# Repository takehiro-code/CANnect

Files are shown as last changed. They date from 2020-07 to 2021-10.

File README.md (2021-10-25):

# CANnect

Automotive diagnostic application developed as a part of engineering science 2020 capstone group croject. We built the application that diagnoses vehicle performance from On-board diagnostics-II (OBDII) port, and the mobile application displays the performance data with the Bluetooth connection from the hardware module. The dashboard on the mobile app processes the performance data and visualizes it in table, line chart, meter visualization, etc. in real-time. The performance data, which is OBDII parameter IDs (PIDs), includes engine coolant temperature, fuel pressure, engine RPM, vehicle speed, etc.

## System Overview
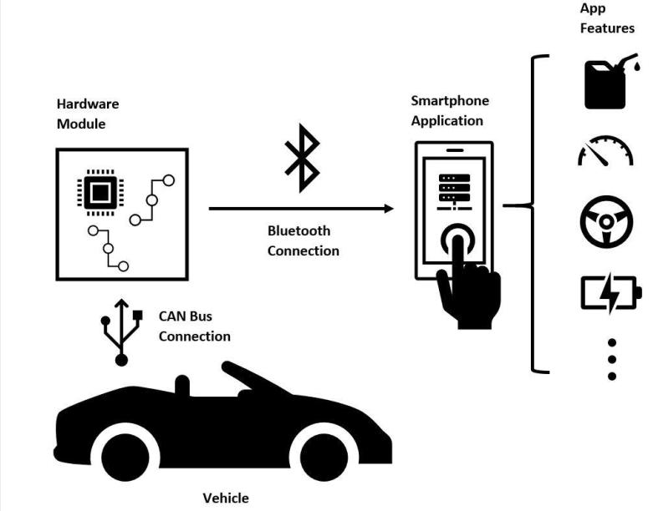
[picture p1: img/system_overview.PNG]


## Mobile App

We developed the mobile application with Android Studio, using Java and XML.

<div class="row">
  <div class="column">
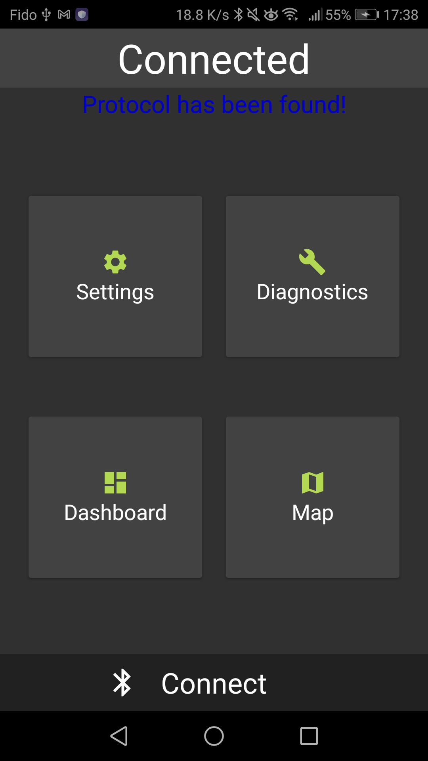
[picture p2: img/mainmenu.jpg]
    
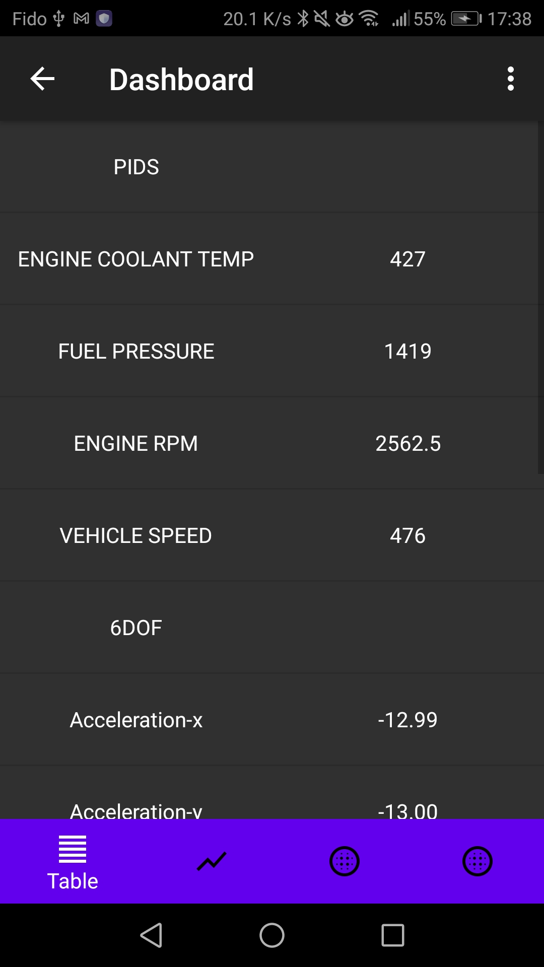
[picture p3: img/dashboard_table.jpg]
    
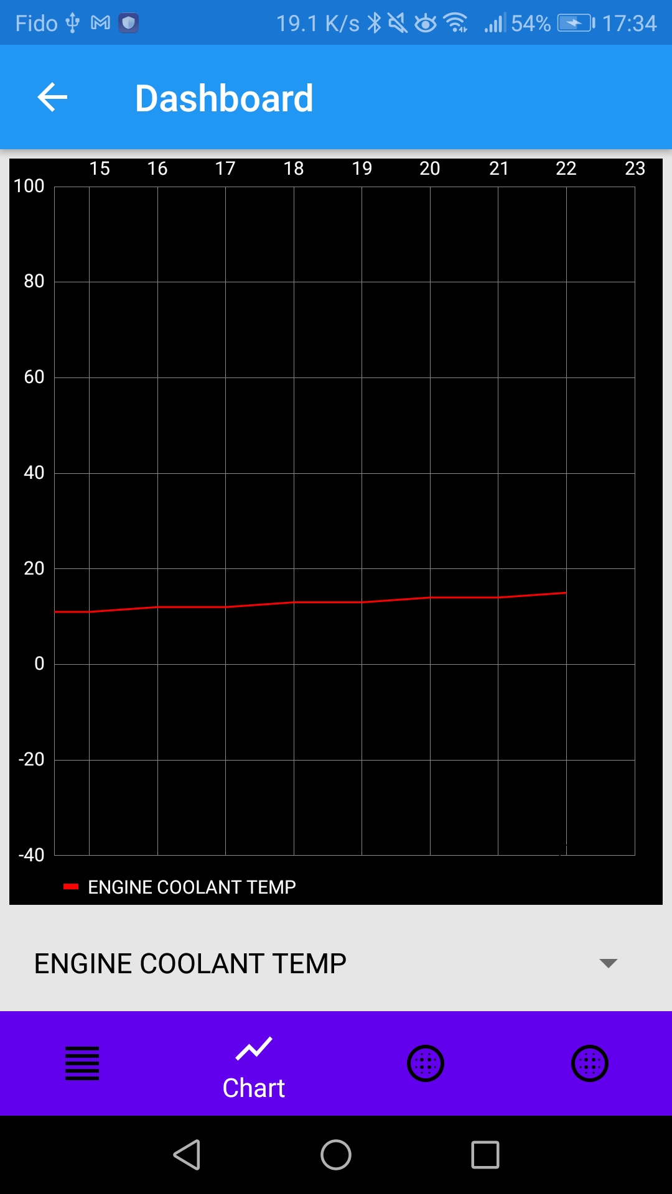
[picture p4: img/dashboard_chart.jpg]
    
  </div>
  <div class="column">
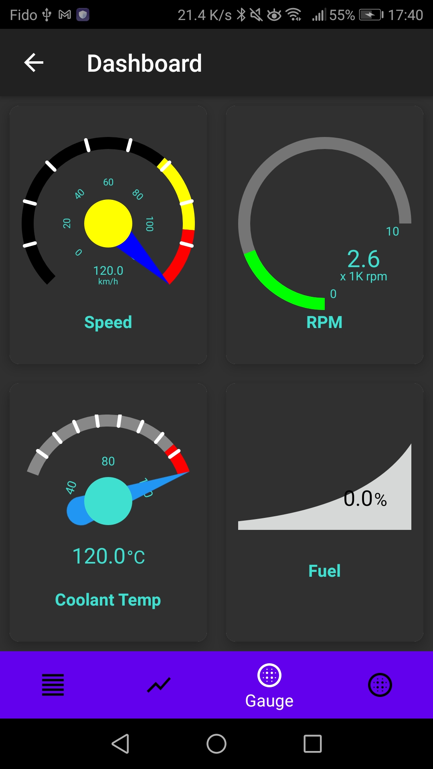
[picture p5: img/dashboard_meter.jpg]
    
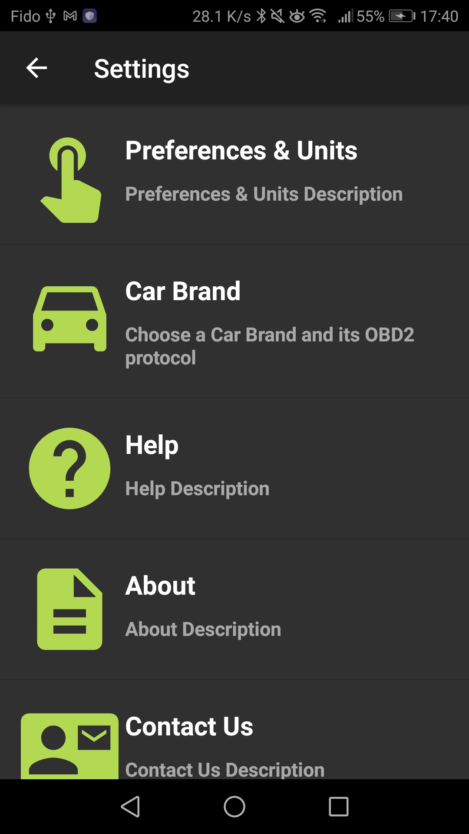
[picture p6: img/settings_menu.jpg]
    
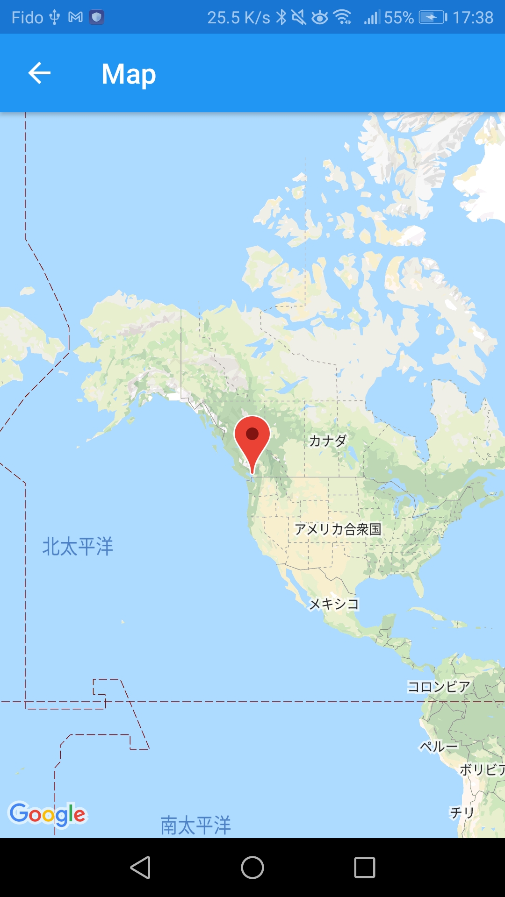
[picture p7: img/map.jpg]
    
  </div>
</div>

## Contributors

- Choong Jin Ng
- Enes Yazici
- Ranjoat Chana
- Win Aung
- Nicholas Lau
- Takehiro Tanaka

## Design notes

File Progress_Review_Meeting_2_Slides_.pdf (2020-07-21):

# Progress Review II

### Group 8:

### Choong Jin Ng Takehiro Tanaka Enes Yazici Win Aung Nicholas Lau

### Ranjoat Chana

### Project Lead App Design Engineer App Design Engineer Hardware Engineer Software Engineer

Systems Engineer,

### Communication Officer

# Agenda

Items for Discussion:
- Approval of the agenda and minutes of first progress review meeting held on June 10th, 2020 (1 min)
- Business arising from the minutes of the previous meeting (1 min)
- Clarification on OBD-II History (1 min)
- Introduction outlining basic review and any changes in scope (1 min)
- Progress, outlining completed research and planning (4 mins)
- Risk and remediations (1.5 mins)
- Summary of current state of project (0.5 min)
- Question period and follow-up discussion (10 mins)

# Approval of Minutes Progress Review Meeting I (June 10th, 2020)

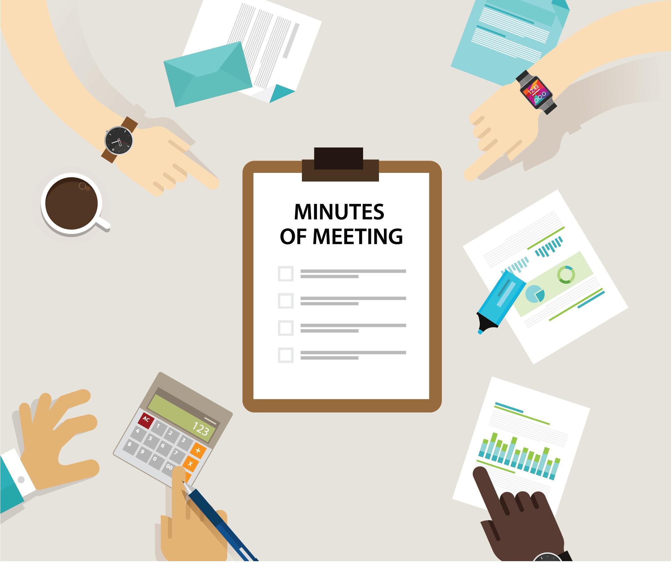
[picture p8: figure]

Revisions as per instructor feedback.

Access:

https://docs.google.com/document/d/11FIjHZPkfOvQZikw2MDsO0bJIYVXZhjqDZQs1nxVHB0/edit# (https://docs.google.com/document/d/11FIjHZPkfOvQZikw2MDsO0bJIYVXZhjqDZQs1nxVHB0/edit#)

# Changes to Previous Meeting Minutes

- Action items are highlighted
- New summary of action items
- Assigned action items to individuals to be held responsible
- The following comments made by participants corrected
- Creative commons licensing
- “Some internal companies”
- “Odometer” feature

# Business Arising

Action: Ranjoat will share a powerpoint with the team to collectively add slides for the next progress review meeting by July 6th (complete)

Action: Jin will verify that Evo car sharing does not block access to OBD-II port for purposes of testing by week of July 6th (complete)

*Action: Jin will research the licensing options for hardware and software by June 14th for requirements document

*Action: Nicholas will research and investigate options for protocols and supported extensions by week of July 6th for design document preparation

*Action: Ranjoat will research adding maintenance features and service updates based on odometer readings in software application by week of July 6th for design document preparation

*research based actions will be further discussed in Progress & Research section

# Clarification on OBD-II Maintenance

- OBD-II does not access actual vehicle’s odometer reading
- Privacy concerns
- Liability issues with mishandling
- Inaccurate
- Most cars that prompt their users to service their cars are not common
- Target audience usually ignores OEM’s scheduled maintenance
■ Too conservative or too generous
- We will not develop a feature that suggests a maintenance to the user

Reference: https://smartcar.com/blog/obd-mileage-verification/

# Clarification on OBD-II History

"CAN bus [...] was officially released in 1986 at the Society of Automotive Engineers (SAE) conference in Detroit, Michigan. [...] CAN bus is one of five protocols used in the on-board diagnostics (OBD)-II vehicle diagnostics standard. The OBD-II standard has been mandatory for all cars and light trucks sold in the United States since 1996. " - Wikipedia

This paragraph is misleading. Wikipedia’s ‘On-board diagnostics’ History implies a different history:

- 1996: The OBD-II specification is made mandatory for all cars sold in the United States.
- | 2008: All cars sold in the United States are required to use the | ISO 15765-4 (https://en.wikipedia.org/w/index.php?title=ISO_15765-4&action=edit&redlink=1)[5] (https://en.wikipedia.org/wiki/On-board_diagnostics#cite_note-5) | signaling standard (a variant of the
Controller Area Network (https://en.wikipedia.org/wiki/Controller_Area_Network) | (CAN) bus). (https://en.wikipedia.org/wiki/Bus_(computing))

Reference: https://en.wikipedia.org/wiki/On-board_diagnostics#History

# Clarification on OBD-II History

- Although CAN was originally developed for passengers cars, CAN was first applied to other systems first (elevators, textile machines, X-ray machine, etc.)
- Most first applications, including cars, were done in Europe
- Although CAN was introduced by Bosch in Feb 1996, there were many problems (errors, incompleteness, political disputes, etc)
- ISO 15765-4 (i.e CAN BUS) was formally specified in 2005.
- All cars manufactured after 2008 in North America should only use CAN (ISO 15765-4)
- When we refer to ‘CAN BUS Reader’, we are talking about an OBD-II reader that works on cars after 2008

Reference:

https://www.can-cia.org/can-knowledge/can/can-history/

https://www.iso.org/standard/33619.html

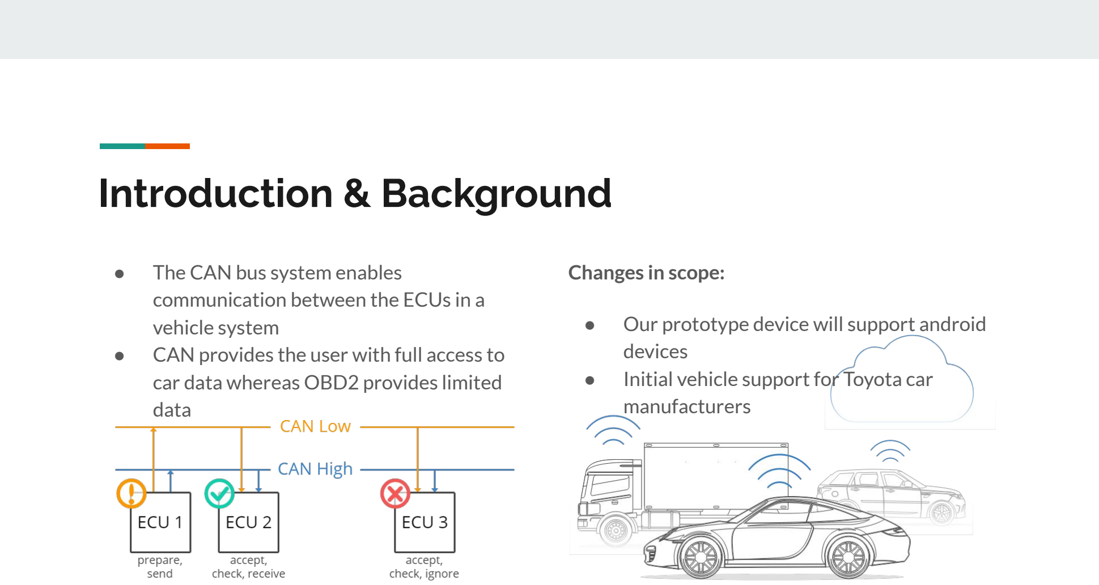
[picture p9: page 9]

# Introduction & Background

- The CAN bus system enables
communication between the ECUs in a vehicle system
- CAN provides the user with full access to car data whereas OBD2 provides limited data

Changes in scope:

- Our prototype device will support android devices
- Initial vehicle support for Toyota car manufacturers

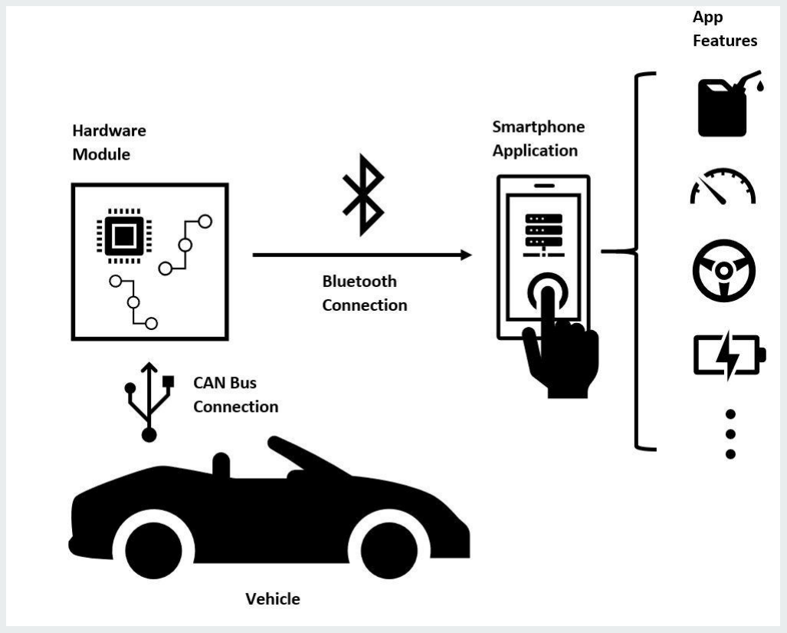
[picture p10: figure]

-Our CANBus reader is designed to connect to the OBD-II port in a vehicle

-The hardware module is comprised of a microcontroller and Bluetooth adapter to process and transmit data from the vehicle CAN bus system (CAN low, CAN high ) to the user’s android device

-The smart phone app will allow the user to read DTCs and live sensor data such as oil temperature, engine speed, GPS, fuel rate and speed, etc.

# System Overview

# Progress & Research - Hardware

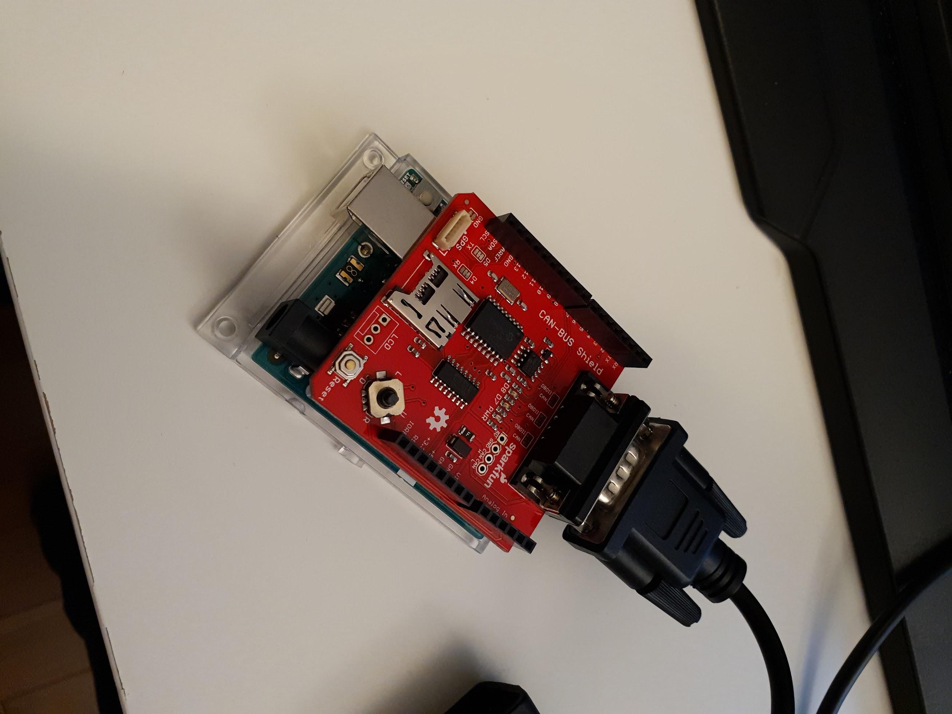
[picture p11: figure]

- Arduino Uno with SparkFun CAN BUS Shield
- Using SparkFun’s internal libraries
- Example code is a useful jumping ground for a Proof-of-Concept
- Connect the CAN BUS Shield to a OBD-II port using a DB9 to OBD-II connector

# Progress & Research - Data Sample

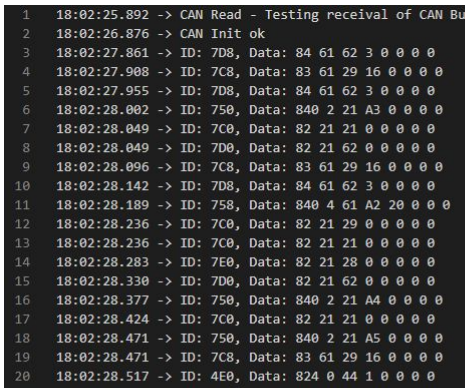
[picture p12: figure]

- Data sample from Toyota Prius (Evo car sharing) using demo code
- Able to read data frames that are sent to the Arduino
- Suspect that not all possible messages are not being read because example code does not request for them

# Progress & Research - Data Sample

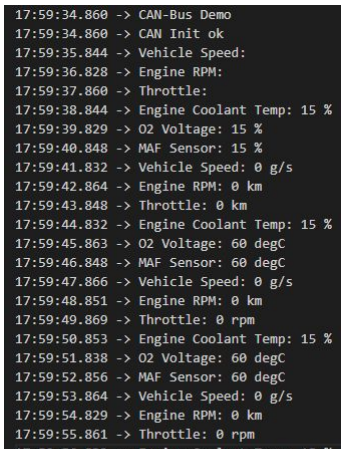
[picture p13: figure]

- Another data sample from Toyota Prius (Evo car sharing) using demo code
- Code requests for
- Vehicle Speed
- Engine RPM
- Throttle
- Engine Coolant Temp
- O2 Voltage
- MAF Sensor
- Promising though highlights the needs to check the data’s validity before displaying

# Progress & Research - Evo Car Sharing

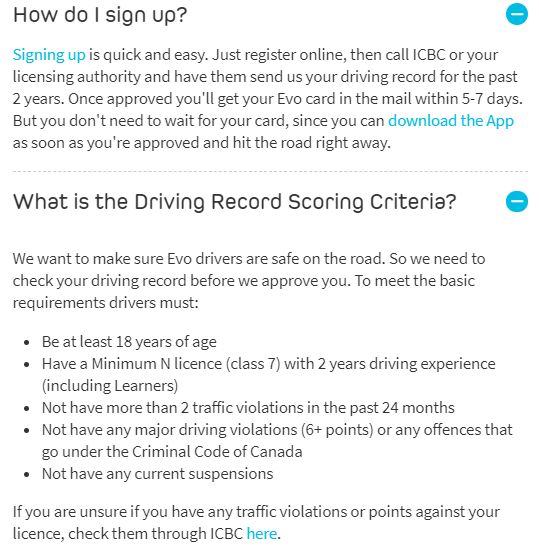
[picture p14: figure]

- Advantages
- Able to test on a standardised car
■ Toyota Prius
- Available through the Lower Mainland
- Low operating rates
- Disadvantages
- Need a valid driving license (Class 7 or N at minimum)
- Need to have 2 years of driving experience
- Not convenient for bursts of development and testing
- Alternative solution (CAN BUS Simulator) is more convenient

# Progress & Research - Protocols

Research - Protocols (CANBUS)

The listed ISO standard is the intended focus protocol for CANBUS

- ISO 15765-4 - Emissions and external data access (Diagnostic Communication over CAN)
- ISO 11898 series- Physical and Data Link Layers (frame format)
■ | Part 1 - Physical and Data Link Layer
■ | Part 2 - High Speed Transmission
- ISO 15765-2 - Network and Transport Layer
- Also implemented in ISO 27145-4 for WWH-OBD

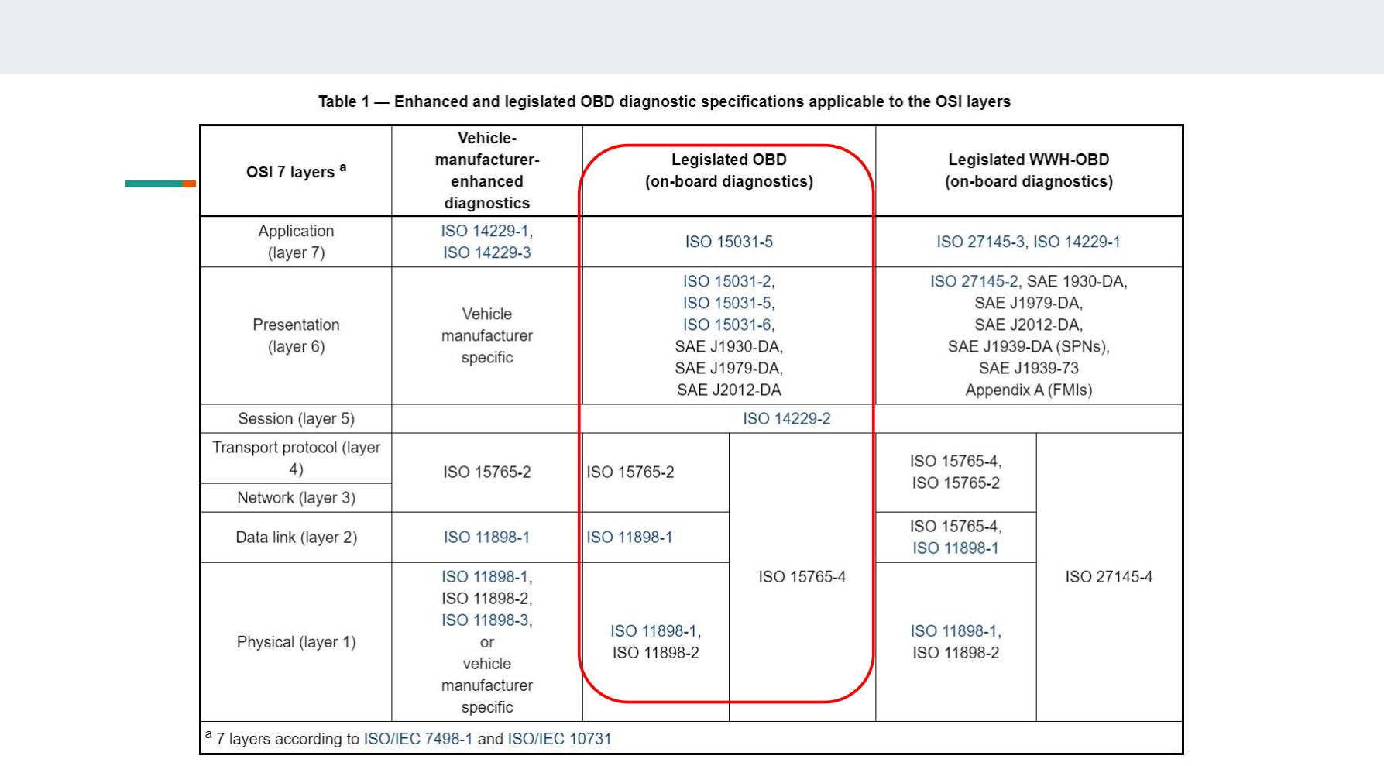
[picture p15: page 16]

# Progress & Research - CAN Data

Research - CAN IDs and Messages

Depending on car, messages are either read automatically in intervals or must be requested manually

Identified different ways to decode CAN message format since it proprietary to Original Equipment manufacturer (OEM):

- Reverse Engineer
- Perform different actions on car to see which IDs correlate to a specific function
- Tedious and time consuming
- Look-up CAN IDs
- Identified a subset of IDs for Toyota cars (eg. vehicle speed, RPM)
- Fast and convenient

# Progress & Research - Data

CAN - Raw Data Sample and Translation

ID: 610, Data: 820 0 0 64 C2 0 0 0

HEX 610 - Vehicle Speed

HEX 0 (Byte 3) - 0 km/h

ID: 63B, Data: 816 0 43 4E 0 0 2 7F

Unknown, Need further research or reverse engineering

# Progress & Research - Bluetooth

### Bluetooth Modules

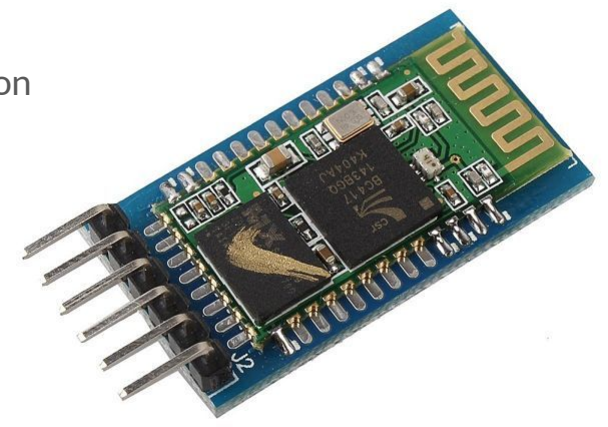
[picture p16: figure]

- HC-05 -based on Bluetooth 2.0 and offers master/slave configuration
- HC-06 -based on Bluetooth 2.0 and offers only slave configuration
- Both HC-05 and HC-06 are compatible with android devices only
- HM-10/HM-11 -based on Bluetooth 4.0 BLE
- compatible with iphone and android 4.3+
- intended for low power consumption applications

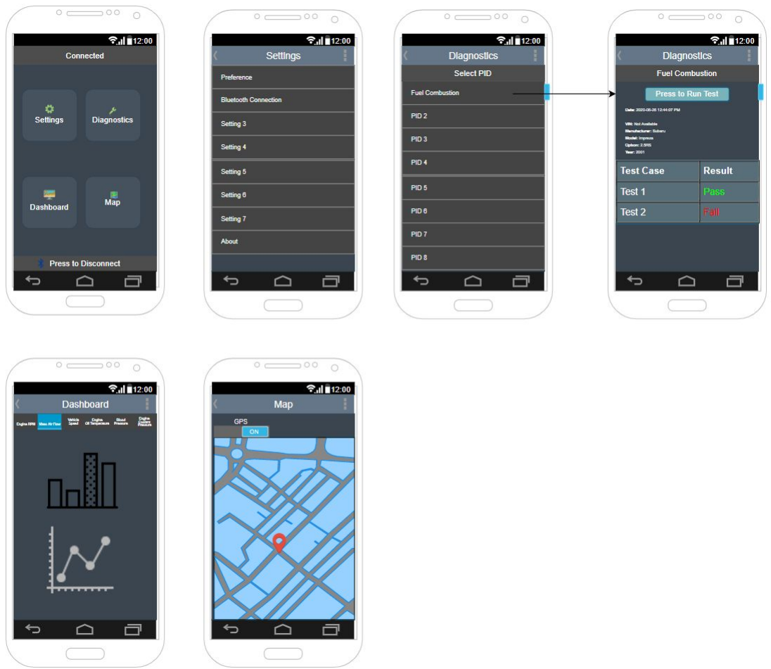
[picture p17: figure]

# Progress & Research - App

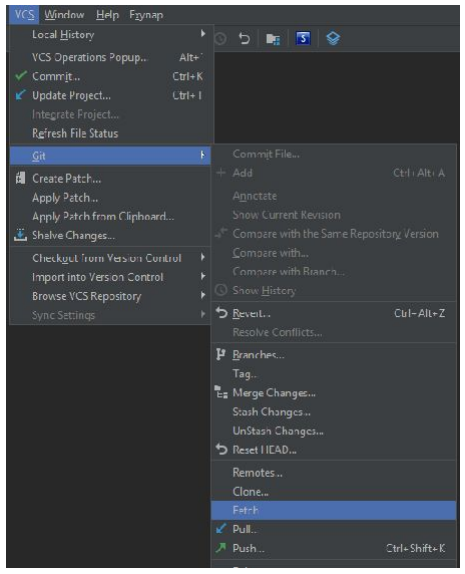
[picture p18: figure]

# Progress & Research - App

### App Planning

- Android Studio
- XML, Java, Git
- Test on different devices (e.g. Screen)
- Physical device
- Virtual device (Emulator)

# Progress & Research - App

### Design Choices

- Easy to use (no difficult learning curve for users)
- Seperate tabs makes development easier
- Separate XML activities and Java classes(no dependency between different functionalities)
- More organized

### Colour & Image Choices

- Do not use a colour that is too bright
- May hurt eyes & Annoying
- Use common color and icon associations (green for connect, red for disconnect etc.)

# Progress & Research - App

### Software App Progress

- Currently
- Converting sketches to app ui
- Built the app basic display (main screen only)
- Working on the logical components
- Enabling bluetooth, searching devices, pairing devices etc.
- Next steps
- Attach to arduino to receive data
- Parse the data
- Implement Individual UI components ( dashboard, chart, map etc)

# Risk and Remediation - Scheduling

- To aid scheduling
- Planning to meet up in person for hardware setup of prototype design
- Regular meetings and discussion over online
- Reallocate resources as required for hardware and software component

# Risk and Remediation - CAN BUS Simulator

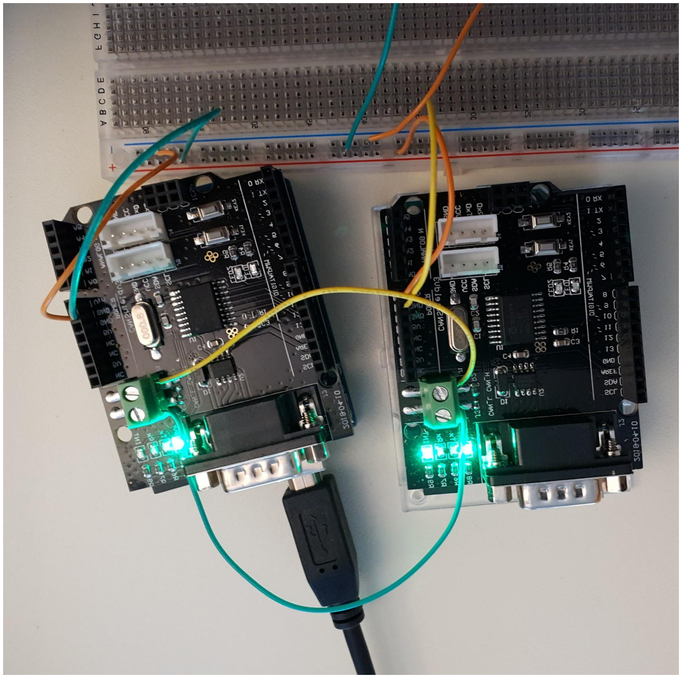
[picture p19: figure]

- Use another Arduino and CAN BUS Shield to act as a “car simulator”
- CAN-High connects to CAN-High, and CAN-Low connects to CAN-low
- Run a pre-defined script that simulates how the car’s internal CAN BUS system works
- Sends the appropriate messages to the reader when requested

# Risk and Remediation - CAN BUS Simulator

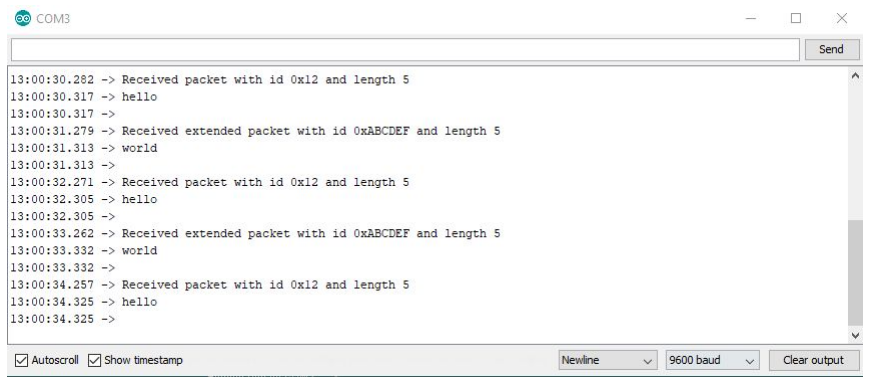
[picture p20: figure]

- Sender sends the string ‘hello’ and ‘world’ to the reader
- Reader simply prints the packet’s contents to serial
- Future work will enable those who do not have cars to work at home
- Also able to have repeatable verification tests

# Risk and Remediation - Licensing

- Hardware and related documents falls under CERN Open Hardware License Version 2 -Permissive
- Referred to as CERN-OHL-P
- Only applies to hardware and its associated documentation
- Software and related documents falls under MIT License
- Goal of this product is to make working on your car easier, not necessarily to turn a profit
- Customers prefer to stick with official vendors and active customer support

# Summary

Current State:

- Arduino CAN bus shield and demo code has allowed for successful connection to test vehicles to extract data frame samples
- Basic app components and main screen options determined
- Familiarized with the protocols and standards (incl. licensing) for our prototype design
- Determined best practice to verify our product using a simulator
- Evo car sharing is an option

# Summary

Next Steps:

- Working towards finalizing the UI design and functionality
- Establish a connection with the android phone via selected bluetooth module
- Ensure app is correctly mapping data samples to selected features for prototype design stage

# Questions?

# Thank You

# Appendix: Clarification on OBD-II History

- A (modern) OBD-II vehicle uses the five communication protocols:
- SAE J1850 PWM
- SAE J1850 VPW
- ISO 9141-2
- ISO 14230-4
- ISO 15765-4/SAE J2480 (since 2003) - i.e CAN

Reference: http://www.obdtester.com/obd2_protocols

# Appendix: Clarification on OBD-II History

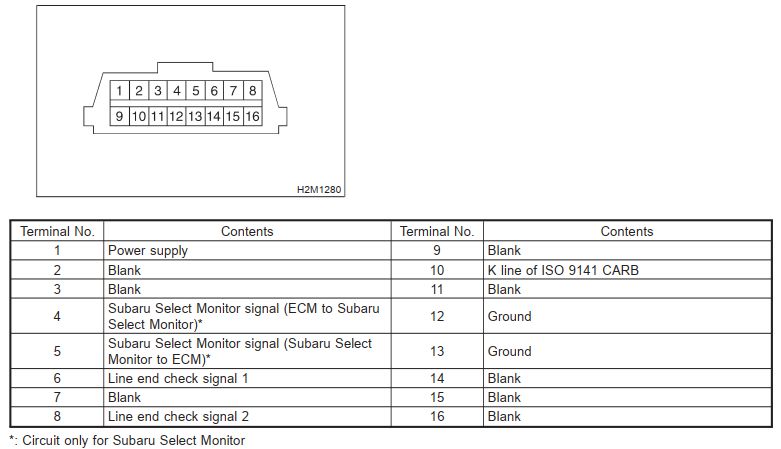
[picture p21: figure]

- Even then, not every car uses all five communication
protocols
- This OBD-II diagram is taken from a service manual for a Subaru Impreza 1996-2001
sold in North America
- Note that only ODB- II’s ISO 9141 is used
- Data collected by an OBD-II reader is slower than CAN
BUS

# Appendix: Progress & Research - Protocols

Research - Protocols (CANBUS)

Additional listed ISO standards are of focus for OBD2 PID-related data

- ISO 14229-2 - Session Layer (Unified Diagnostic Services)
- ISO 15031-2, -5, -6 - Application and Presentation Layer
- Part 2 - Definitions and Terms
- Part 5 - Emissions Diagnostic Services (OBD2 PIDs)
- Part 6 - Diagnostic Trouble Codes
- Based on SAE J1930-DA, J1979-DA and J2012-DA OBD

# Appendix: Progress & Research - Protocols

The International Organization for Standardization, "ISO 15765-4:2016(en), Road vehicles — Diagnostic communication over Controller Area Network (DoCAN) — Part 4: Requirements for emissions-related systems," 2016. [Online]. Available: https://www.iso.org/obp/ui/#iso:std:iso:15765:-4:ed-3:v1:en. [Accessed 2 July 2020].

- Intended network stack is the legislated OBD
- Additional manufacturer specific codes will need to be identified

# Appendix: Progress & Research - OBD-II

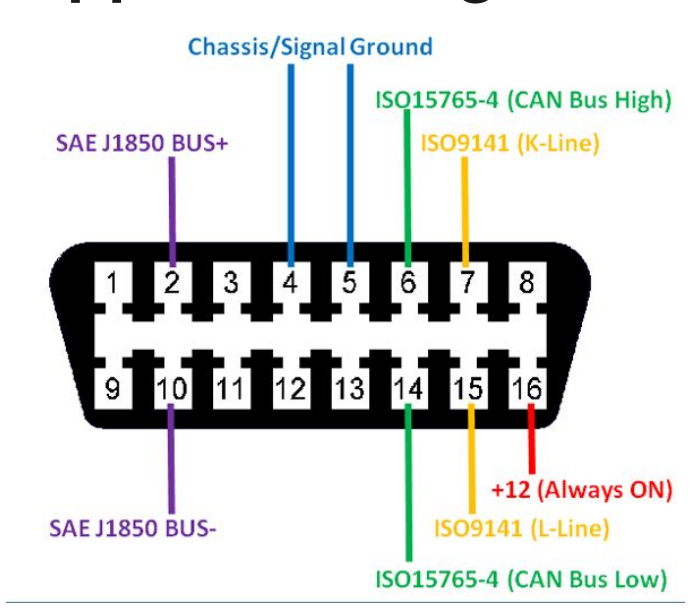
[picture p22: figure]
Connector

- The important data lines we will use are pins 6 and 14 (CAN High and CAN Low respectively)
- We will also use Pins 12 and 4 to power the reader
- Pin 4 and 5 is Chassis and Signal Ground respectively

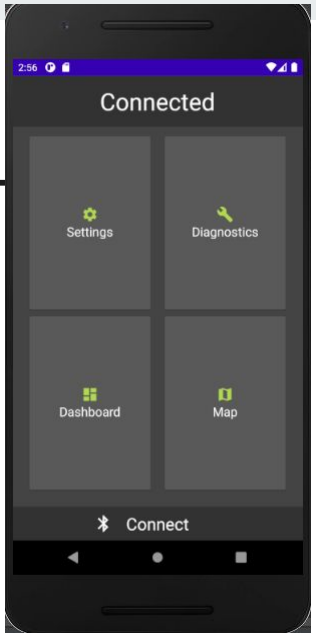
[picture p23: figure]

# Appendix: Progress & Research - App

### Current version of the app

- Status bar on the top
- Logic needs to be added
- Connection bar on the bottom
- Logic needs to be added
- Card view layout implemented
- Needs to be adjusted (padding etc.)
- Logic needs to be added

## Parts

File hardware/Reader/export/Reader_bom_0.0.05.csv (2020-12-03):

Component | Description | Part | References | Value | Footprint | Quantity Per PCB | Datasheet | Vendor | Part Name | digikeypn | Manufacturer | Comments | Field4 | Field6 | Field5
1 | Unpolarized capacitor | C | C_STN_2 C_STN_3 | 30pF | CAPC1608X90N | 2 | https://content.kemet.com/datasheets/KEM_C1007_X8R_ULTRA_150C_SMD.pdf | DigiKey Canada | C0603C300J5GACTU | 399-9057-1-ND | Kermet
2 | Unpolarized capacitor | C | C_HSCAN_1 C_HSCAN_2 | 560pF | CAPC1608X90 | 2 | https://www.yageo.com/upload/media/product/productsearch/datasheet/mlcc/UPY-GPHC_X7R_6.3V-to-50V_18.pdf | DigiKey Canada | CC0603JRX7R9BB561 | 311-4020-1-ND‎ | Yageo
3 | Unpolarized capacitor | C | C_ESP_1 C_ESP_2 C_J1850_1 C_VR1_2 C_VR2_2 C_VS_1 | 0.1uF | CAPC1608X90 | 6 | https://www.yageo.com/upload/media/product/productsearch/datasheet/mlcc/UPY-GPHC_X7R_6.3V-to-50V_18.pdf | DigiKey Canada | CC0603JRX7R8BB104 | 311-1777-1-ND | Yageo
4 | Unpolarized capacitor | C | C_IMU_1 C_IMU_2 | 100nF | CAPC1608X90N | 2 | https://product.tdk.com/info/en/catalog/datasheets/mlcc_commercial_midvoltage_en.pdf | DigiKey Canada | C1608X7R2A103K080AA | 445-1304-1-ND | TDK Corporation
5 | Unpolarized capacitor | C | C_HSCAN_3 C_STN_1 C_STN_4 C_STN_5 C_STN_6 C_VR1_3 C_VR2_3 | 1uF | 0603 | 7 | https://content.kemet.com/datasheets/KEM_C1002_X7R_SMD.pdf | DigiKey Canada | C0603C105K4RACTU | 399-7847-1-ND | Kermet
6 | Unpolarized capacitor | C | C_PS_1 C_PS_2 C_PS_3 C_VR1_1 C_VR2_1 | 4.7uF | C1206C475K3RACAUTO | 5 | https://api.kemet.com/component-edge/download/specsheet/C1206C475K3RACAUTO.pdf | DigiKey Canada | C1206C475K3RACAUTO | 399-7029-1-ND | Kermet
7 | Polarized capacitor | CP | CP_ESP_1 | 100uF | UCB0J101MCL1GS | 1 | https://www.nichicon.co.jp/english/products/pdfs/e-ucb.pdf | DigiKey Canada | UCB0J101MCL1GS | 493-9357-1-ND | Nichicon
8 | Polarized capacitor | CP | CP_STN_1 | 10uF | CP_Elec_4x5.8 | 1 | https://industrial.panasonic.com/ww/products/capacitors/aluminum-capacitors/aluminum-cap-smd/models/EEEFP1E100AR | DigiKey Canada | EEEFP1E100AR | PCE4539CT-ND | Panasonic Electronic Components | ESR<1
9 | 100V 0.15A Small Signal Schottky Diode, DO-35 | BAT46 | D_J1850_1 D_J1850_2 D_J1850_3 D_VS_1 D_VS_2 | BAT46JFILM | BAT46JFILM | 5 | https://www.st.com/content/ccc/resource/technical/document/datasheet/c6/32/d4/4a/28/d3/4b/11/CD00004930.pdf/files/CD00004930.pdf/jcr:content/translations/en.C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 | DigiKey Canada | BAT46JFILM | 497-6653-1-ND | STMicroelectronics
10 |  | MMBZ27VALT3G | D_ESD_4 D_ESD_5 | MMBZ27VALT3G | SOT95P237X111-3N | 2 | https://www.onsemi.com/pub/Collateral/MMBZ5V6ALT1-D.PDF | DigiKey Canada | MMBZ27VALT3G | MMBZ27VALT3GOSCT-ND | ON Semiconductor |  | 20 | ON Semiconductor | IPC-7351B
11 |  | MMBZ27VCLFHT116 | D_ESD_3 | MMBZ27VCLFHT116 | MMBZ27VCLFHT116 | 1 | http://rohmfs.rohm.com/en/products/databook/datasheet/discrete/diode/zener/mmbz27vclfht116-e.pdf | DigiKey Canada | MMBZ27VCLFHT116 | MMBZ27VCLFHT116CT-ND | Rohm Semiconductor
12 |  | PESD2CAN,215 | D_ESD_1 D_ESD_2 | PESD2CAN,215 | SOT95P230X110-3N | 2 | https://assets.nexperia.com/documents/data-sheet/PESD2CAN.pdf | DigiKey Canada | PESD2CAN,215 | 1727-3891-1-ND | Nexperia USA Inc.
13 |  | 4157 | J_CN_1 J_ESP_1 J_ESP_2 | 4157 | PinSocket_1x20_P2.54mm_Vertical | 3 | https://media.digikey.com/pdf/Data%20Sheets/Adafruit%20PDFs/4157_Web.pdf | DigiKey Canada | 4157 | 1528-2929-ND | Adafruit Industries LLC
14 |  | Header_Pin_2 | J_STN_1 J_STN_2 J_STN_4 J_STN_5 J_STN_6 | Header_Pin_2 | PinHeader_1x02_P2.54mm_Vertical | 5
15 |  | Header_Pin_8 | J_ESP_3 J_PS_1 | Header_Pin_8 | PinHeader_1x08_P2.54mm_Vertical | 2
16 | Inductor | L | L_VR1 L_VR2 | 4.7uH | CV201210-4R7K | 2 | https://www.bourns.com/docs/Product-Datasheets/CV201210.pdf | DigiKey Canada | CV201210-4R7K | CV201210-4R7KCT-ND | Bourns Inc.
17 | Light emitting diode | LED | LED_ESP_1 | Bluetooth Status | LED_0603_1608Metric | 1 | https://www.we-online.de/katalog/datasheet/150060VS75000.pdf | DigiKey Canada | 150060VS75000 | 732-4980-1-ND | Würth Elektronik
18 | Light emitting diode | LED | LED_STN_3 | Host Activity | LED_0603_1608Metric | 1 | https://www.we-online.de/katalog/datasheet/150060VS75000.pdf | DigiKey Canada | 150060VS75000 | 732-4980-1-ND | Würth Elektronik
19 | Light emitting diode | LED | LED_STN_2 | OBD Activity | LED_0603_1608Metric | 1 | https://katalog.we-online.de/led/datasheet/150060YS75000.pdf | DigiKey Canada | 150060YS75000 | 732-4981-1-ND | Würth Elektronik
20 | Light emitting diode | LED | LED_STN_1 | Status | LED_0603_1608Metric | 1 | https://katalog.we-online.de/led/datasheet/150060RS75000.pdf | DigiKey Canada | 150060RS75000 | 732-4978-1-ND | Würth Elektronik
21 |  | IRLML5103TRPBF | Q_ISO_1 Q_ISO_2 | IRLML5103TRPBF | IRLML5103TRPBF | 2 | https://www.infineon.com/dgdl/irlml5103pbf.pdf?fileId=5546d462533600a401535668505d2617 | DigiKey Canada | IRLML5103TRPBF | IRLML5103PBFCT-ND | Infineon Technologies
22 | 0.2A Ic, 40V Vce, Small Signal NPN Transistor, SOT-23 | MMBT3904 | Q_ISO_3 Q_ISO_4 | MMBT3904WT1G | SOT-23 | 2 | https://www.onsemi.com/pub/Collateral/MMBT3904WT1-D.PDF | DigiKey Canada | MMBT3904WT1G | MMBT3904WT1GOSCT-ND | ON Semiconductor
23 |  | NX7002AK,215 | Q_HSCAN_1 Q_J1850_1 Q_J1850_2 Q_J1850_4 Q_PS_1 | NX7002AK,215 | SOT95P230X110-3N | 5 | https://assets.nexperia.com/documents/data-sheet/NX7002AK.pdf | DigiKey Canada | NX7002AK,215 | 1727-1289-1-ND | Nexperia USA Inc. |  | Nexperia | IPC-7351B | 7
24 |  | IRLML5103TRPBF | Q_PS_2 Q_PS_3 Q_PS_4 | NX7002AK,215 | SOT95P230X110-3N | 3 | https://assets.nexperia.com/documents/data-sheet/NX7002AK.pdf | DigiKey Canada | NX7002AK,215 | 1727-1289-1-ND | Nexperia USA Inc.
25 |  | RSC002P03T316 | Q_J1850_3 | RSC002P03T316 | RSC002P03T316 | 1 | http://rohmfs.rohm.com/en/products/databook/datasheet/discrete/transistor/mosfet/rsc002p03-e.pdf | DigiKey Canada | RSC002P03T316 | RSC002P03T316CT-ND | Rohm Semiconductor
26 | Resistor | R | R_STN_12 | 10 | RESC1608X55N | 1 | https://www.yageo.com/upload/media/product/productsearch/datasheet/rchip/PYu-RE_105_RoHS_L_6.pdf | DigiKey Canada | RE0603FRE0710RL | 13-RE0603FRE0710RLCT-ND | Yageo
27 | Resistor, small symbol | R_Small | R_HSCAN_2 R_HSCAN_3 | 100 | RESC3216X70N | 2 | https://industrial.panasonic.com/cdbs/www-data/pdf/RDA0000/AOA0000C304.pdf | DigiKey Canada | ERJ-8ENF1000V | P100FCT-ND | Panasonic Electronic Components
28 | Resistor, small symbol | R_Small | R_J1850_6 | 240 | RESC3216X70N | 1 | https://industrial.panasonic.com/cdbs/www-data/pdf/RDA0000/AOA0000C304.pdf | DigiKey Canada | ERJ-8ENF2400V | P240FCT-ND | Panasonic Electronic Components
29 | Resistor, small symbol | R_Small | R_STN_1 R_STN_2 R_STN_3 | 330 | RESC3216X70N | 3 | https://industrial.panasonic.com/cdbs/www-data/pdf/RDA0000/AOA0000C304.pdf | DigiKey Canada | ERJ-8ENF3300V | P330FCT-ND | Panasonic Electronic Components
30 | Resistor, small symbol | R_Small | R_J1850_4 | 374 | RESC3216X70N | 1 | https://industrial.panasonic.com/cdbs/www-data/pdf/RDA0000/AOA0000C304.pdf | DigiKey Canada | ERJ-8ENF3740V | P374FCT-ND | Panasonic Electronic Components
31 | Resistor, small symbol | R_Small | R_ESP_2 R_ESP_3 R_ESP_5 R_STN_10 | 500 | RESC1508X55N | 4 | https://www.vishay.com/docs/28916/mcxhp.pdf | DigiKey Canada | MCT0603PD4990DP500 | 749-1523-1-ND | Vishay
32 | Resistor, small symbol | R_Small | R_J1850_3 | 866 | RESC3216X70N | 1 | https://industrial.panasonic.com/cdbs/www-data/pdf/RDA0000/AOA0000C304.pdf | DigiKey Canada | ERJ-8ENF8660V | P866FCT-ND | Panasonic Electronic Components
33 | Resistor, small symbol | R_Small | R_ISO_1 R_ISO_2 R_STN_4 | 1k | RC1608F102CS | 3 | https://media.digikey.com/pdf/Data%20Sheets/Samsung%20PDFs/RC_Series_ds.pdf | DigiKey Canada | RC1608F102CS | 1276-3484-1-ND | Samsung Electro-Mechanics
34 | Resistor, small symbol | R_Small | R_J1850_2 R_STN_7 R_STN_8 | 1.5k | RESC1607X60N | 3 | https://www.yageo.com/upload/media/product/productsearch/datasheet/rchip/PYu-RC_Group_51_RoHS_L_11.pdf | DigiKey Canada | RC0603FR-071K5L | 311-1.50KHRCT-ND | Yageo
35 | Resistor, small symbol | R_Small | R_COMP_8 | 2.7k | RESC1608X55N | 1 | https://www.vishay.com/docs/28773/crcwce3.pdf | DigiKey Canada | CRCW06032K70FKEAC | 541-5328-1-ND | Vishay Dale
36 | Resistor, small symbol | R_Small | R_IMU_1 R_IMU_2 | 4.7k | RESC1608X55N | 2 | https://www.yageo.com/upload/media/product/productsearch/datasheet/rchip/PYu-RT_1-to-0.01_RoHS_L_12.pdf | DigiKey Canada | RT0603DRD074K7L | 311-4.7KDCT-ND | Yageo
37 | Resistor, small symbol | R_Small | R_COMP_1 R_COMP_2 R_COMP_3 R_COMP_4 R_COMP_5 R_COMP_6 R_COMP_7 R_COMP_9 R_COMP_10 R_COMP_11 R_ESP_1 R_ESP_4 R_J1850_1 R_J1850_5 R_J1850_7 R_J1850_8 R_STN_11 R_VS_2 | 10k | RESC1608X55N | 18 | https://www.yageo.com/upload/media/product/productsearch/datasheet/rchip/PYu-RT_1-to-0.01_RoHS_L_12.pdf | DigiKey Canada | RT0603FRE0710KL | YAG2321CT-ND | Yageo
38 | Resistor, small symbol | R_Small | R_VS_1 | 62k | RESC2012X60N | 1 | https://www.yageo.com/upload/media/product/productsearch/datasheet/rchip/PYu-RT_1-to-0.01_RoHS_L_12.pdf | DigiKey Canada | RT0805FRE0762KL | 13-RT0805FRE0762KLCT-ND | Yageo
39 | Resistor, small symbol | R_Small | R_HSCAN_1 R_PS_1 R_PS_2 R_STN_5 R_STN_6 R_STN_9 R_STN_13 R_VR2_1 R_VR2_2 | 100k | RESC1608X55N | 9 | https://www.yageo.com/upload/media/product/productsearch/datasheet/rchip/PYu-RT_1-to-0.01_RoHS_L_12.pdf | DigiKey Canada | RT0603DRE07100KL | 311-2395-1-ND | Yageo
40 | Resistor, small symbol | R_Small | R_VR2_3 | 115k | RESC1608X55N | 1 | https://www.yageo.com/upload/media/product/productsearch/datasheet/rchip/PYu-RT_1-to-0.01_RoHS_L_12.pdf | DigiKey Canada | RT0402DRE07115KL | 311-2218-1-ND | Yageo
41 | Resistor, small symbol | R_Small | R_ISO_3 R_ISO_4 | 510k | RESC2012X50N | 2 | https://www.susumu.co.jp/common/pdf/n_catalog_partition05_en.pdf | DigiKey Canada | RR1220P-514-D | RR12P510KDCT-ND | Susumu
42 |  | PTS647SK38SMTR2LFS | SW_ESP_1 SW_ESP_2 SW_STN_1 | PTS647SK38SMTR2LFS | PTS647SK38SMTR2LFS | 3 | https://www.ckswitches.com/media/2567/pts647.pdf | DigiKey Canada | PTS 647 SK38 SMTR2 LFS | PTS647SK38SMTR2LFSCT-ND | C&K
43 |  | AHDF15A-KG-TAXB | U_CN_1 | AHDF15A-KG-TAXB | AHDF15A-KG-TAXB | 1 | http://www.assmann-wsw.com/fileadmin/datasheets/AHDxxxA-KG-TAxB.pdf | DigiKey Canada | AHDF15A-KG-TAXB | AE11024-ND | Assmann WSW Components
44 | RF Module, ESP32-D0WD SoC, Wi-Fi 802.11b/g/n, Bluetooth, BLE, 32-bit, 2.7-3.6V, onboard antenna, SMD | ESP32-WROOM-32D | U_ESP_1 | ESP32-WROOM-32D | CANtech-ESP32-WROOM-32 | 1 | https://www.espressif.com/sites/default/files/documentation/esp32-wroom-32d_esp32-wroom-32u_datasheet_en.pdf | DigiKey Canada | USB4110-GF-A | 1965-ESP32-WROOM-32D(4MB)CT-ND | Espressif Systems
45 |  | LM317LDR2G | U_J1850_1 | LM317LDR2G | SOIC127P600X175-8N | 1 | https://www.onsemi.com/pub/Collateral/LM317L-D.PDF | DigiKey Canada | LM317LDR2G | LM317LDR2GOSCT-ND | ON Semiconductor
46 |  | LM339N_NOPB | U_COMP_1 | LM339N_NOPB | LM339N&slash_NOPB | 1 | https://www.ti.com/lit/ds/symlink/lm339-n.pdf?ts=1603731355059 | DigiKey Canada | LM339N_NOPB | 296-39010-5-ND | Texas Instruments
47 |  | LSM6DSMTR | U_IMU_1 | LSM6DSMTR | PQFN50P300X250X86-14N | 1 | https://www.st.com/content/ccc/resource/technical/document/datasheet/76/27/cf/88/c5/03/42/6b/DM00218116.pdf/files/DM00218116.pdf/jcr:content/translations/en.D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 | DigiKey Canada | LSM6DSMTR | 497-16696-1-ND | STMicroelectronics |  | 0.86 mm | IPC 7351B | Rev 7
48 |  | MAX25276ATCA_VY+ | U_VR1 U_VR2 | MAX25276ATCA_VY+ | MAX25276ATCA&slash_VY&plus_ | 2 | https://datasheets.maximintegrated.com/en/ds/MAX20075-MAX25276.pdf | DigiKey Canada | MAX25276ATCA/VY+ | 175-MAX25276ATCA/VY+-ND | Maxim Integrated
49 |  | MCP2562-H_MF | U_HSCAN_1 | MCP2562-H_MF | MCP2562-H&slash_MF | 1 | https://ww1.microchip.com/downloads/en/DeviceDoc/20005167C.pdf | DigiKey Canada | MCP2562-H_MF | MCP2562-H/MF-ND | Microchip Technology
50 | OBDII-to-UART Interpreter | STN2120 | U_STN_1 | STN2120 | CANtech-STN2120-QFN-44-1EP_8x8mm | 1 | https://www.scantool.net/scantool/downloads/206/stn21xx_ds_c.pdf | OBD Solutions | STN2120 |  | OBD Solutions
51 |  | ECS-2033-160-AU | Y_STN_1 | ECS-2033-160-AU (16MHz) | OSC_ECS-2033-160-AU | 1 | https://ecsxtal.com/store/pdf/ecs-2025-2033.pdf | DigiKey Canada | ECS-2033-160-AU (16MHz) | XC1858CT-ND | ECS Inc. |  | 11/15/13 |  | Manufacturer Recommendations
Component Groups: | 51
Component Count: | 131
Fitted Components: | 131
Number of PCBs: | 1
Total components: | 131
Schematic Version: | 0.0.05
Schematic Date: | 2020-11-29
PCB Variant: | [u'default']
BoM Date: | 12/02/20 16:09:37
Schematic Source: | Reader.sch
KiCad Version: | Eeschema (5.1.7)-1

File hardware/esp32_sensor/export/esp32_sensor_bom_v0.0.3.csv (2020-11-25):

Component | Description | Part | References | Value | Footprint | Quantity Per PCB | Datasheet | Vendor | Vendor Part Name | Part Name | Manufacturer | PROD_ID | digikeypn | PARTREV | STANDARD
1 | Unpolarized capacitor | C | C_ESP_1 C_PW_4 | 0.1uF | CAPC1608X90 | 2 | https://www.yageo.com/upload/media/product/productsearch/datasheet/mlcc/UPY-GPHC_X7R_6.3V-to-50V_18.pdf | DigiKey Canada | 311-1777-1-ND | CC0603JRX7R8BB104 | Yageo
2 | Unpolarized capacitor, small symbol | C_Small | C_IMU_1 C_IMU_2 C_IMU_3 | 100nF | CAPC1608X90N | 3 | https://product.tdk.com/info/en/catalog/datasheets/mlcc_commercial_midvoltage_en.pdf | DigiKey Canada | 445-1304-1-ND | C1608X7R2A103K080AA | TDK Corporation
3 | Unpolarized capacitor | C | C_PW_1 C_PW_3 | 1uF | 0603 | 2 | https://content.kemet.com/datasheets/KEM_C1002_X7R_SMD.pdf | DigiKey Canada | 399-7847-1-ND | C0603C105K4RACTU | Kermet
4 | Unpolarized capacitor, small symbol | C_Small | C_PW_2 C_PW_5 | 4.7uF | C1206C475K3RACAUTO | 2 | https://api.kemet.com/component-edge/download/specsheet/C1206C475K3RACAUTO.pdf | DigiKey Canada | 399-7029-1-ND | C1206C475K3RACAUTO | Kermet
5 | Polarized capacitor | CP | CP_ESP_1 | 100uF | UCB0J101MCL1GS | 1 | https://www.nichicon.co.jp/english/products/pdfs/e-ucb.pdf | DigiKey Canada | 493-9357-1-ND | UCB0J101MCL1GS | Nichicon
6 |  | BAT20JFILM | D_PW_1 D_PW_2 D_PW_3 | BAT20JFILM | BAT20JFILM | 3 | https://www.st.com/content/ccc/resource/technical/document/datasheet/group1/81/a4/1f/0e/ca/8c/47/ba/CD00012201/files/CD00012201.pdf/jcr:content/translations/e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 | DigiKey Canada | 497-3381-1-ND | BAT20JFILM | STMicroelectronics | DIO-11623
7 |  | 4157 | J_1 J_2 | 4157 | PinSocket_1x20_P2.54mm_Vertical | 2 |  | DigiKey Canada |  |  | Adafruit Industries LLC |  | 1528-2929-ND
8 |  | Header_Pin_1 | J_CN_3 J_CN_4 J_PW_3 | Header_Pin_1 | PinHeader_1x01_P2.54mm_Vertical | 3
9 |  | Header_Pin_2 | J_PW_1 J_PW_2 | Header_Pin_2 | PinHeader_1x02_P2.54mm_Vertical | 2
10 |  | Header_Pin_4 | J_CN_1 J_CN_2 | Header_Pin_4 | PinHeader_1x04_P2.54mm_Vertical | 2
11 |  | Header_Pin_2 | J_5 | IMU_INT1 | PinHeader_1x02_P2.54mm_Vertical | 1
12 |  | Header_Pin_2 | J_4 | IMU_INT2 | PinHeader_1x02_P2.54mm_Vertical | 1
13 |  | Header_Pin_2 | J_6 | IMU_SCL | PinHeader_1x02_P2.54mm_Vertical | 1
14 |  | Header_Pin_2 | J_7 | IMU_SDA | PinHeader_1x02_P2.54mm_Vertical | 1
15 |  | Header_Pin_8 | J_3 | SPI | PinHeader_1x08_P2.54mm_Vertical | 1
16 | Inductor | L | L_PW_1 | 4.7uH | CV201210-4R7K | 1 | https://www.bourns.com/docs/Product-Datasheets/CV201210.pdf | DigiKey Canada | CV201210-4R7KCT-ND | CV201210-4R7K | Bourns Inc.
17 | Light emitting diode | LED | LED_ESP_1 | LED | LED_0603_1608Metric | 1 | https://katalog.we-online.de/led/datasheet/150060YS75000.pdf | DigiKey Canada | 732-4981-1-ND | 150060YS75000 | Würth Elektronik
18 |  | IRLML5103TRPBF | Q_PW_1 | IRLML5103TRPBF | IRLML5103TRPBF | 1 | https://www.infineon.com/dgdl/irlml5103pbf.pdf?fileId=5546d462533600a401535668505d2617 | DigiKey Canada | IRLML5103PBFCT-ND | IRLML5103TRPBF | Infineon Technologies
19 | Resistor, small symbol | R_Small | R_ESP_1 R_ESP_3 R_ESP_5 | 500 | RESC1508X55N | 3 | https://www.vishay.com/docs/28916/mcxhp.pdf | DigiKey Canada | 749-1523-1-ND | MCT0603PD4990DP500 | Vishay
20 | Resistor, small symbol | R_Small | R_IMU_1 R_IMU_2 | 4.7k | RESC1608X55N | 2 | https://www.yageo.com/upload/media/product/productsearch/datasheet/rchip/PYu-RT_1-to-0.01_RoHS_L_12.pdf | DigiKey Canada | 311-4.7KDCT-ND | RT0603DRD074K7L | Yageo
21 | Resistor, small symbol | R_Small | R_ESP_2 R_ESP_4 R_PW_1 | 10k | RESC1608X55N | 3 | https://www.yageo.com/upload/media/product/productsearch/datasheet/rchip/PYu-RT_1-to-0.01_RoHS_L_12.pdf | DigiKey Canada | YAG2321CT-ND | RT0603FRE0710KL | Yageo
22 | Resistor, small symbol | R_Small | R_PW_2 R_PW_3 | 100k | RESC1608X55N | 2 | https://www.yageo.com/upload/media/product/productsearch/datasheet/rchip/PYu-RT_1-to-0.01_RoHS_L_12.pdf | DigiKey Canada | 311-2395-1-ND | RT0603DRE07100KL | Yageo
23 | Resistor, small symbol | R_Small | R_PW_4 | 115k | RESC1608X55N | 1 | https://www.yageo.com/upload/media/product/productsearch/datasheet/rchip/PYu-RT_1-to-0.01_RoHS_L_12.pdf | DigiKey Canada | 311-2218-1-ND | RT0402DRE07115KL | Yageo
24 |  | PTS647SK38SMTR2LFS | SW_ESP_1 SW_ESP_2 | PTS647SK38SMTR2LFS | PTS647SK38SMTR2LFS | 2 | https://www.ckswitches.com/media/2567/pts647.pdf | DigiKey Canada | PTS647SK38SMTR2LFSCT-ND | PTS 647 SK38 SMTR2 LFS | C&K
25 | RF Module, ESP32-D0WD SoC, Wi-Fi 802.11b/g/n, Bluetooth, BLE, 32-bit, 2.7-3.6V, onboard antenna, SMD | ESP32-WROOM-32D | U_ESP_1 | ESP32-WROOM-32D | ESP32-WROOM-32 | 1 | https://www.espressif.com/sites/default/files/documentation/esp32-wroom-32d_esp32-wroom-32u_datasheet_en.pdf | DigiKey Canada | 1965-ESP32-WROOM-32D(4MB)CT-ND | USB4110-GF-A | Espressif Systems
26 |  | LSM6DSMTR | U_IMU_1 | LSM6DSMTR | LSM6DSMTR | 1 | https://www.st.com/content/ccc/resource/technical/document/datasheet/76/27/cf/88/c5/03/42/6b/DM00218116.pdf/files/DM00218116.pdf/jcr:content/translations/en.D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 | DigiKey Canada | 497-16696-1-ND | LSM6DSMTR | STMicroelectronics
27 |  | MAX25276ATCA_VY+ | U_PW_1 | MAX25276ATCA_VY+ | MAX25276ATCAVY | 1 | https://datasheets.maximintegrated.com/en/ds/MAX20075-MAX25276.pdf | DigiKey Canada | 175-MAX25276ATCA/VY+-ND | MAX25276ATCA_VY+ | Maxim Integrated
28 |  | USB4110-GF-A | U_CN_1 | USB4110-GF-A | USB4110-GF-A | 1 | https://gct.co/files/drawings/usb4110.pdf | DigiKey Canada | 2073-USB4110-GF-A-1-ND | PTS647SK38SMTR2LFS | GCT |  |  | A | Manufacturer Recommendations
Component Groups: | 28
Component Count: | 47
Fitted Components: | 47
Number of PCBs: | 1
Total components: | 47
Schematic Version: | v0.0.3
Schematic Date: | 2020-11-25
PCB Variant: | default
BoM Date: | 11/25/20 11:44:30
Schematic Source: | esp32_sensor.sch
KiCad Version: | Eeschema (5.1.7)-1

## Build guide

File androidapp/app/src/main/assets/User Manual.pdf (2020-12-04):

Before You Start

Downloading the App

First, download the official CANnect app on Google play store. This app will communicate with the reader to display and translate vehicle information as well as additional information such as: sensors and current vehicle information.

Introduction

Key feature of the reader

Getting Started

After successfully downloading the app on the Android device, connect the reader to OBD-II port of the vehicle. Steady green led light indicates the reader power is on, and flashing red led light means the device is ready for Bluetooth pairing.

Hardware

Reader

1. When the reader is connected to the vehicle OBD II port, flashing red-led light indicates the reader is seeking for Bluetooth devices (Android phone) to pair up.
2. Once the engine is turned on, connect to the reader from the app via Bluetooth. Do not turn off the engine during use of the app.
3. Once the two devices are paired up, red-led will stop flashing and green-led will light up.

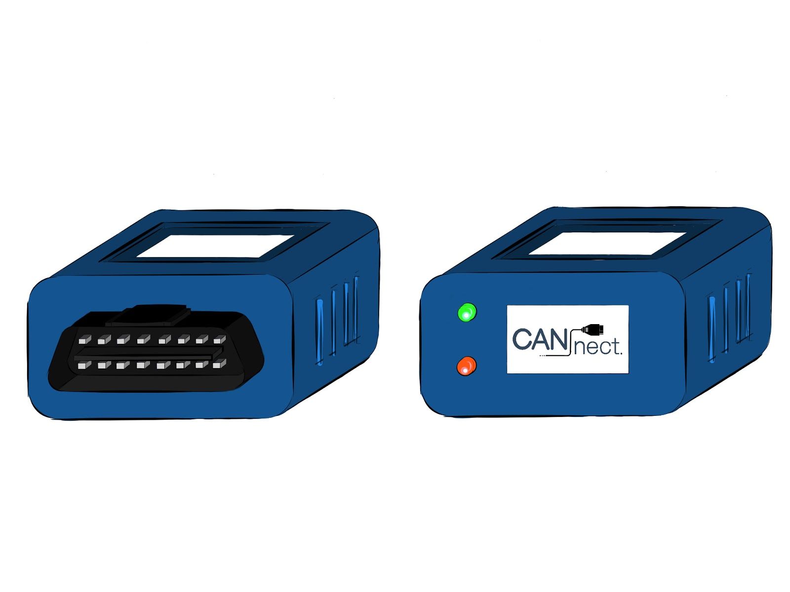
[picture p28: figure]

4. Since there is no external power supply, the reader will turn-off when it is unplugged from the OBD II port.
5. Since the OBD II port is always powered on when the vehicle engine is off, the reader will also be on as long as it is plugged in. (maintenance)

Sensor

CANnect allows car hobbyists to explore more about the vehicles with 6DOF sensor. The sensor enables users to view current vehicle orientations and translations on the app.

1. Place the CANnect sensor at the centre of the interior hood of the vehicle, or any place that user desires.
2. Locate the nearest automobile auxiliary power outlet (car cigarette lighter outlet) and plug in the adapter included in the package to power on the sensor.
a. If you wish, you may connect wires directly from the +12V line to the connector pins. Ensure it is professionally installed.

3. When the power is on, flashing the red-led light indicates the sensor is trying to establish connection with the CANnect reader via Wi-Fi. Therefore, the reader must be plugged into the OBD II port.
4. Once the connection is confirmed, instead of flashing red-led, fixed steady green-led will light up.

GPS/Tracking Module

CANnect can support an additional addon module to enable location tracking of a vehicle. This tracking module encompasses an LTE/GPS combo or separate LTE and GPS components which sends longitude and latitude information to Firebase which is received on the app.

Note that the use of this feature requires Firebase, a service operated by Google. In using this component, the user agrees that their location information may be processed and handled by Google and its operating partners who may be located outside of Canada - this is typically in the United States for North America.

For this module, it uses the SIMCOM SIM7000A LTE module. Since this module uses a special variant of 4G LTE instead of the traditional version, make sure to check with the cellular provider of choice that the SIM Card service supports these requirements.

- LTE Band 2 (1900 MHz)
- LTE Band 4 (AWS 1700/2100)
- LTE Band 12 (700 MHz)
- LTE Band 13 (700 MHz)
- LTE CAT-M1 (often referred to as eMTC or LTE-M) or CAT NB1 (referred to as NB-IoT)

CANtech recommends Hologram for its single rate for global coverage across multiple networks and is the network that CANnect has been tested with. Otherwise, Telus is an alternative option as well for Canada-only usage.

Setting up the hardware for Tracking Module

1. Screw or attach the provided antennas onto the connectors labelled “LTE” and “GPS.”
2. Insert SIM Card in the microSIM size format.
3. Provide power to the module (---ADD HOW---)
a. Use the provided power adapter to the vehicle’s auxiliary power outlet, or
b. Connect the wires directly from the +12V line to the connector pins on the module. Perform this step with professional assistance.
4. An LED indicator for “PWR” should light on to indicate it is on.

5. Position the module such that the antenna has a clear sight to the sky.

Setting up the software and network connection

1. Follow steps 1-6 in “Using the App” to pair the reader to the app.
2. In Settings, choose the GPS Module section
3. Login with your credentials for CANnect car-tracking. Otherwise, you may create one yourself.
a. Use the Sign-in with Google option for a quick login, or
b. Provide an email and password.
4. Type in the APN setting for your SIM Card service. For Hologram, this is “hologram”. Check with your service provider if you are not sure what this is.
5. Choose the option to pair your tracking module to the app. This may take a few moments.
6. The status should say it is paired. The number on the module should match the paired device number in the app. Your module should automatically connect to the cellular service and send its coordinates. An LED indicator for “LTE” should blink occasionally if it is connected.
7. If you need to reconfigure the APN, follow steps 4-6. If the app does not show any update coordinates, check to see if the “LTE” indicator is blinking. If not, check to see if the APN is correct and that the module is in an area with cellular coverage.

Using the Tracking Module

1. How to use it.

Using the App

1. Launch the CANnect app.
2. Click on the Connect button at the bottom of the screen to pair with the reader.
3. If Bluetooth is not already turned on, click BLUETOOTH ON to turn on.
4. Click DISCOVER NEW DEVICES and select CANnect Reader to start pairing with the reader.
5. Upon successful pairing with the reader, Connected to the Reader will display at the bottom.
6. Click at the top left of the screen to go back to the previous page.
7. Red text, finding protocol…, indicates the reader is automatically finding the correct protocol to communicate with the vehicle OBD II. This process can take up to 30 seconds.
8. Upon finding the correct protocol, Protocol has been found, blue text will be displayed as seen in the Figure X below.
9. Can't find the correct Protocol! will be displayed if the vehicle protocol is not supported by the CANnect reader.

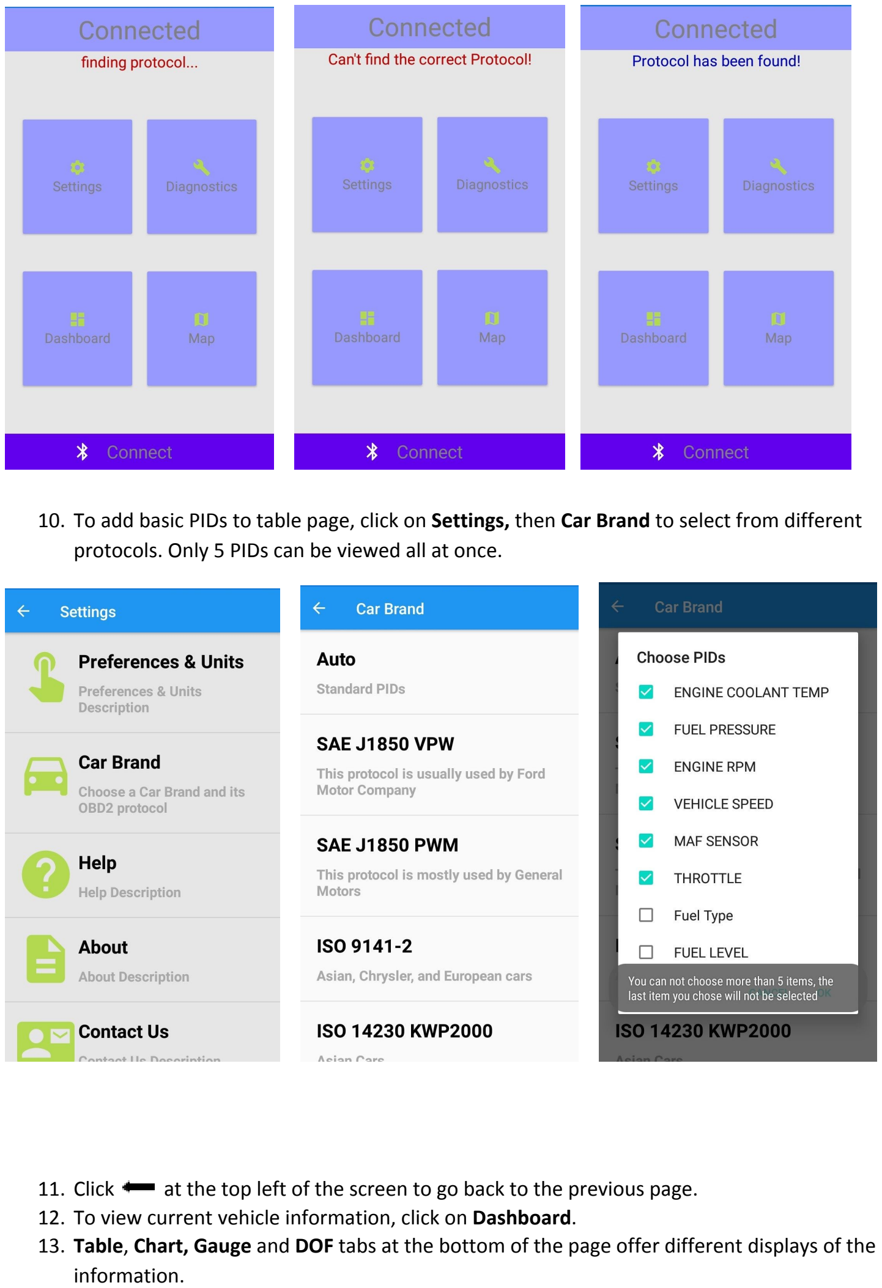
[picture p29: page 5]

10. To add basic PIDs to table page, click on Settings, then Car Brand to select from different protocols. Only 5 PIDs can be viewed all at once.
11. Click at the top left of the screen to go back to the previous page.
12. To view current vehicle information, click on Dashboard.
13. Table, Chart, Gauge and DOF tabs at the bottom of the page offer different displays of the information.

14. On the Table page, users can view previously selected PIDs along with the sensor reading from the sensor module.
15. On the Chart page, users can view different PIDs by choosing from a drop-down list. The graph can also be zoomed in/out by pinching the screen.
16. On the Gauge page, users can also view different gauges by long pressing on either four boxes. Doing so will pop out the menu window which users can select various options from. Some of the PIDs will not display any values as some vehicle protocol lacks the corresponding sensor PID.

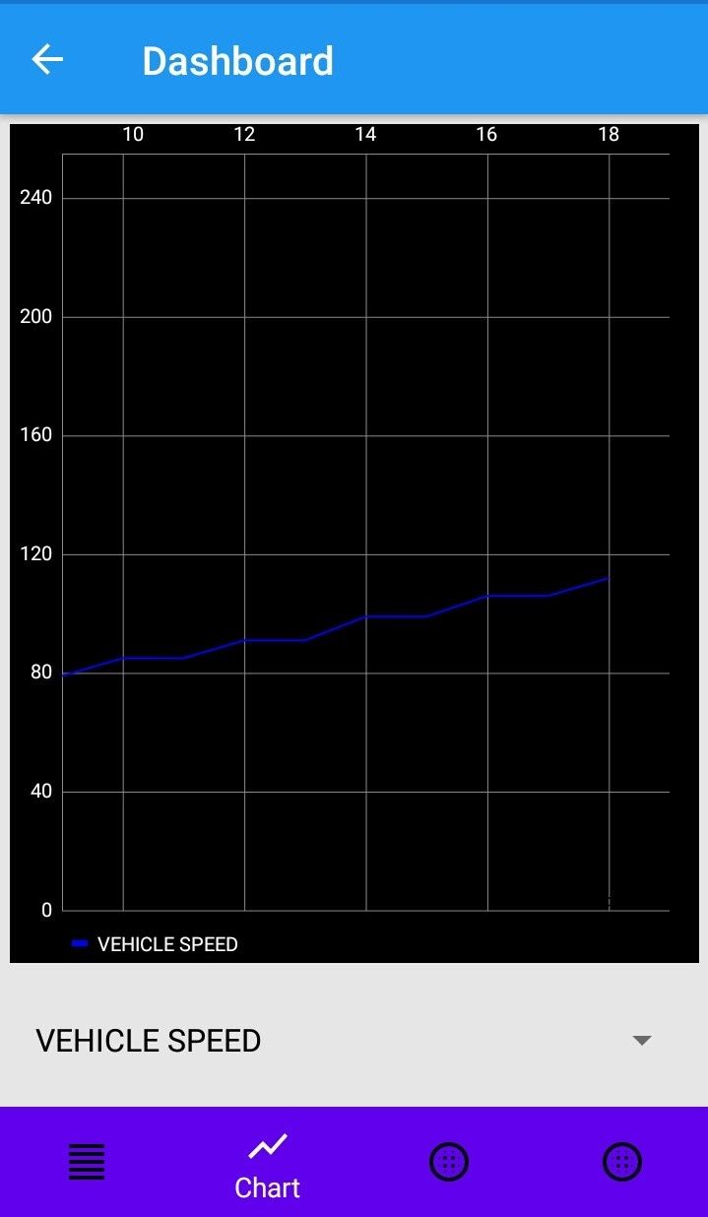
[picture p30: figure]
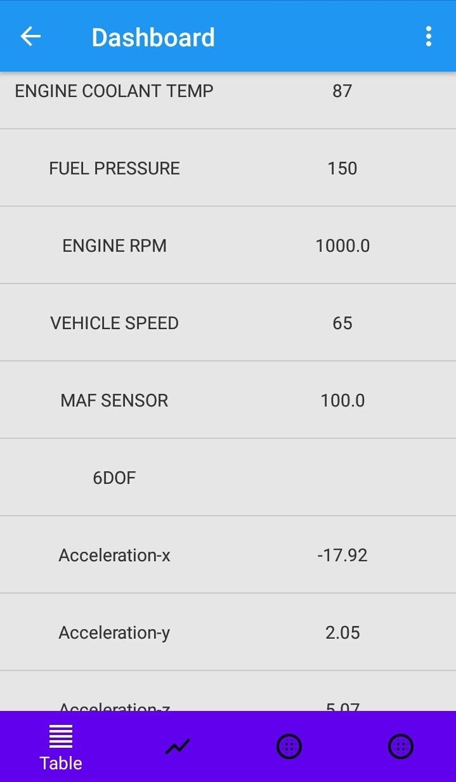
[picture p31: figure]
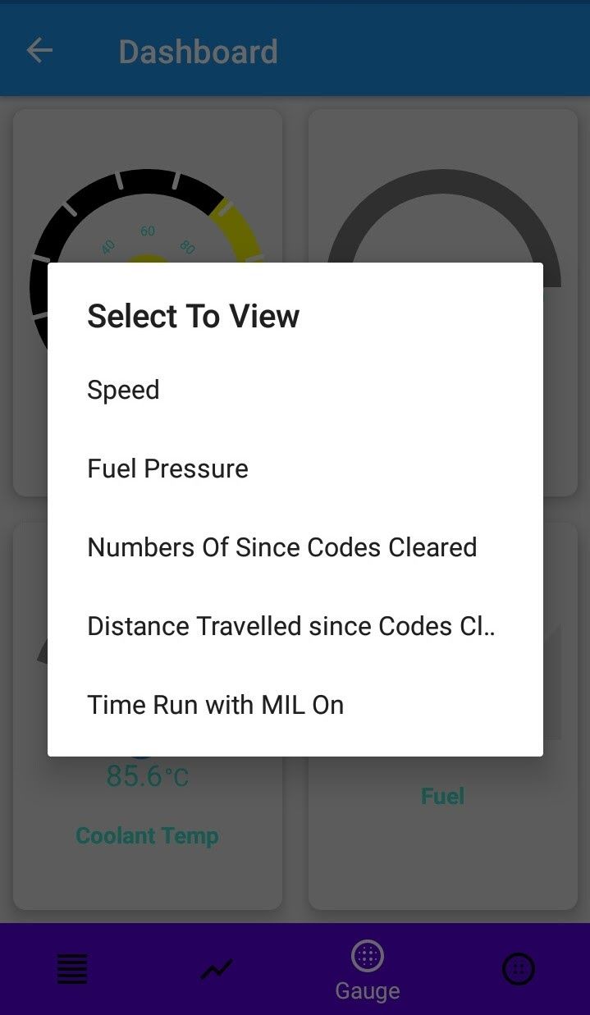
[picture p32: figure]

17. In addition, unique to CANnect reader, users can also view the forces acting on vehicle at different points on the app.
18. And using data from 6DOF sensors, the app can calculates acceleration, orientation.

Maintenance

1. If the app is closed, the reader must be unplugged from the OBD and plug in before relaunching the app again.

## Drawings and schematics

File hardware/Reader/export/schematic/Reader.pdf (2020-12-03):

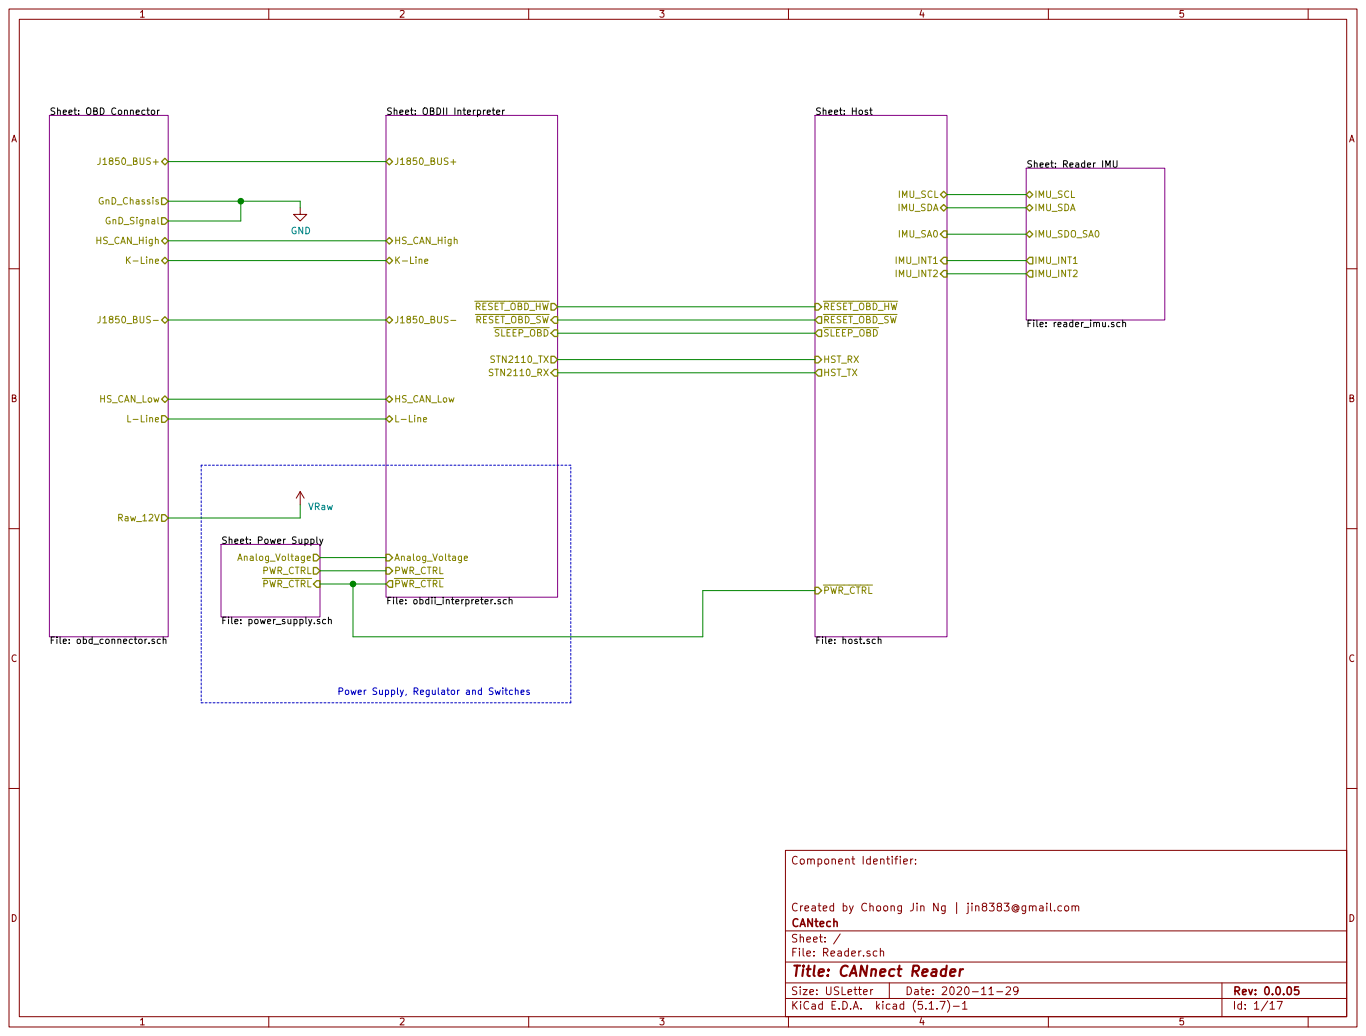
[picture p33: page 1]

IMU_INT2 Sheet: Host File: host.sch PWR_CTRL

Sheet: OBD Connector File: obd_connector.sch Raw_12V

Power Supply, Regulator and Switches

Id: 1/17 Title: CANnect Reader File: Reader.sch Sheet: / CANtech Created by Choong Jin Ng | jin8383@gmail.com

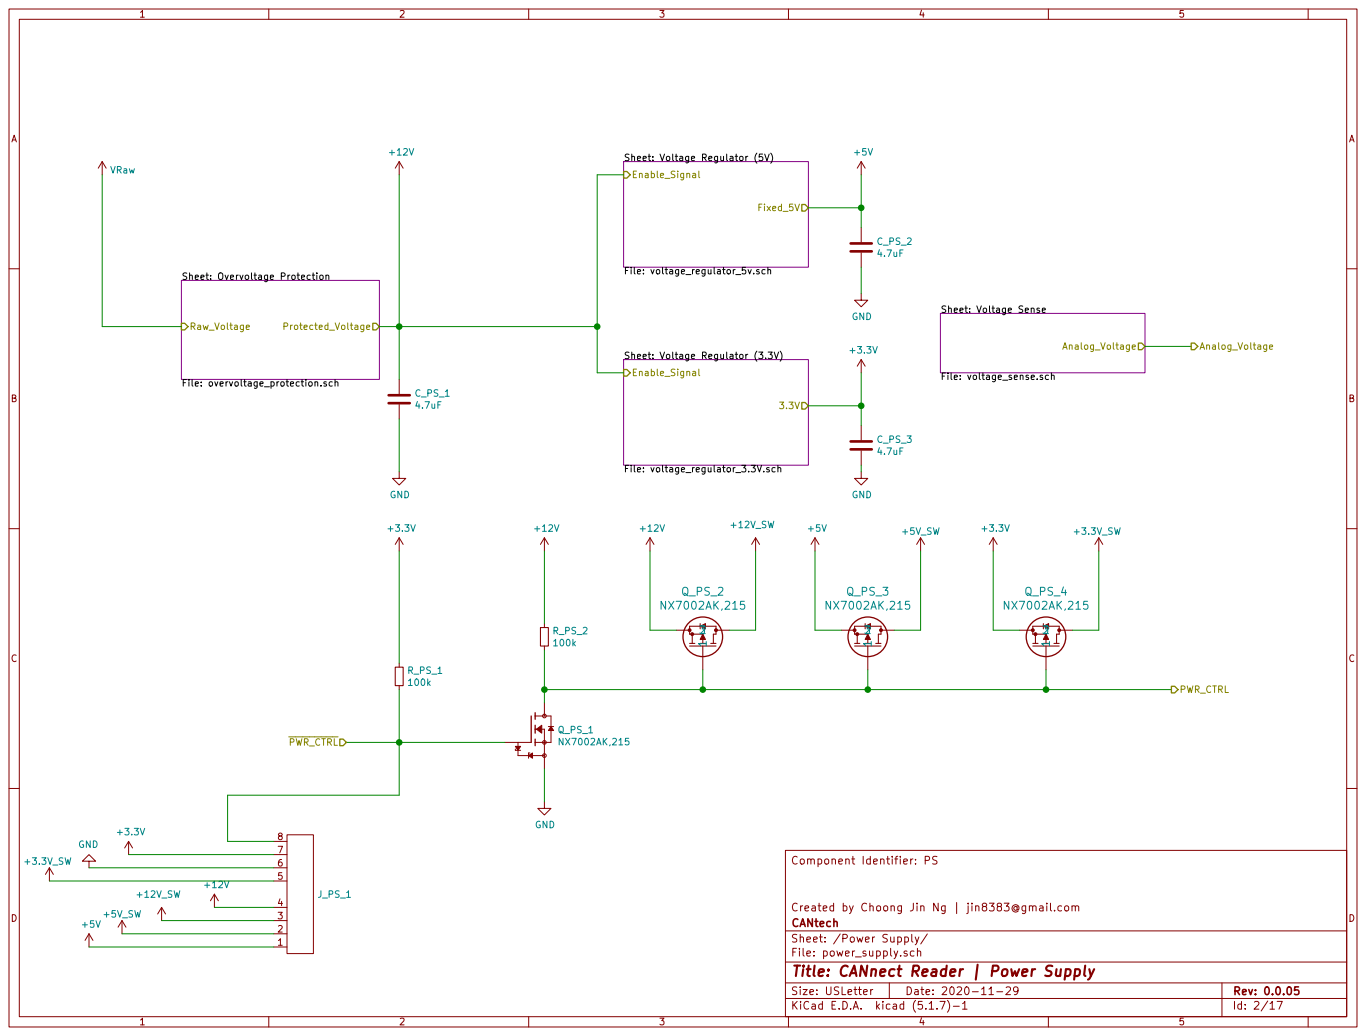
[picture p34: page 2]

Sheet: /Power Supply/ CANtech Created by Choong Jin Ng | jin8383@gmail.com

File: power_supply.sch
Id: 2/17 Title: CANnect Reader | Power Supply

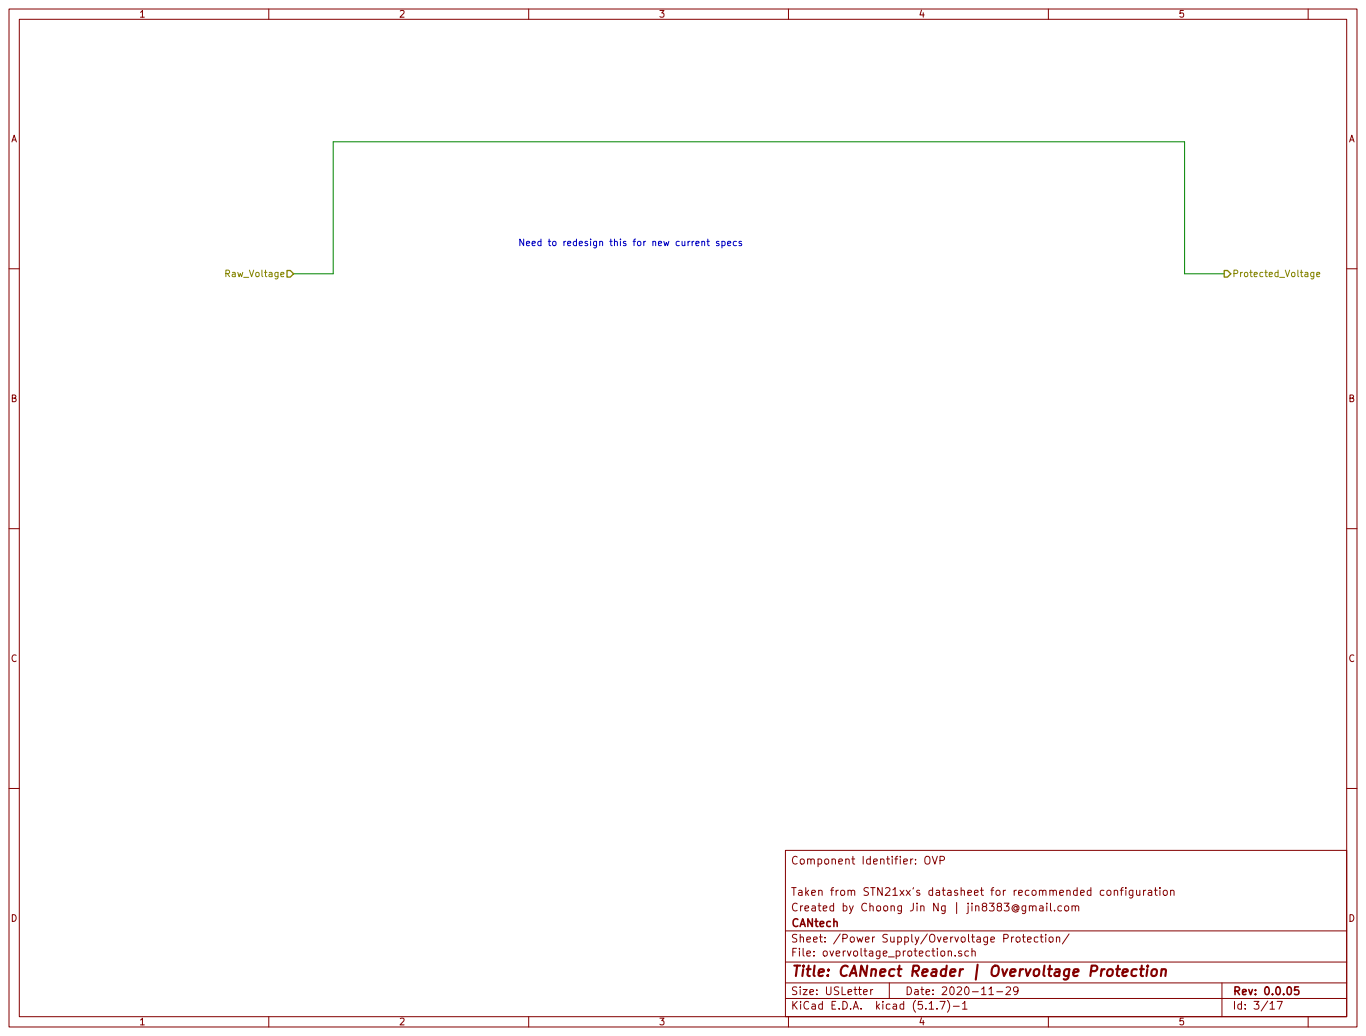
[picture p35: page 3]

Need to redesign this for new current specs

Component Identifier: OVP Sheet: /Power Supply/Overvoltage Protection/ CANtech Created by Choong Jin Ng | jin8383@gmail.com

Taken from STN21xx's datasheet for recommended configuration

Rev: 0.0.05 | D Date: 2020-11-29 KiCad E.D.A. kicad (5.1.7)-1 Size: USLetter

File: overvoltage_protection.sch
Id: 3/17 Title: CANnect Reader | Overvoltage Protection

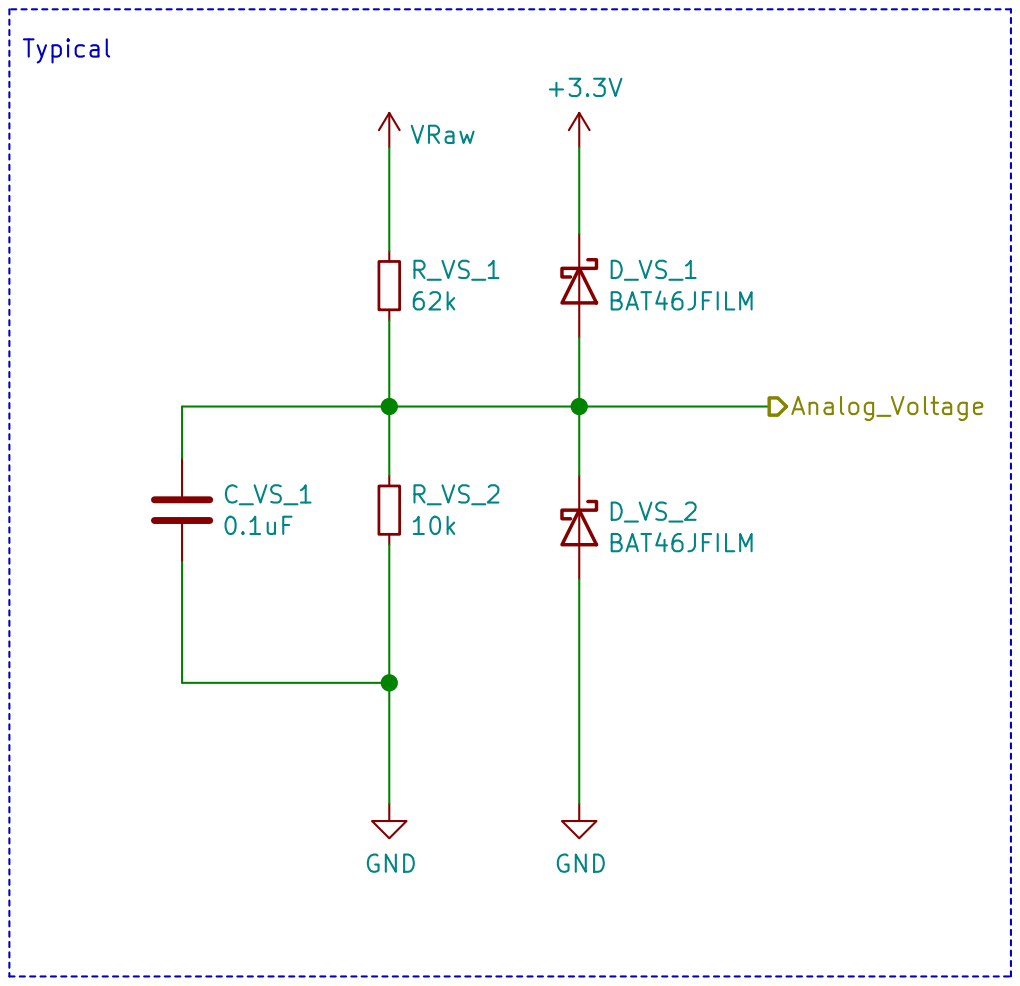
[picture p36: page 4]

Taken from STN21xx's datasheet for recommended configuration
Sheet: /Power Supply/Voltage Sense/ CANtech Created by Choong Jin Ng | jin8383@gmail.com

File: voltage_sense.sch
Id: 4/17 Title: CANnect Reader | Voltage Sense

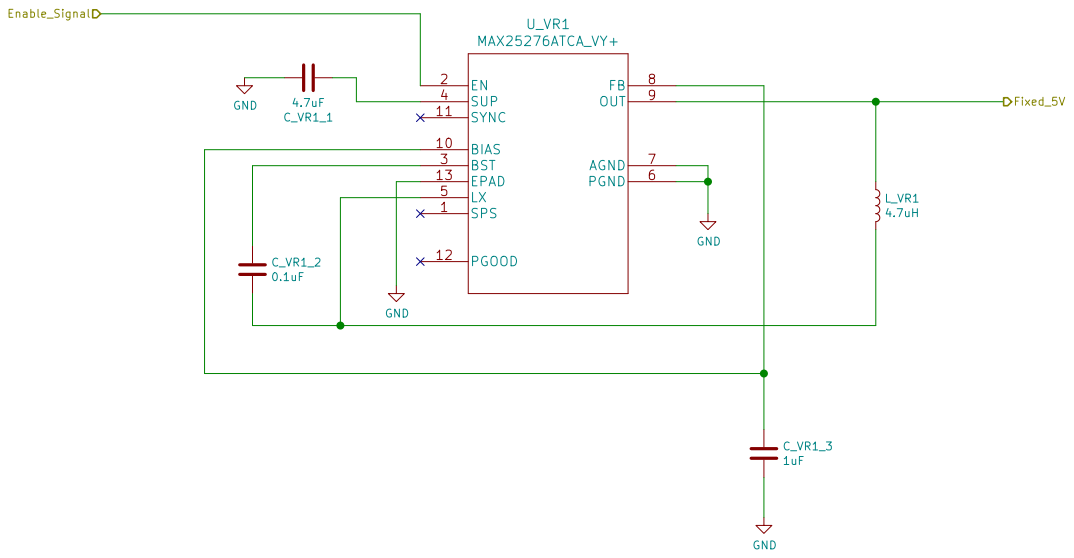
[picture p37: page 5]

Sheet: /Power Supply/Voltage Regulator (5V)/ CANtech Created by Choong Jin Ng | jin8383@gmail.com

File: voltage_regulator_5v.sch
Id: 5/17 Title: CANnect Reader | Voltage Regulator (5V)

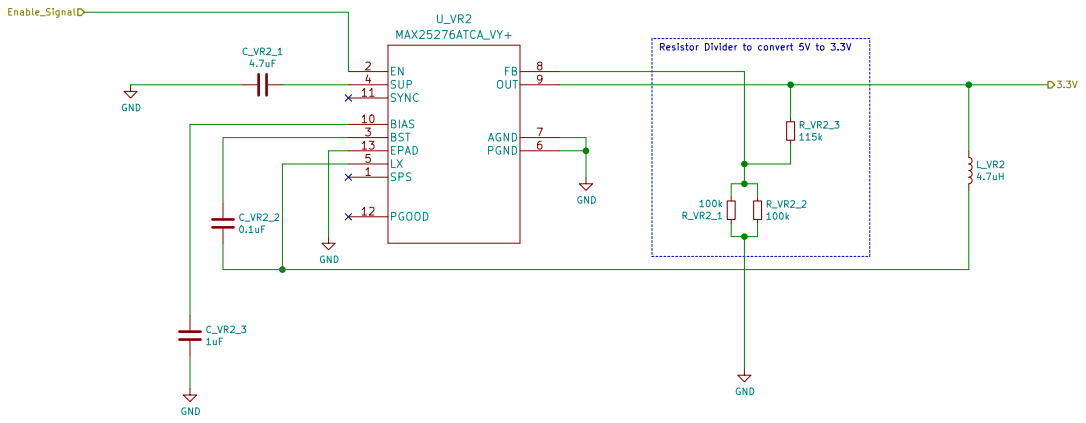
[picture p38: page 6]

Sheet: /Power Supply/Voltage Regulator (3.3V)/ CANtech Created by Choong Jin Ng | jin8383@gmail.com

File: voltage_regulator_3.3V.sch
Id: 6/17 Title: CANnect Reader | Voltage Regulator (3.3V)

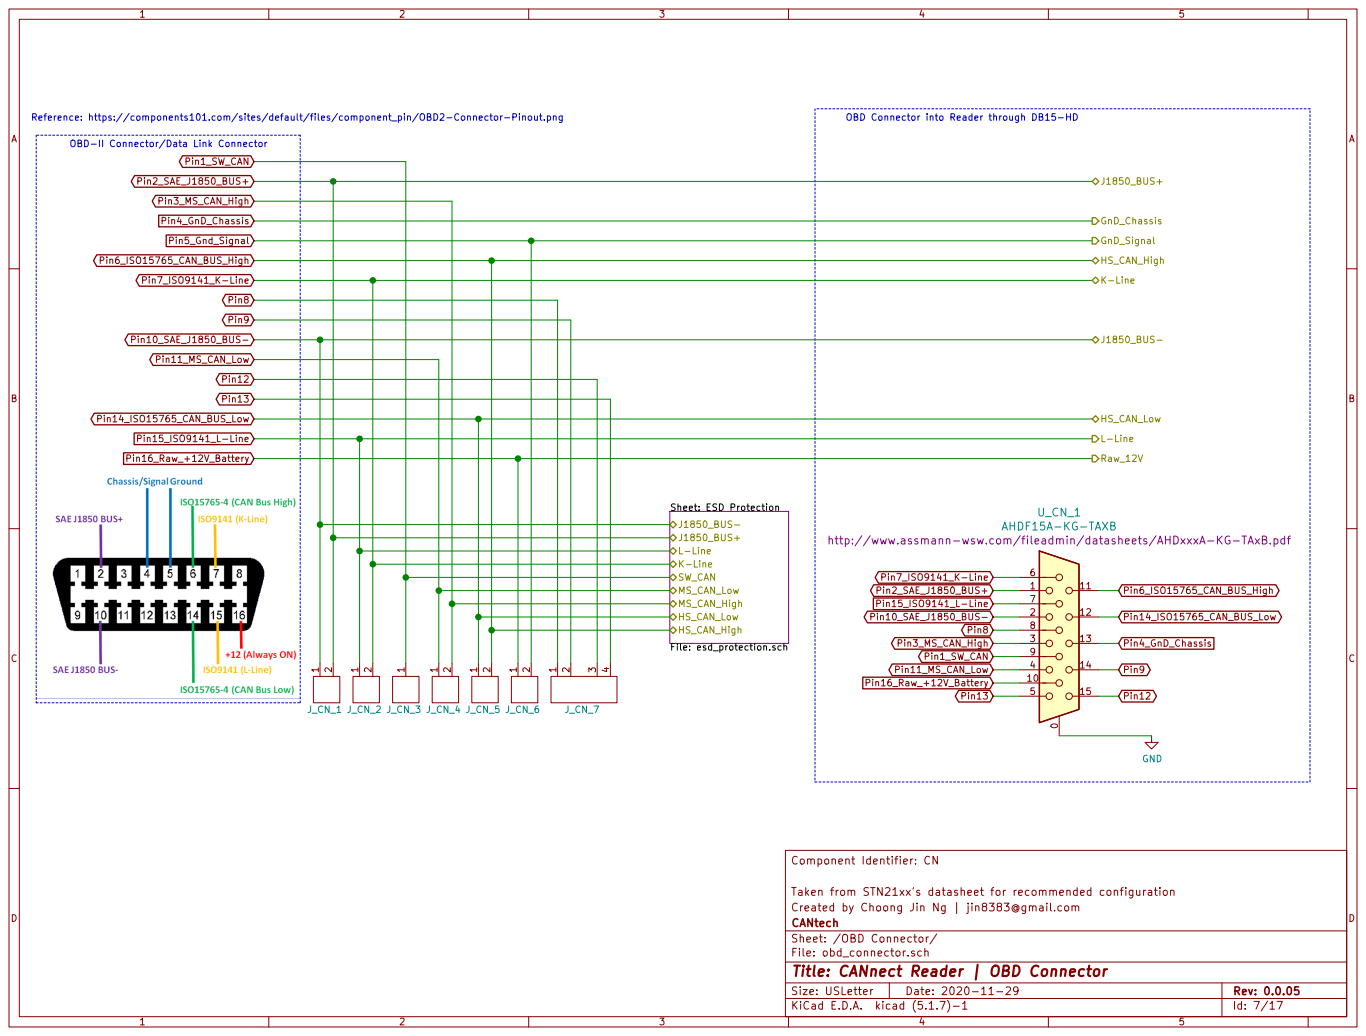
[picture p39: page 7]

http://www.assmann-wsw.com/fileadmin/datasheets/AHDxxxA-KG-TAxB.pdf 1

Taken from STN21xx's datasheet for recommended configuration
File: obd_connector.sch Sheet: /OBD Connector/ CANtech Created by Choong Jin Ng | jin8383@gmail.com

Id: 7/17 Title: CANnect Reader | OBD Connector

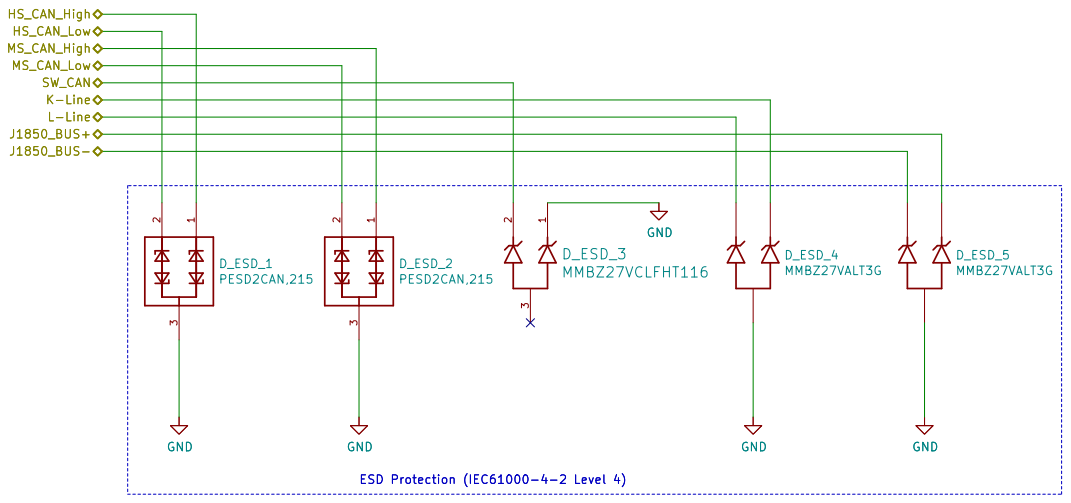
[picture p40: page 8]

Component Identifier: ESD
Taken from STN21xx's datasheet for recommended configuration

File: esd_protection.sch Sheet: /OBD Connector/ESD Protection/ CANtech Created by Choong Jin Ng | jin8383@gmail.com

Id: 8/17 Title: CANnect Reader | ESD Protection

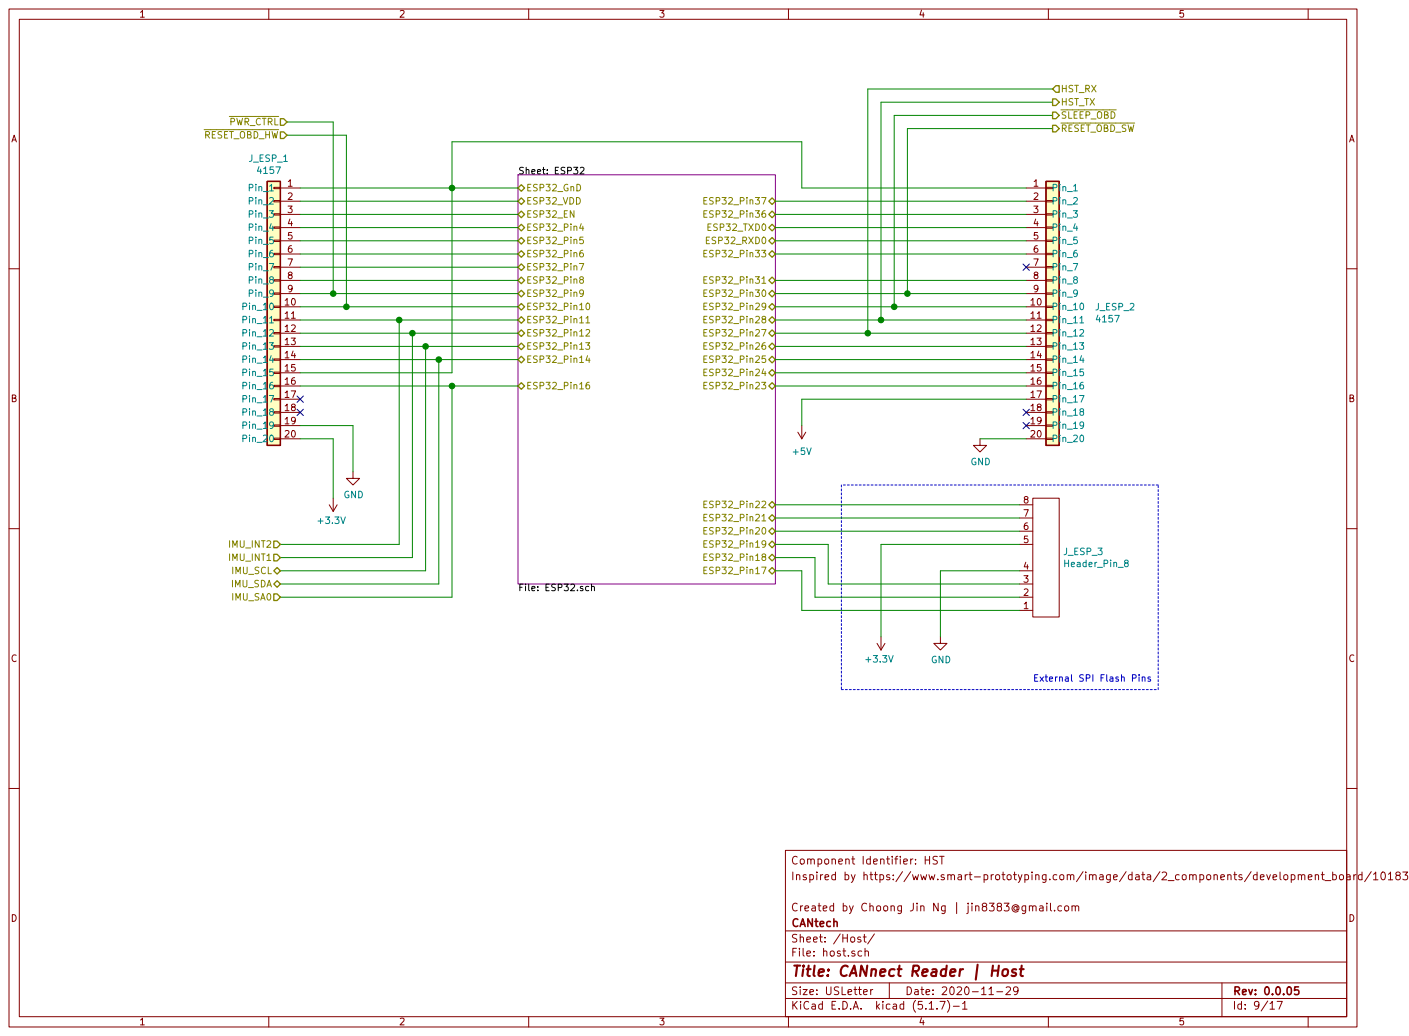
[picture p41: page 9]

External SPI Flash Pins

Component Identifier: HST
Inspired by https://www.smart-prototyping.com/image/data/2_components/development_board/101839%20NodMCU-32S/1.png

Id: 9/17 Title: CANnect Reader | Host File: host.sch Sheet: /Host/ CANtech Created by Choong Jin Ng | jin8383@gmail.com

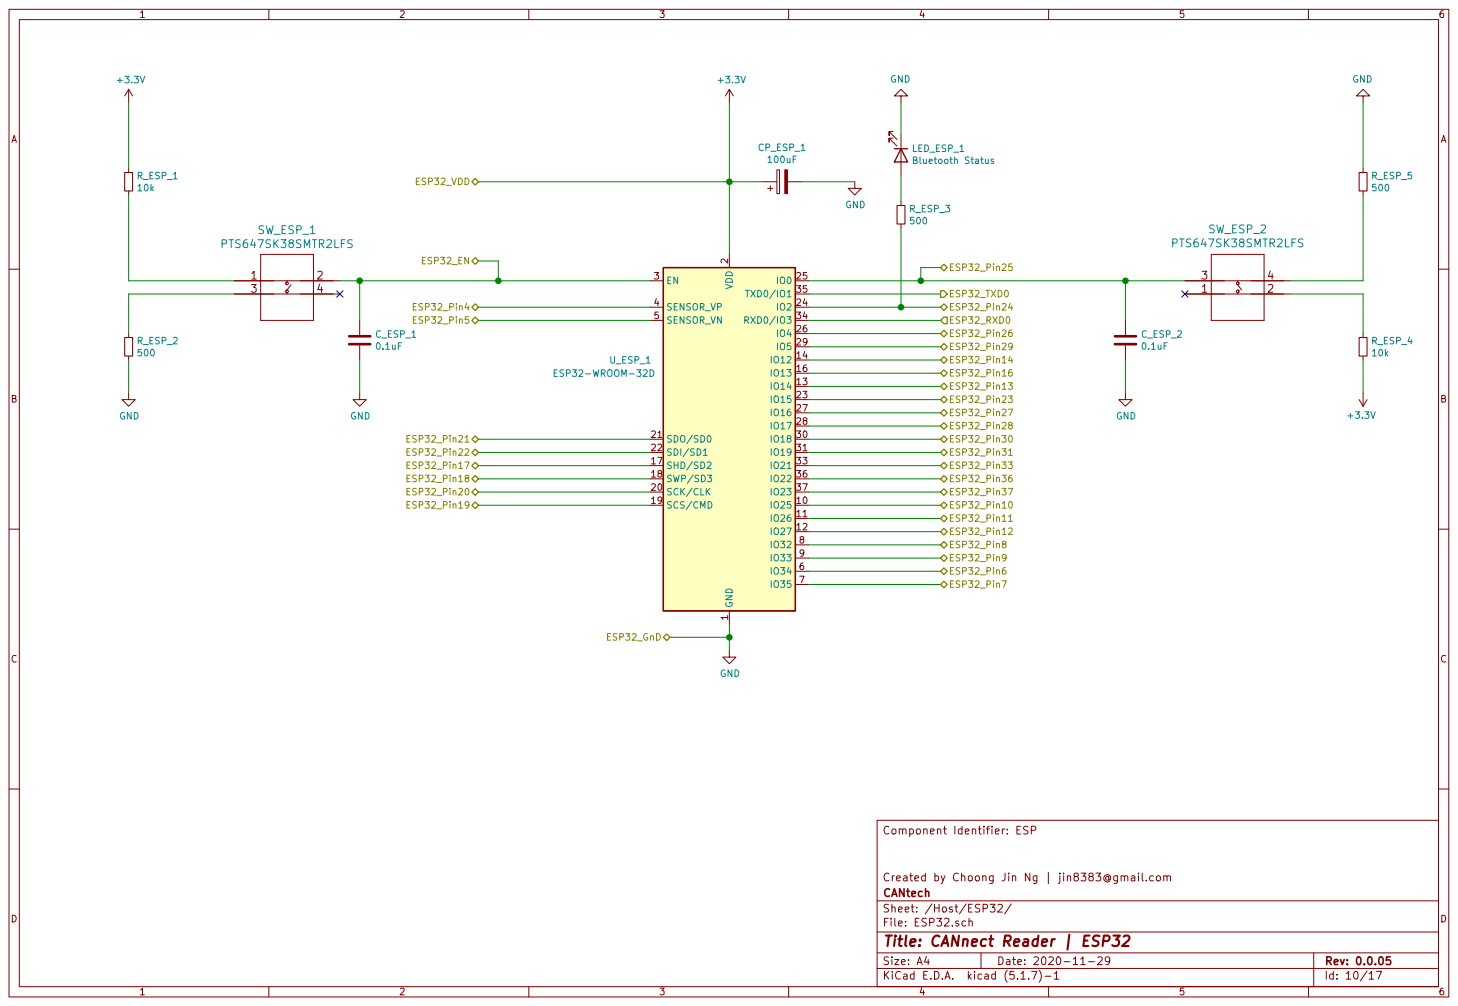
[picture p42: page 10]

2 SCK/CLK 20 SDO/SD0 21 SDI/SD1 22

File: ESP32.sch Sheet: /Host/ESP32/ CANtech Created by Choong Jin Ng | jin8383@gmail.com

Id: 10/17 Title: CANnect Reader | ESP32

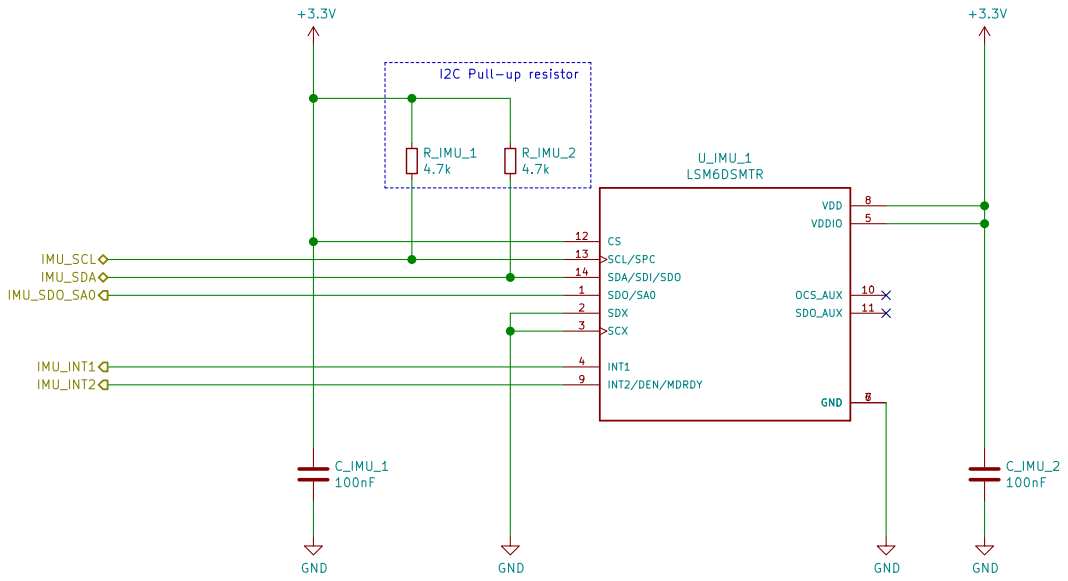
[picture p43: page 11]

File: reader_imu.sch Sheet: /Reader IMU/ CANtech Created by Choong Jin Ng | jin8383@gmail.com

Id: 11/17 Title: CANnect Reader | IMU

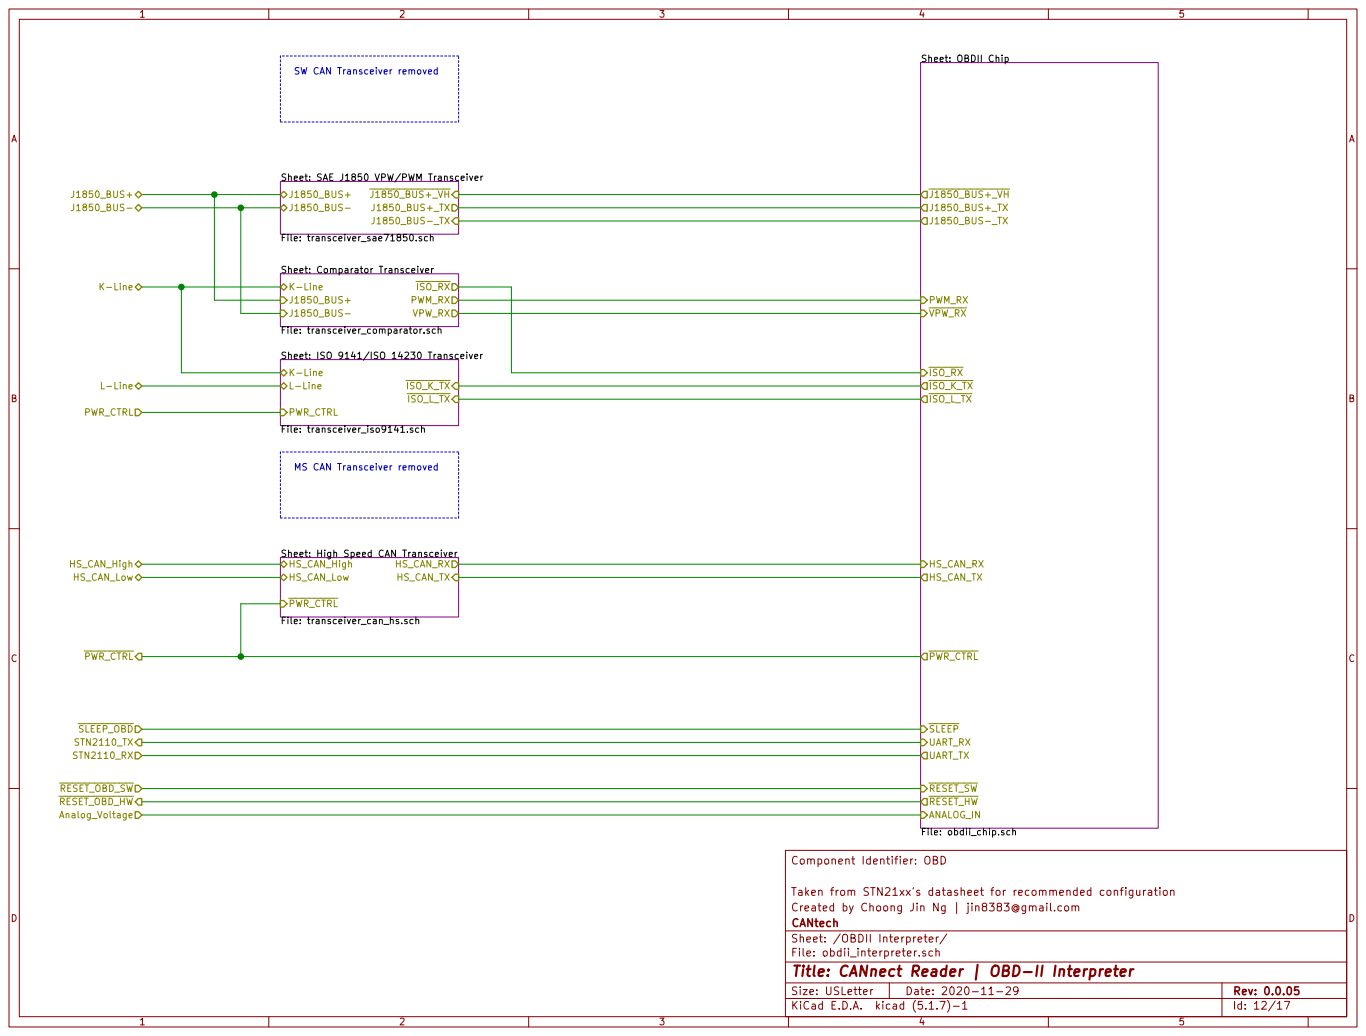
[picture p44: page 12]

Sheet: SAE J1850 VPW/PWM Transceiver File: transceiver_sae71850.sch
J1850_BUS+
J1850_BUS- Sheet: Comparator Transceiver

Sheet: ISO 9141/ISO 14230 Transceiver File: transceiver_iso9141.sch
K-Line
L-Line Sheet: High Speed CAN Transceiver File: transceiver_can_hs.sch HS_CAN_High HS_CAN_Low

Component Identifier: OBD Sheet: /OBDII Interpreter/ CANtech Created by Choong Jin Ng | jin8383@gmail.com

Taken from STN21xx's datasheet for recommended configuration

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

File: obdii_interpreter.sch
Id: 12/17 Title: CANnect Reader | OBD-II Interpreter


Taken from STN21xx's datasheet for recommended configuration
Sheet: /OBDII Interpreter/ISO 9141/ISO 14230 Transceiver/ CANtech Created by Choong Jin Ng | jin8383@gmail.com

File: transceiver_iso9141.sch
Id: 13/17 Title: CANnect Reader | ISO 9141/ISO 14230 Transceiver


https://ww1.microchip.com/downloads/en/DeviceDoc/20005167C.pdf R_HSCAN_2

Taken from STN21xx's datasheet for recommended configuration
Sheet: /OBDII Interpreter/High Speed CAN Transceiver/ CANtech Created by Choong Jin Ng | jin8383@gmail.com

File: transceiver_can_hs.sch
Id: 14/17 Title: CANnect Reader | High Speed CAN Transceiver


Taken from STN21xx's datasheet for recommended configuration
Sheet: /OBDII Interpreter/SAE J1850 VPW/PWM Transceiver/ CANtech Created by Choong Jin Ng | jin8383@gmail.com

File: transceiver_sae71850.sch
Id: 15/17 Title: CANnect Reader | SAE J1850 VPW/PWM Transceiver

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

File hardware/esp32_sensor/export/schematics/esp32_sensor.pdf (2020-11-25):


Component Identifier: Sheet: IMU

Sheet: Connector File: connnector.sch

File: esp32_sensor.sch Sheet: / Created by Choong Jin Ng | jin3838@gmail.com

Id: 1/5 Title: ESP32 Sensor Module


File: power.sch Sheet: /Power/ Created by Choong Jin Ng | jin3838@gmail.com

Id: 2/5 Title: ESP32 Sensor Module | Power Supply


Id: 3/5 Title: ESP32 Sensor Module | Inertia Measurement Unit File: imu.sch Sheet: /IMU/ Created by Choong Jin Ng | jin3838@gmail.com


Id: 4/5 Title: ESP32 Sensor Module | Connector File: connnector.sch Sheet: /Connector/ Created by Choong Jin Ng | jin3838@gmail.com


2 SCK/CLK 20 SDO/SD0 21 SDI/SD1 22

Created by Choong Jin Ng | jin3838@gmail.com
Sheet: /ESP32 Chip/
File: esp32_chip.sch
Id: 5/5 Title: ESP32 Sensor Module | ESP32 Chip

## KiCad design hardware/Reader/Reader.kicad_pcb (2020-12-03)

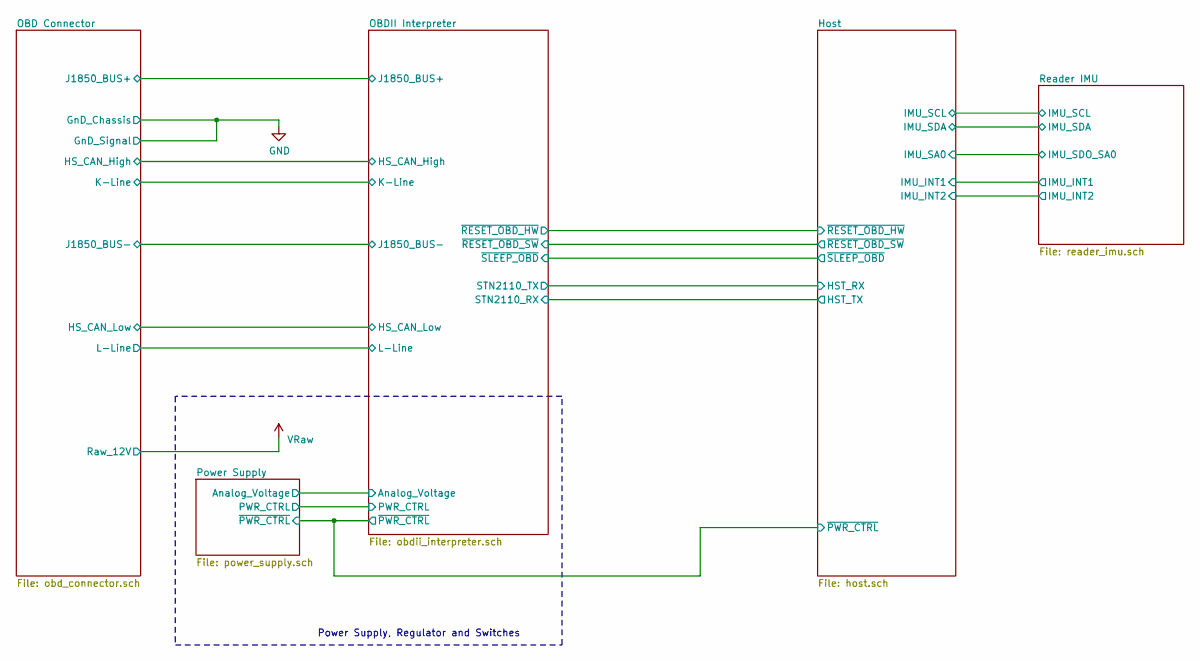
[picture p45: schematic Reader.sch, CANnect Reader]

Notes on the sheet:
Power Supply, Regulator and Switches

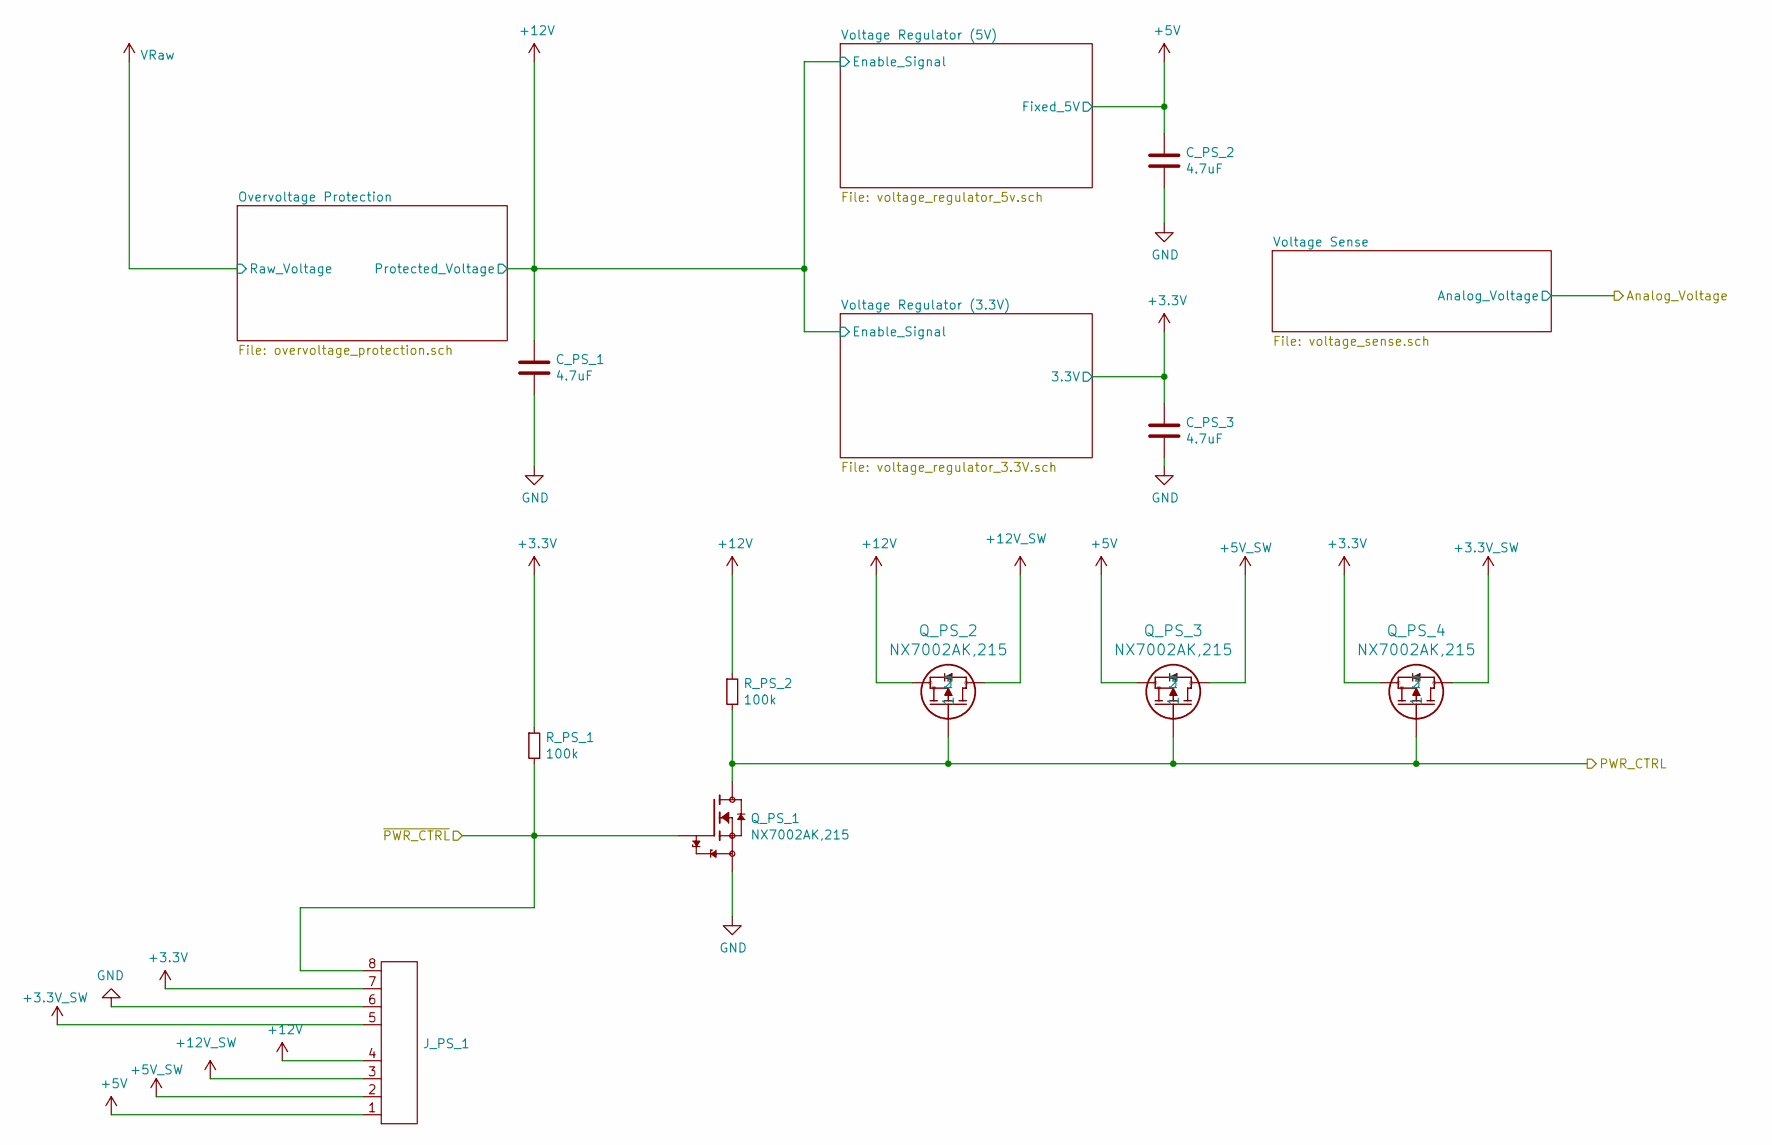
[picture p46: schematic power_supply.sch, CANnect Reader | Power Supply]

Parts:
C_PS_1, C_PS_2, C_PS_3: 4.7uF; C1206C475K3RACAUTO; Part Name C1206C475K3RACAUTO; digikeypn 399-7029-1-ND
J_PS_1: Header_Pin_8; PinHeader_1x08_P2.54mm_Vertical
Q_PS_1, Q_PS_2, Q_PS_3, Q_PS_4: NX7002AK,215; SOT95P230X110-3N; Part Name NX7002AK,215; digikeypn 1727-1289-1-ND
R_PS_1, R_PS_2: 100k; RESC1608X55N; Part Name RT0603DRE07100KL; digikeypn 311-2395-1-ND

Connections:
+3.3V_SW: J_PS_1.5, Q_PS_4.2
+3V3: C_PS_3.1, J_PS_1.7, Q_PS_4.3, R_PS_1.1; also elsewhere on the board
+5V: C_PS_2.1, J_PS_1.1, Q_PS_3.3; also elsewhere on the board
+5V_SW: J_PS_1.2, Q_PS_3.2; also elsewhere on the board
+12V_SW: J_PS_1.3, Q_PS_2.2; also elsewhere on the board
/Host/~PWR_CTRL~: J_PS_1.8, Q_PS_1.1, R_PS_1.2; also elsewhere on the board
/OBDII Interpreter/PWR_CTRL: Q_PS_1.3, Q_PS_2.1, Q_PS_3.1, Q_PS_4.1, R_PS_2.2; also elsewhere on the board
Pin4_GnD_Chassis: C_PS_1.2, C_PS_2.2, C_PS_3.2, J_PS_1.6, Q_PS_1.2; also elsewhere on the board

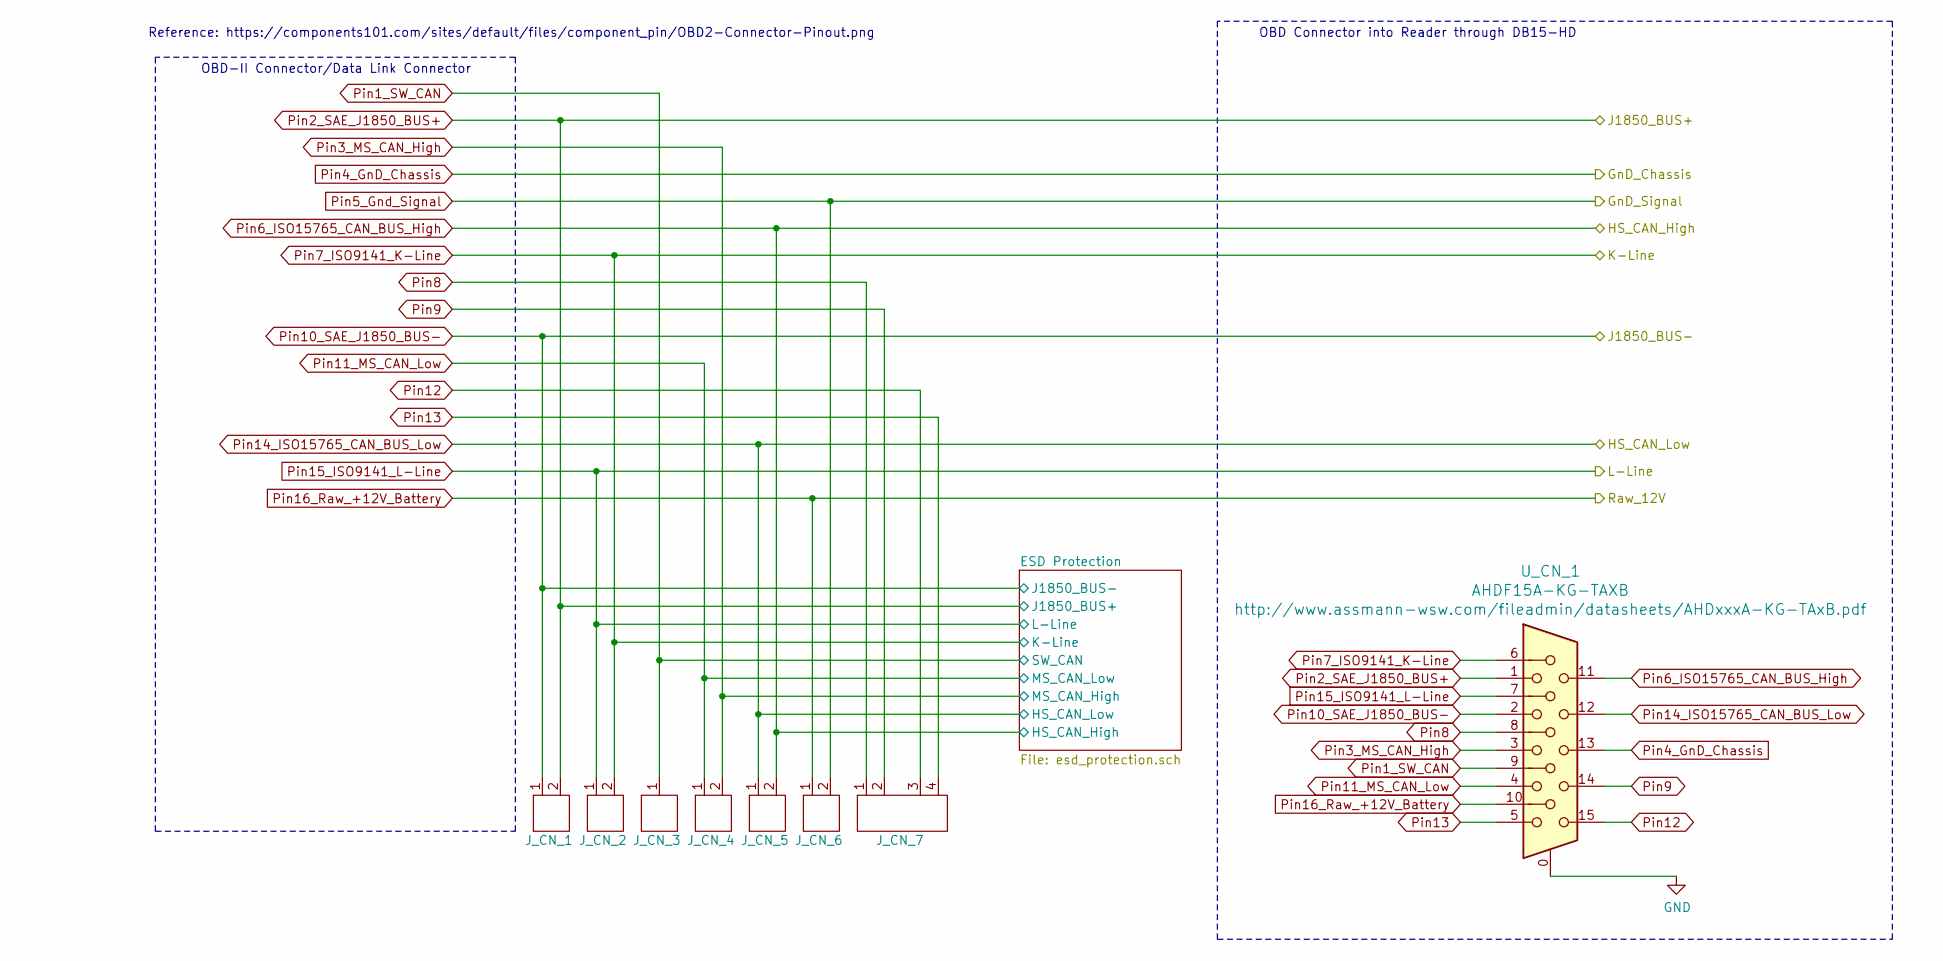
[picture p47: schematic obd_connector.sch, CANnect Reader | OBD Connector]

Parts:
J_CN_1, J_CN_2, J_CN_4, J_CN_5, J_CN_6: Header_Pin_2; PinHeader_1x02_P2.54mm_Vertical
J_CN_3: Header_Pin_1; PinHeader_1x01_P2.54mm_Vertical
J_CN_7: Header_Pin_4; PinHeader_1x04_P2.54mm_Vertical
U_CN_1: AHDF15A-KG-TAXB; Part Name AHDF15A-KG-TAXB; digikeypn AE11024-ND

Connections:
Pin1_SW_CAN: J_CN_3.1, U_CN_1.9; also elsewhere on the board
Pin2_SAE_J1850_BUS+: J_CN_1.2, U_CN_1.1; also elsewhere on the board
Pin3_MS_CAN_High: J_CN_4.2, U_CN_1.3; also elsewhere on the board
Pin4_GnD_Chassis: J_CN_6.2, U_CN_1.0, U_CN_1.13; also elsewhere on the board
Pin6_ISO15765_CAN_BUS_High: J_CN_5.2, U_CN_1.11; also elsewhere on the board
Pin7_ISO9141_K-Line: J_CN_2.2, U_CN_1.6; also elsewhere on the board
Pin8: J_CN_7.1, U_CN_1.8
Pin9: J_CN_7.2, U_CN_1.14
Pin10_SAE_J1850_BUS-: J_CN_1.1, U_CN_1.2; also elsewhere on the board
Pin11_MS_CAN_Low: J_CN_4.1, U_CN_1.4; also elsewhere on the board
Pin12: J_CN_7.3, U_CN_1.15
Pin13: J_CN_7.4, U_CN_1.5
Pin14_ISO15765_CAN_BUS_Low: J_CN_5.1, U_CN_1.12; also elsewhere on the board
Pin15_ISO9141_L-Line: J_CN_2.1, U_CN_1.7; also elsewhere on the board

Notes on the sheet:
OBD Connector into Reader through DB15-HD
Reference: https://components101.com/sites/default/files/component_pin/OBD2-Connector-Pinout.png
OBD-II Connector/Data Link Connector

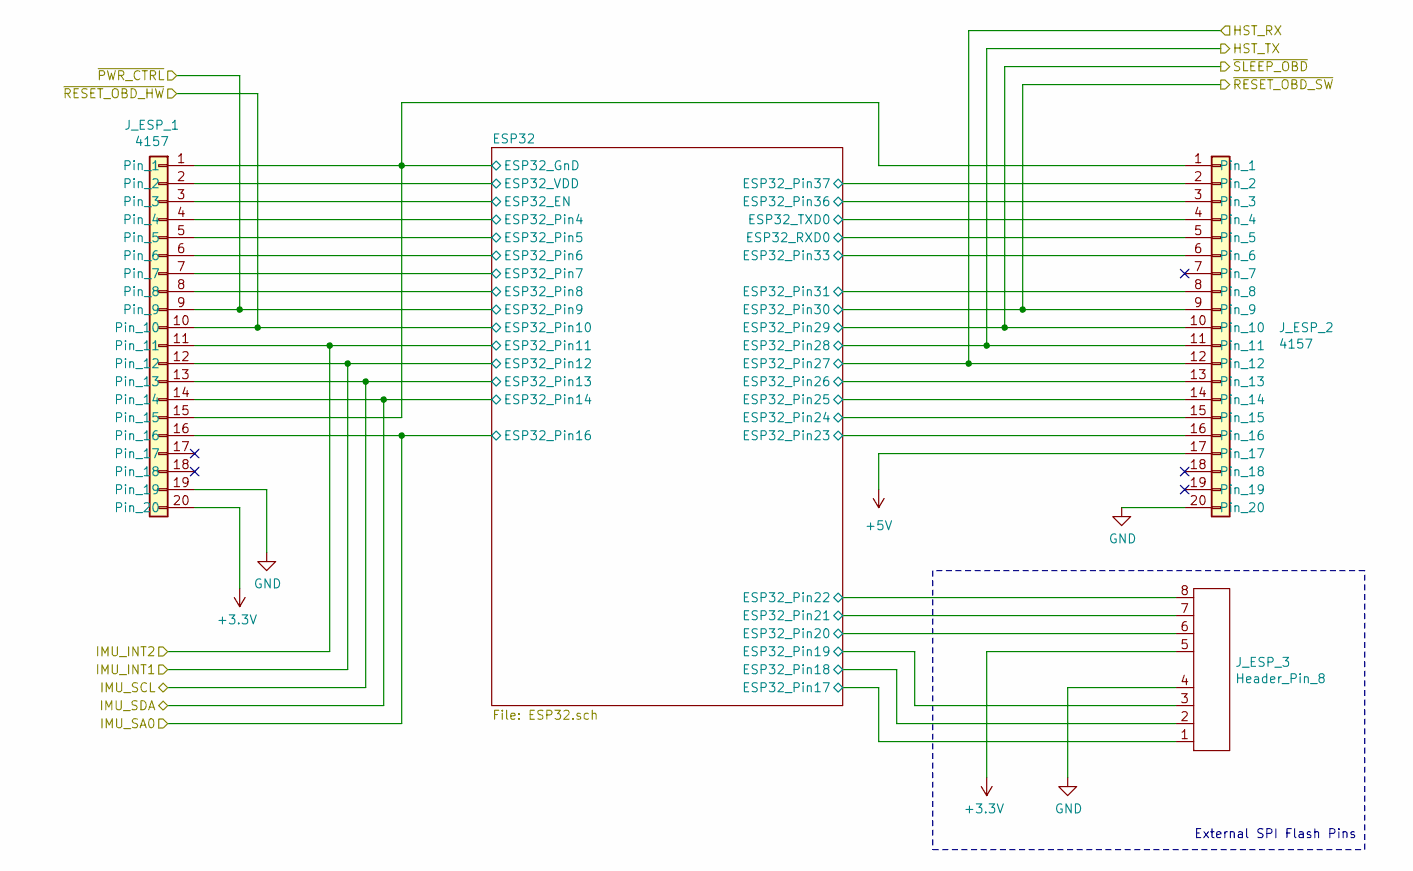
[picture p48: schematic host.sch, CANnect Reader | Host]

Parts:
J_ESP_1, J_ESP_2: 4157; PinSocket_1x20_P2.54mm_Vertical; Part Name 4157; digikeypn 1528-2929-ND
J_ESP_3: Header_Pin_8; PinHeader_1x08_P2.54mm_Vertical

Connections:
+3V3: J_ESP_1.2, J_ESP_1.20, J_ESP_3.5; also elsewhere on the board
+5V: J_ESP_2.17; also elsewhere on the board
/Host/ESP32/ESP32_EN: J_ESP_1.3; also elsewhere on the board
/Host/ESP32/ESP32_Pin4: J_ESP_1.4; also elsewhere on the board
/Host/ESP32/ESP32_Pin5: J_ESP_1.5; also elsewhere on the board
/Host/ESP32/ESP32_Pin6: J_ESP_1.6; also elsewhere on the board
/Host/ESP32/ESP32_Pin7: J_ESP_1.7; also elsewhere on the board
/Host/ESP32/ESP32_Pin8: J_ESP_1.8; also elsewhere on the board
/Host/ESP32/ESP32_Pin17: J_ESP_3.1; also elsewhere on the board
/Host/ESP32/ESP32_Pin18: J_ESP_3.2; also elsewhere on the board
/Host/ESP32/ESP32_Pin19: J_ESP_3.3; also elsewhere on the board
/Host/ESP32/ESP32_Pin20: J_ESP_3.6; also elsewhere on the board
/Host/ESP32/ESP32_Pin21: J_ESP_3.7; also elsewhere on the board
/Host/ESP32/ESP32_Pin22: J_ESP_3.8; also elsewhere on the board
/Host/ESP32/ESP32_Pin23: J_ESP_2.16; also elsewhere on the board
/Host/ESP32/ESP32_Pin24: J_ESP_2.15; also elsewhere on the board
/Host/ESP32/ESP32_Pin25: J_ESP_2.14; also elsewhere on the board
/Host/ESP32/ESP32_Pin26: J_ESP_2.13; also elsewhere on the board
/Host/ESP32/ESP32_Pin31: J_ESP_2.8; also elsewhere on the board
/Host/ESP32/ESP32_Pin33: J_ESP_2.6; also elsewhere on the board
/Host/ESP32/ESP32_Pin36: J_ESP_2.3; also elsewhere on the board
/Host/ESP32/ESP32_Pin37: J_ESP_2.2; also elsewhere on the board
/Host/ESP32/ESP32_RXD0: J_ESP_2.5; also elsewhere on the board
/Host/ESP32/ESP32_TXD0: J_ESP_2.4; also elsewhere on the board
/Host/HST_RX: J_ESP_2.12; also elsewhere on the board
/Host/HST_TX: J_ESP_2.11; also elsewhere on the board
/Host/IMU_INT1: J_ESP_1.12; also elsewhere on the board
/Host/IMU_INT2: J_ESP_1.11; also elsewhere on the board
/Host/IMU_SA0: J_ESP_1.16; also elsewhere on the board
/Host/IMU_SCL: J_ESP_1.13; also elsewhere on the board
/Host/IMU_SDA: J_ESP_1.14; also elsewhere on the board
/Host/~PWR_CTRL~: J_ESP_1.9; also elsewhere on the board
/Host/~RESET_OBD_HW~: J_ESP_1.10; also elsewhere on the board
/Host/~RESET_OBD_SW~: J_ESP_2.9; also elsewhere on the board
/Host/~SLEEP_OBD~: J_ESP_2.10; also elsewhere on the board
Pin4_GnD_Chassis: J_ESP_1.1, J_ESP_1.15, J_ESP_1.19, J_ESP_2.1, J_ESP_2.20, J_ESP_3.4; also elsewhere on the board

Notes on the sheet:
External SPI Flash Pins

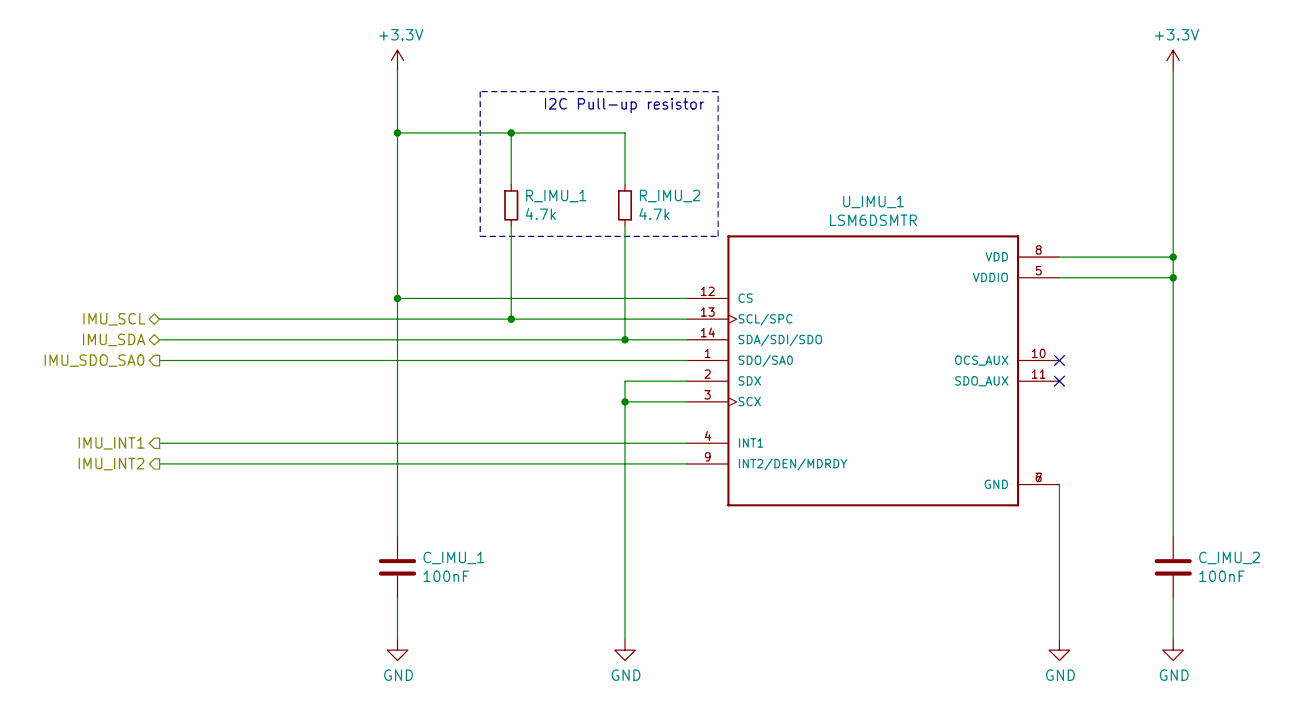
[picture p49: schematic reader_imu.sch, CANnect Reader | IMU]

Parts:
C_IMU_1, C_IMU_2: 100nF; CAPC1608X90N; Part Name C1608X7R2A103K080AA; digikeypn 445-1304-1-ND
R_IMU_1, R_IMU_2: 4.7k; RESC1608X55N; Part Name RT0603DRD074K7L; digikeypn 311-4.7KDCT-ND
U_IMU_1: LSM6DSMTR; PQFN50P300X250X86-14N; Part Name LSM6DSMTR; digikeypn 497-16696-1-ND

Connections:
+3V3: C_IMU_1.1, C_IMU_2.1, R_IMU_1.1, R_IMU_2.1, U_IMU_1.5 (VDDIO), U_IMU_1.8 (VDD), U_IMU_1.12 (CS); also elsewhere on the board
/Host/IMU_INT1: U_IMU_1.4 (INT1); also elsewhere on the board
/Host/IMU_INT2: U_IMU_1.9 (INT2/DEN/MDRDY); also elsewhere on the board
/Host/IMU_SA0: U_IMU_1.1 (SDO/SA0); also elsewhere on the board
/Host/IMU_SCL: R_IMU_1.2, U_IMU_1.13 (SCL/SPC); also elsewhere on the board
/Host/IMU_SDA: R_IMU_2.2, U_IMU_1.14 (SDA/SDI/SDO); also elsewhere on the board
Pin4_GnD_Chassis: C_IMU_1.2, C_IMU_2.2, U_IMU_1.2 (SDX), U_IMU_1.3 (SCX), U_IMU_1.6 (GND), U_IMU_1.7 (GND); also elsewhere on the board

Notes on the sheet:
I2C Pull-up resistor

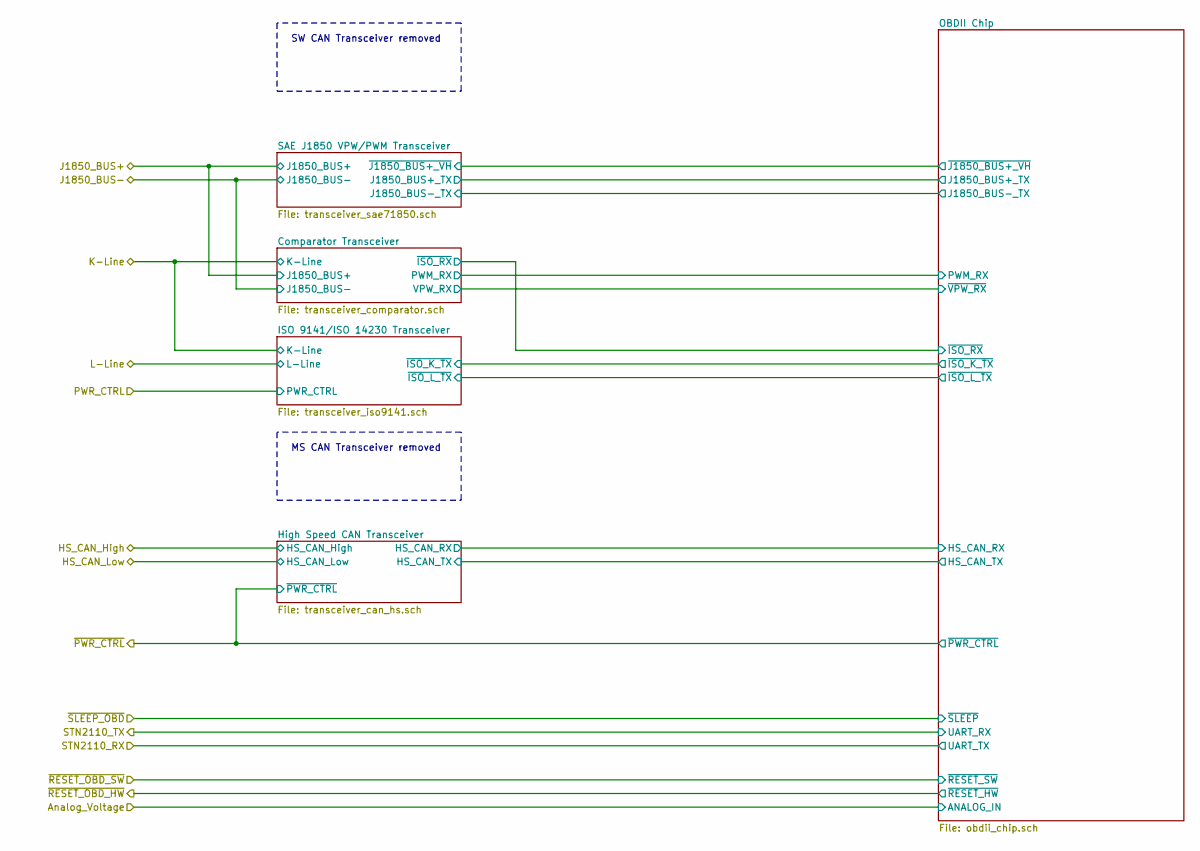
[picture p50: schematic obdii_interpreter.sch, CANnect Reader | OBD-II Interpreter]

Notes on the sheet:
SW CAN Transceiver removed
MS CAN Transceiver removed

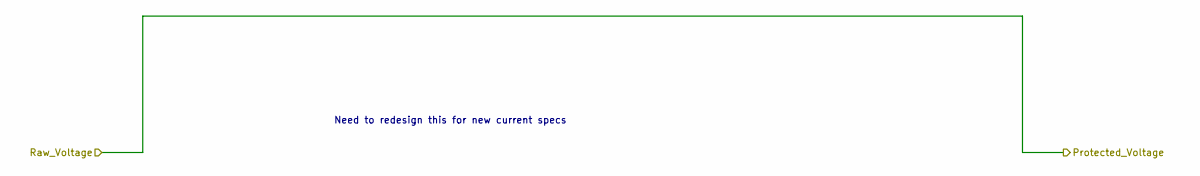
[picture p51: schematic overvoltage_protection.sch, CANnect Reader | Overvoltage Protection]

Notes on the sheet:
Need to redesign this for new current specs

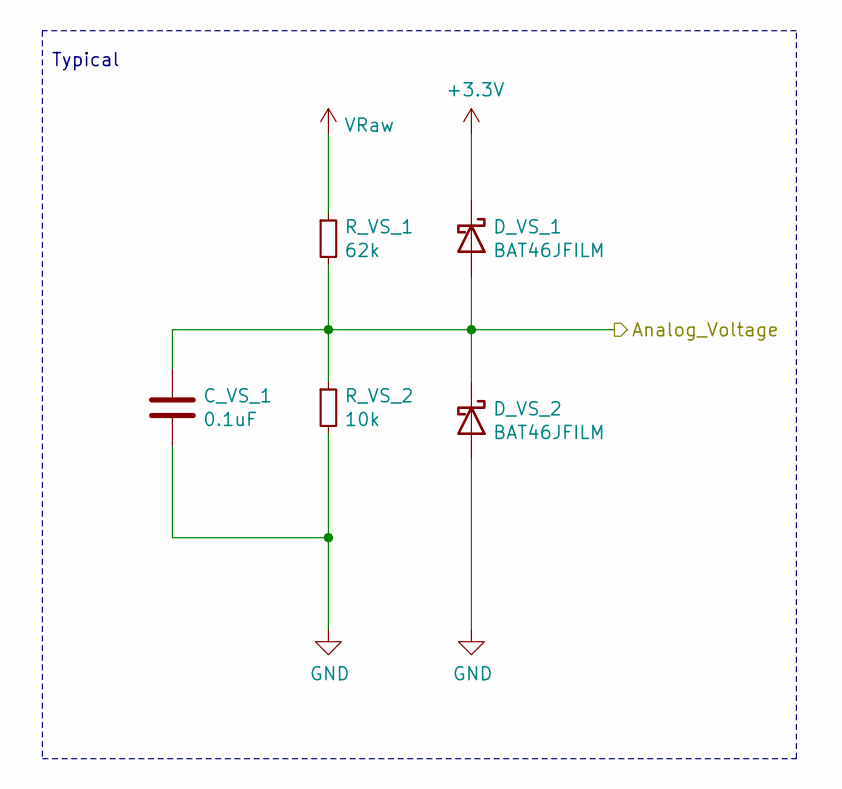
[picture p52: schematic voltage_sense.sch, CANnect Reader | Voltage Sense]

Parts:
C_VS_1: 0.1uF; CAPC1608X90; Part Name CC0603JRX7R8BB104; digikeypn 311-1777-1-ND
D_VS_1, D_VS_2: BAT46JFILM; Part Name BAT46JFILM; digikeypn 497-6653-1-ND
R_VS_1: 62k; RESC2012X60N; Part Name RT0805FRE0762KL; digikeypn 13-RT0805FRE0762KLCT-ND
R_VS_2: 10k; RESC1608X55N; Part Name RT0603FRE0710KL; digikeypn YAG2321CT-ND

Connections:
+3V3: D_VS_1.1 (K); also elsewhere on the board
/OBDII Interpreter/Analog_Voltage: C_VS_1.1, D_VS_1.2 (A), D_VS_2.1 (K), R_VS_1.2, R_VS_2.1; also elsewhere on the board
Pin4_GnD_Chassis: C_VS_1.2, D_VS_2.2 (A), R_VS_2.2; also elsewhere on the board

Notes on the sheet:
Typical

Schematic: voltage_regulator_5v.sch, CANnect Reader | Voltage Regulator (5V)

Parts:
C_VR1_1: 4.7uF; C1206C475K3RACAUTO; Part Name C1206C475K3RACAUTO; digikeypn 399-7029-1-ND
C_VR1_2: 0.1uF; CAPC1608X90; Part Name CC0603JRX7R8BB104; digikeypn 311-1777-1-ND
C_VR1_3: 1uF; 0603; Part Name C0603C105K4RACTU; digikeypn 399-7847-1-ND
L_VR1: 4.7uH; CV201210-4R7K; Part Name CV201210-4R7K; digikeypn CV201210-4R7KCT-ND
U_VR1: MAX25276ATCA_VY+; MAX25276ATCA&slash_VY&plus_; Part Name MAX25276ATCA/VY+; digikeypn 175-MAX25276ATCA/VY+-ND

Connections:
+5V: L_VR1.1, U_VR1.9 (OUT); also elsewhere on the board
unnamed: C_VR1_1.2, U_VR1.4 (SUP)
unnamed: C_VR1_2.1, U_VR1.3 (BST)
unnamed: C_VR1_2.2, L_VR1.2, U_VR1.5 (LX)
unnamed: C_VR1_3.1, U_VR1.8 (FB), U_VR1.10 (BIAS)
Pin4_GnD_Chassis: C_VR1_1.1, C_VR1_3.2, U_VR1.6 (PGND), U_VR1.7 (AGND), U_VR1.13 (EPAD); also elsewhere on the board

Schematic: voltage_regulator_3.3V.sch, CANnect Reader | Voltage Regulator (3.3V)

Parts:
C_VR2_1: 4.7uF; C1206C475K3RACAUTO; Part Name C1206C475K3RACAUTO; digikeypn 399-7029-1-ND
C_VR2_2: 0.1uF; CAPC1608X90; Part Name CC0603JRX7R8BB104; digikeypn 311-1777-1-ND
C_VR2_3: 1uF; 0603; Part Name C0603C105K4RACTU; digikeypn 399-7847-1-ND
L_VR2: 4.7uH; CV201210-4R7K; Part Name CV201210-4R7K; digikeypn CV201210-4R7KCT-ND
R_VR2_1, R_VR2_2: 100k; RESC1608X55N; Part Name RT0603DRE07100KL; digikeypn 311-2395-1-ND
R_VR2_3: 115k; RESC1608X55N; Part Name RT0402DRE07115KL; digikeypn 311-2218-1-ND
U_VR2: MAX25276ATCA_VY+; MAX25276ATCA&slash_VY&plus_; Part Name MAX25276ATCA/VY+; digikeypn 175-MAX25276ATCA/VY+-ND

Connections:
+3V3: L_VR2.1, R_VR2_3.1, U_VR2.9 (OUT); also elsewhere on the board
unnamed: C_VR2_1.1, U_VR2.4 (SUP)
unnamed: C_VR2_2.1, U_VR2.3 (BST)
unnamed: C_VR2_2.2, L_VR2.2, U_VR2.5 (LX)
unnamed: C_VR2_3.1, U_VR2.10 (BIAS)
unnamed: R_VR2_1.2, R_VR2_2.1, R_VR2_3.2, U_VR2.8 (FB)
Pin4_GnD_Chassis: C_VR2_1.2, C_VR2_3.2, R_VR2_1.1, R_VR2_2.2, U_VR2.6 (PGND), U_VR2.7 (AGND), U_VR2.13 (EPAD); also elsewhere on the board

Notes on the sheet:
Resistor Divider to convert 5V to 3.3V

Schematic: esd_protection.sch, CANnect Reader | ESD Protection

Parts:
D_ESD_1, D_ESD_2: PESD2CAN,215; SOT95P230X110-3N; Part Name PESD2CAN,215; digikeypn 1727-3891-1-ND
D_ESD_3: MMBZ27VCLFHT116; Part Name MMBZ27VCLFHT116; digikeypn MMBZ27VCLFHT116CT-ND
D_ESD_4, D_ESD_5: MMBZ27VALT3G; SOT95P237X111-3N; Part Name MMBZ27VALT3G; digikeypn MMBZ27VALT3GOSCT-ND

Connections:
Pin1_SW_CAN: D_ESD_3.2; also elsewhere on the board
Pin2_SAE_J1850_BUS+: D_ESD_5.1; also elsewhere on the board
Pin3_MS_CAN_High: D_ESD_2.1; also elsewhere on the board
Pin4_GnD_Chassis: D_ESD_1.3, D_ESD_2.3, D_ESD_3.1, D_ESD_4.3, D_ESD_5.3; also elsewhere on the board
Pin6_ISO15765_CAN_BUS_High: D_ESD_1.1; also elsewhere on the board
Pin7_ISO9141_K-Line: D_ESD_4.1; also elsewhere on the board
Pin10_SAE_J1850_BUS-: D_ESD_5.2; also elsewhere on the board
Pin11_MS_CAN_Low: D_ESD_2.2; also elsewhere on the board
Pin14_ISO15765_CAN_BUS_Low: D_ESD_1.2; also elsewhere on the board
Pin15_ISO9141_L-Line: D_ESD_4.2; also elsewhere on the board

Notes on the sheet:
ESD Protection (IEC61000-4-2 Level 4)

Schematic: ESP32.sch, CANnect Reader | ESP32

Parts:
CP_ESP_1: 100uF; UCB0J101MCL1GS; Part Name UCB0J101MCL1GS; digikeypn 493-9357-1-ND
C_ESP_1, C_ESP_2: 0.1uF; CAPC1608X90; Part Name CC0603JRX7R8BB104; digikeypn 311-1777-1-ND
LED_ESP_1: Bluetooth Status; LED_0603_1608Metric; Part Name 150060VS75000; digikeypn 732-4980-1-ND
R_ESP_1, R_ESP_4: 10k; RESC1608X55N; Part Name RT0603FRE0710KL; digikeypn YAG2321CT-ND
R_ESP_2, R_ESP_3, R_ESP_5: 500; RESC1508X55N; Part Name MCT0603PD4990DP500; digikeypn 749-1523-1-ND
SW_ESP_1, SW_ESP_2: PTS647SK38SMTR2LFS; Part Name PTS 647 SK38 SMTR2 LFS; digikeypn PTS647SK38SMTR2LFSCT-ND
U_ESP_1: ESP32-WROOM-32D; CANtech-ESP32-WROOM-32; Part Name USB4110-GF-A; digikeypn 1965-ESP32-WROOM-32D(4MB)CT-ND

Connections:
+3V3: CP_ESP_1.1, R_ESP_1.1, R_ESP_4.2, U_ESP_1.2 (VDD); also elsewhere on the board
/Host/ESP32/ESP32_EN: C_ESP_1.1, SW_ESP_1.2, U_ESP_1.3 (EN); also elsewhere on the board
/Host/ESP32/ESP32_Pin4: U_ESP_1.4 (SENSOR_VP); also elsewhere on the board
/Host/ESP32/ESP32_Pin5: U_ESP_1.5 (SENSOR_VN); also elsewhere on the board
/Host/ESP32/ESP32_Pin6: U_ESP_1.6 (IO34); also elsewhere on the board
/Host/ESP32/ESP32_Pin7: U_ESP_1.7 (IO35); also elsewhere on the board
/Host/ESP32/ESP32_Pin8: U_ESP_1.8 (IO32); also elsewhere on the board
/Host/ESP32/ESP32_Pin17: U_ESP_1.17 (SHD/SD2); also elsewhere on the board
/Host/ESP32/ESP32_Pin18: U_ESP_1.18 (SWP/SD3); also elsewhere on the board
/Host/ESP32/ESP32_Pin19: U_ESP_1.19 (SCS/CMD); also elsewhere on the board
/Host/ESP32/ESP32_Pin20: U_ESP_1.20 (SCK/CLK); also elsewhere on the board
/Host/ESP32/ESP32_Pin21: U_ESP_1.21 (SDO/SD0); also elsewhere on the board
/Host/ESP32/ESP32_Pin22: U_ESP_1.22 (SDI/SD1); also elsewhere on the board
/Host/ESP32/ESP32_Pin23: U_ESP_1.23 (IO15); also elsewhere on the board
/Host/ESP32/ESP32_Pin24: R_ESP_3.2, U_ESP_1.24 (IO2); also elsewhere on the board
/Host/ESP32/ESP32_Pin25: C_ESP_2.1, SW_ESP_2.3, U_ESP_1.25 (IO0); also elsewhere on the board
/Host/ESP32/ESP32_Pin26: U_ESP_1.26 (IO4); also elsewhere on the board
/Host/ESP32/ESP32_Pin31: U_ESP_1.31 (IO19); also elsewhere on the board
/Host/ESP32/ESP32_Pin33: U_ESP_1.33 (IO21); also elsewhere on the board
/Host/ESP32/ESP32_Pin36: U_ESP_1.36 (IO22); also elsewhere on the board
/Host/ESP32/ESP32_Pin37: U_ESP_1.37 (IO23); also elsewhere on the board
/Host/ESP32/ESP32_RXD0: U_ESP_1.34 (RXD0/IO3); also elsewhere on the board
/Host/ESP32/ESP32_TXD0: U_ESP_1.35 (TXD0/IO1); also elsewhere on the board
/Host/HST_RX: U_ESP_1.27 (IO16); also elsewhere on the board
/Host/HST_TX: U_ESP_1.28 (IO17); also elsewhere on the board
/Host/IMU_INT1: U_ESP_1.12 (IO27); also elsewhere on the board
/Host/IMU_INT2: U_ESP_1.11 (IO26); also elsewhere on the board
/Host/IMU_SA0: U_ESP_1.16 (IO13); also elsewhere on the board
/Host/IMU_SCL: U_ESP_1.13 (IO14); also elsewhere on the board
/Host/IMU_SDA: U_ESP_1.14 (IO12); also elsewhere on the board
/Host/~PWR_CTRL~: U_ESP_1.9 (IO33); also elsewhere on the board
/Host/~RESET_OBD_HW~: U_ESP_1.10 (IO25); also elsewhere on the board
/Host/~RESET_OBD_SW~: U_ESP_1.30 (IO18); also elsewhere on the board
/Host/~SLEEP_OBD~: U_ESP_1.29 (IO5); also elsewhere on the board
unnamed: LED_ESP_1.2 (A), R_ESP_3.1
unnamed: R_ESP_1.2, SW_ESP_1.1
unnamed: R_ESP_2.1, SW_ESP_1.3
unnamed: R_ESP_4.1, SW_ESP_2.2
unnamed: R_ESP_5.2, SW_ESP_2.4
Pin4_GnD_Chassis: CP_ESP_1.2, C_ESP_1.2, C_ESP_2.2, LED_ESP_1.1 (K), R_ESP_2.2, R_ESP_5.1, U_ESP_1.1 (GND), U_ESP_1.15 (GND), U_ESP_1.38 (GND), U_ESP_1.39 (GND); also elsewhere on the board

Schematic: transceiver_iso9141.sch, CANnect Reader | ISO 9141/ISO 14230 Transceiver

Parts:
Q_ISO_1, Q_ISO_2: IRLML5103TRPBF; Part Name IRLML5103TRPBF; digikeypn IRLML5103PBFCT-ND
Q_ISO_3, Q_ISO_4: MMBT3904WT1G; SOT-23; Part Name MMBT3904WT1G; digikeypn MMBT3904WT1GOSCT-ND
R_ISO_1, R_ISO_2: 1k; RC1608F102CS; Part Name RC1608F102CS; digikeypn 1276-3484-1-ND
R_ISO_3, R_ISO_4: 510k; RESC2012X50N; Part Name RR1220P-514-D; digikeypn RR12P510KDCT-ND

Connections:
/OBDII Interpreter/ISO 9141/ISO 14230 Transceiver/~ISO_K_TX~: R_ISO_1.2; also elsewhere on the board
/OBDII Interpreter/ISO 9141/ISO 14230 Transceiver/~ISO_L_TX~: R_ISO_2.2; also elsewhere on the board
/OBDII Interpreter/PWR_CTRL: Q_ISO_1.1, Q_ISO_2.1; also elsewhere on the board
unnamed: Q_ISO_1.2, R_ISO_3.2
unnamed: Q_ISO_2.2, R_ISO_4.2
unnamed: Q_ISO_3.1 (B), R_ISO_1.1
unnamed: Q_ISO_4.1 (B), R_ISO_2.1
Pin4_GnD_Chassis: Q_ISO_3.2 (E), Q_ISO_4.2 (E); also elsewhere on the board
Pin7_ISO9141_K-Line: Q_ISO_3.3 (C), R_ISO_3.1; also elsewhere on the board
Pin15_ISO9141_L-Line: Q_ISO_4.3 (C), R_ISO_4.1; also elsewhere on the board

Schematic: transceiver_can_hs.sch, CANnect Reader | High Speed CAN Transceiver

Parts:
C_HSCAN_1, C_HSCAN_2: 560pF; CAPC1608X90; Part Name CC0603JRX7R9BB561; digikeypn 311-4020-1-ND‎
C_HSCAN_3: 1uF; 0603; Part Name C0603C105K4RACTU; digikeypn 399-7847-1-ND
Q_HSCAN_1: NX7002AK,215; SOT95P230X110-3N; Part Name NX7002AK,215; digikeypn 1727-1289-1-ND
R_HSCAN_1: 100k; RESC1608X55N; Part Name RT0603DRE07100KL; digikeypn 311-2395-1-ND
R_HSCAN_2, R_HSCAN_3: 100; RESC3216X70N; Part Name ERJ-8ENF1000V; digikeypn P100FCT-ND
U_HSCAN_1: MCP2562-H_MF; MCP2562-H&slash_MF; Part Name MCP2562-H_MF; digikeypn MCP2562-H/MF-ND

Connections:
+3V3: R_HSCAN_1.1, U_HSCAN_1.5 (VIO); also elsewhere on the board
+5V: C_HSCAN_3.2, U_HSCAN_1.3 (VDD); also elsewhere on the board
/Host/~PWR_CTRL~: Q_HSCAN_1.1; also elsewhere on the board
/OBDII Interpreter/High Speed CAN Transceiver/HS_CAN_RX: U_HSCAN_1.4 (RXD); also elsewhere on the board
/OBDII Interpreter/High Speed CAN Transceiver/HS_CAN_TX: U_HSCAN_1.1 (TXD); also elsewhere on the board
unnamed: C_HSCAN_1.1, R_HSCAN_2.2
unnamed: C_HSCAN_2.1, R_HSCAN_3.2
unnamed: Q_HSCAN_1.3, R_HSCAN_1.2, U_HSCAN_1.8 (STBY)
Pin4_GnD_Chassis: C_HSCAN_1.2, C_HSCAN_2.2, C_HSCAN_3.1, Q_HSCAN_1.2, U_HSCAN_1.2 (VSS), U_HSCAN_1.9 (EPAD); also elsewhere on the board
Pin6_ISO15765_CAN_BUS_High: R_HSCAN_3.1, U_HSCAN_1.7 (CANH); also elsewhere on the board
Pin14_ISO15765_CAN_BUS_Low: R_HSCAN_2.1, U_HSCAN_1.6 (CANL); also elsewhere on the board

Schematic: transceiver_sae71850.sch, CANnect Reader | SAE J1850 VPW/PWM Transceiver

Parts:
C_J1850_1: 0.1uF; CAPC1608X90; Part Name CC0603JRX7R8BB104; digikeypn 311-1777-1-ND
D_J1850_1, D_J1850_2, D_J1850_3: BAT46JFILM; Part Name BAT46JFILM; digikeypn 497-6653-1-ND
Q_J1850_1, Q_J1850_2, Q_J1850_4: NX7002AK,215; SOT95P230X110-3N; Part Name NX7002AK,215; digikeypn 1727-1289-1-ND
Q_J1850_3: RSC002P03T316; Part Name RSC002P03T316; digikeypn RSC002P03T316CT-ND
R_J1850_1, R_J1850_5, R_J1850_7, R_J1850_8: 10k; RESC1608X55N; Part Name RT0603FRE0710KL; digikeypn YAG2321CT-ND
R_J1850_2: 1.5k; RESC1607X60N; Part Name RC0603FR-071K5L; digikeypn 311-1.50KHRCT-ND
R_J1850_3: 866; RESC3216X70N; Part Name ERJ-8ENF8660V; digikeypn P866FCT-ND
R_J1850_4: 374; RESC3216X70N; Part Name ERJ-8ENF3740V; digikeypn P374FCT-ND
R_J1850_6: 240; RESC3216X70N; Part Name ERJ-8ENF2400V; digikeypn P240FCT-ND
U_J1850_1: LM317LDR2G; SOIC127P600X175-8N; Part Name LM317LDR2G; digikeypn LM317LDR2GOSCT-ND

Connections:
+5V_SW: D_J1850_3.2 (A); also elsewhere on the board
+V_J1850: Q_J1850_3.2, R_J1850_2.1, R_J1850_6.1, U_J1850_1.2 (VOUT)
/OBDII Interpreter/OBDII Chip/J1850_BUS+_TX: Q_J1850_2.1, R_J1850_1.1; also elsewhere on the board
/OBDII Interpreter/OBDII Chip/J1850_BUS-_TX: Q_J1850_4.1, R_J1850_7.1; also elsewhere on the board
/OBDII Interpreter/OBDII Chip/~J1850_BUS+_VH~: Q_J1850_1.1; also elsewhere on the board
unnamed: C_J1850_1.1, U_J1850_1.1 (VIN)
unnamed: D_J1850_1.2 (A), Q_J1850_3.3
unnamed: D_J1850_2.2 (A), R_J1850_5.2
unnamed: D_J1850_3.1 (K), R_J1850_8.1
unnamed: Q_J1850_1.3, R_J1850_3.1, R_J1850_4.1
unnamed: Q_J1850_2.3, Q_J1850_3.1, R_J1850_2.2
unnamed: R_J1850_3.2, R_J1850_6.2, U_J1850_1.4 (ADJUST)
Pin2_SAE_J1850_BUS+: D_J1850_1.1 (K), R_J1850_5.1; also elsewhere on the board
Pin4_GnD_Chassis: C_J1850_1.2, D_J1850_2.1 (K), Q_J1850_1.2, Q_J1850_2.2, Q_J1850_4.2, R_J1850_1.2, R_J1850_4.2, R_J1850_7.2; also elsewhere on the board
Pin10_SAE_J1850_BUS-: Q_J1850_4.3, R_J1850_8.2; also elsewhere on the board

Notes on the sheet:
SAE J1850 Power Supply for WM (5V) and VPW (7V)
J1850 BUS+ Transmitter
J1850 BUS- Transmitter

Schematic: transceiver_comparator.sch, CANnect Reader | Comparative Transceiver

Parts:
R_COMP_1, R_COMP_2, R_COMP_3, R_COMP_4, R_COMP_5, R_COMP_6, R_COMP_7, R_COMP_9, R_COMP_10, R_COMP_11: 10k; RESC1608X55N; Part Name RT0603FRE0710KL; digikeypn YAG2321CT-ND
R_COMP_8: 2.7k; RESC1608X55N; Part Name CRCW06032K70FKEAC; digikeypn 541-5328-1-ND
U_COMP_1: LM339N_NOPB; LM339N&slash_NOPB; Part Name LM339N_NOPB; digikeypn 296-39010-5-ND

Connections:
+3V3: R_COMP_4.1, R_COMP_5.1, R_COMP_11.1; also elsewhere on the board
+5V_SW: R_COMP_8.1; also elsewhere on the board
+12V_SW: R_COMP_6.1, U_COMP_1.3 (VCC); also elsewhere on the board
/OBDII Interpreter/Comparator Transceiver/PWM_RX: R_COMP_4.2, U_COMP_1.2 (2OUT); also elsewhere on the board
/OBDII Interpreter/Comparator Transceiver/VPW_RX: R_COMP_11.2, U_COMP_1.14 (OUT3); also elsewhere on the board
/OBDII Interpreter/Comparator Transceiver/~ISO_RX~: R_COMP_5.2, U_COMP_1.1 (1OUT); also elsewhere on the board
unnamed: R_COMP_1.2, U_COMP_1.5 (2IN+)
unnamed: R_COMP_2.2, U_COMP_1.6 (1IN-)
unnamed: R_COMP_3.1, U_COMP_1.4 (2IN-)
unnamed: R_COMP_6.2, R_COMP_7.1, U_COMP_1.7 (1IN+)
unnamed: R_COMP_8.2, R_COMP_9.1, U_COMP_1.8 (3IN-)
unnamed: R_COMP_10.1, U_COMP_1.9 (3IN+)
Pin2_SAE_J1850_BUS+: R_COMP_1.1, R_COMP_10.2; also elsewhere on the board
Pin4_GnD_Chassis: R_COMP_7.2, R_COMP_9.2, U_COMP_1.12 (GND); also elsewhere on the board
Pin7_ISO9141_K-Line: R_COMP_2.1; also elsewhere on the board
Pin10_SAE_J1850_BUS-: R_COMP_3.2; also elsewhere on the board

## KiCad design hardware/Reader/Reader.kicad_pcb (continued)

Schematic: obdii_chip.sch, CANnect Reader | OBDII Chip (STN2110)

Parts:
CP_STN_1: 10uF; CP_Elec_4x5.8; Part Name EEEFP1E100AR; digikeypn PCE4539CT-ND
C_STN_1, C_STN_4, C_STN_5, C_STN_6: 1uF; 0603; Part Name C0603C105K4RACTU; digikeypn 399-7847-1-ND
C_STN_2, C_STN_3: 30pF; CAPC1608X90N; Part Name C0603C300J5GACTU; digikeypn 399-9057-1-ND
J_STN_1, J_STN_2, J_STN_4, J_STN_5, J_STN_6: Header_Pin_2; PinHeader_1x02_P2.54mm_Vertical
LED_STN_1: Status; LED_0603_1608Metric; Part Name 150060RS75000; digikeypn 732-4978-1-ND
LED_STN_2: OBD Activity; LED_0603_1608Metric; Part Name 150060YS75000; digikeypn 732-4981-1-ND
LED_STN_3: Host Activity; LED_0603_1608Metric; Part Name 150060VS75000; digikeypn 732-4980-1-ND
R_STN_1, R_STN_2, R_STN_3: 330; RESC3216X70N; Part Name ERJ-8ENF3300V; digikeypn P330FCT-ND
R_STN_4: 1k; RC1608F102CS; Part Name RC1608F102CS; digikeypn 1276-3484-1-ND
R_STN_5, R_STN_6, R_STN_9, R_STN_13: 100k; RESC1608X55N; Part Name RT0603DRE07100KL; digikeypn 311-2395-1-ND
R_STN_7, R_STN_8: 1.5k; RESC1607X60N; Part Name RC0603FR-071K5L; digikeypn 311-1.50KHRCT-ND
R_STN_10: 500; RESC1508X55N; Part Name MCT0603PD4990DP500; digikeypn 749-1523-1-ND
R_STN_11: 10k; RESC1608X55N; Part Name RT0603FRE0710KL; digikeypn YAG2321CT-ND
R_STN_12: 10; RESC1608X55N; Part Name RE0603FRE0710RL; digikeypn 13-RE0603FRE0710RLCT-ND
SW_STN_1: PTS647SK38SMTR2LFS; Part Name PTS 647 SK38 SMTR2 LFS; digikeypn PTS647SK38SMTR2LFSCT-ND
U_STN_1: STN2120; CANtech-STN2120-QFN-44-1EP_8x8mm; Part Name STN2120
Y_STN_1: ECS-2033-160-AU (16MHz); OSC_ECS-2033-160-AU; Part Name ECS-2033-160-AU (16MHz); digikeypn XC1858CT-ND

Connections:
+3V3: C_STN_1.1, C_STN_5.1, C_STN_6.1, J_STN_4.2, J_STN_5.1, LED_STN_1.2 (A), LED_STN_2.2 (A), LED_STN_3.2 (A), R_STN_4.1, R_STN_5.2, R_STN_6.2, R_STN_7.1, R_STN_8.1, R_STN_9.2, R_STN_11.1, R_STN_12.1, R_STN_13.1, U_STN_1.28 (VDD), U_STN_1.40 (VDD), Y_STN_1.4 (VDD); also elsewhere on the board
/Host/HST_RX: J_STN_1.1, U_STN_1.5 (UART_RX); also elsewhere on the board
/Host/HST_TX: J_STN_1.2, R_STN_4.2, U_STN_1.4 (UART_TX); also elsewhere on the board
/Host/~PWR_CTRL~: U_STN_1.32 (~PWR_CTRL~/GP19); also elsewhere on the board
/Host/~RESET_OBD_HW~: C_STN_4.1, R_STN_2.2, SW_STN_1.2, U_STN_1.12 (~LED_OBD_ACT~/~RST_NVM~/GP22); also elsewhere on the board
/Host/~RESET_OBD_SW~: J_STN_6.1, R_STN_11.2, U_STN_1.18 (~RESET~); also elsewhere on the board
/Host/~SLEEP_OBD~: R_STN_13.2, U_STN_1.27 (~SLEEP~/GP18); also elsewhere on the board
/OBDII Interpreter/Analog_Voltage: U_STN_1.19 (ANALOG_IN); also elsewhere on the board
/OBDII Interpreter/Comparator Transceiver/PWM_RX: U_STN_1.23 (PWM_RX/GP0); also elsewhere on the board
/OBDII Interpreter/Comparator Transceiver/VPW_RX: U_STN_1.22 (VPW_RX/GP1); also elsewhere on the board
/OBDII Interpreter/Comparator Transceiver/~ISO_RX~: U_STN_1.21 (~ISO_RX~/GP5); also elsewhere on the board
/OBDII Interpreter/High Speed CAN Transceiver/HS_CAN_RX: J_STN_2.2, U_STN_1.10 (HS_CAN_RX/GP8); also elsewhere on the board
/OBDII Interpreter/High Speed CAN Transceiver/HS_CAN_TX: J_STN_2.1, U_STN_1.8 (HS_CAN_TX/GP9); also elsewhere on the board
/OBDII Interpreter/ISO 9141/ISO 14230 Transceiver/~ISO_K_TX~: U_STN_1.43 (~ISO_K_TX~/GP6); also elsewhere on the board
/OBDII Interpreter/ISO 9141/ISO 14230 Transceiver/~ISO_L_TX~: U_STN_1.44 (~ISO_L_TX~/GP7); also elsewhere on the board
/OBDII Interpreter/OBDII Chip/J1850_BUS+_TX: U_STN_1.24 (J1850_BUS+_TX/GP2); also elsewhere on the board
/OBDII Interpreter/OBDII Chip/J1850_BUS-_TX: U_STN_1.33 (J1850_BUS-_TX/GP3); also elsewhere on the board
/OBDII Interpreter/OBDII Chip/~J1850_BUS+_VH~: U_STN_1.25 (~J1850_BUS+_VH~/GP4); also elsewhere on the board
unnamed: CP_STN_1.1, U_STN_1.7 (VCAP)
unnamed: C_STN_2.2, U_STN_1.31 (OSC2), Y_STN_1.1 (TRI_STATE)
unnamed: C_STN_3.1, U_STN_1.30 (OSC1), Y_STN_1.3 (OUT)
unnamed: LED_STN_1.1 (K), R_STN_1.1
unnamed: LED_STN_2.1 (K), R_STN_2.1
unnamed: LED_STN_3.1 (K), R_STN_3.1
unnamed: R_STN_1.2, U_STN_1.14 (LED_STATUS/GP26)
unnamed: R_STN_3.2, U_STN_1.13 (~LED_HOST_ACT~/GP24)
unnamed: R_STN_5.1, U_STN_1.9 (MS_CAN_TX/GP11)
unnamed: R_STN_6.1, U_STN_1.11 (MS_CAN_RX/GP10)
unnamed: R_STN_7.2, U_STN_1.42 (SW_CAN_RX/GP12)
unnamed: R_STN_8.2, U_STN_1.41 (SW_CAN_TX/GP13)
unnamed: R_STN_9.1, SW_STN_1.1
unnamed: R_STN_10.1, SW_STN_1.3
Pin4_GnD_Chassis: CP_STN_1.2, C_STN_1.2, C_STN_2.1, C_STN_3.2, C_STN_4.2, C_STN_5.2, C_STN_6.2, J_STN_4.1, J_STN_5.2, J_STN_6.2, R_STN_10.2, U_STN_1.1 (GP28), U_STN_1.2 (GP29), U_STN_1.3 (GP30), U_STN_1.6 (VSS), U_STN_1.15 (GP31), U_STN_1.16 (AV_SS), U_STN_1.20 (GP32), U_STN_1.26 (GP33), U_STN_1.29 (VSS), U_STN_1.37 (GP34), U_STN_1.38 (GP35), U_STN_1.39 (VSS), U_STN_1.45 (PAD), Y_STN_1.2 (GND); also elsewhere on the board
VDDA: R_STN_12.2, U_STN_1.17 (AV_DD)

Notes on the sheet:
LED Indicators
Host Device
16Mhz Oscillator
Reset button

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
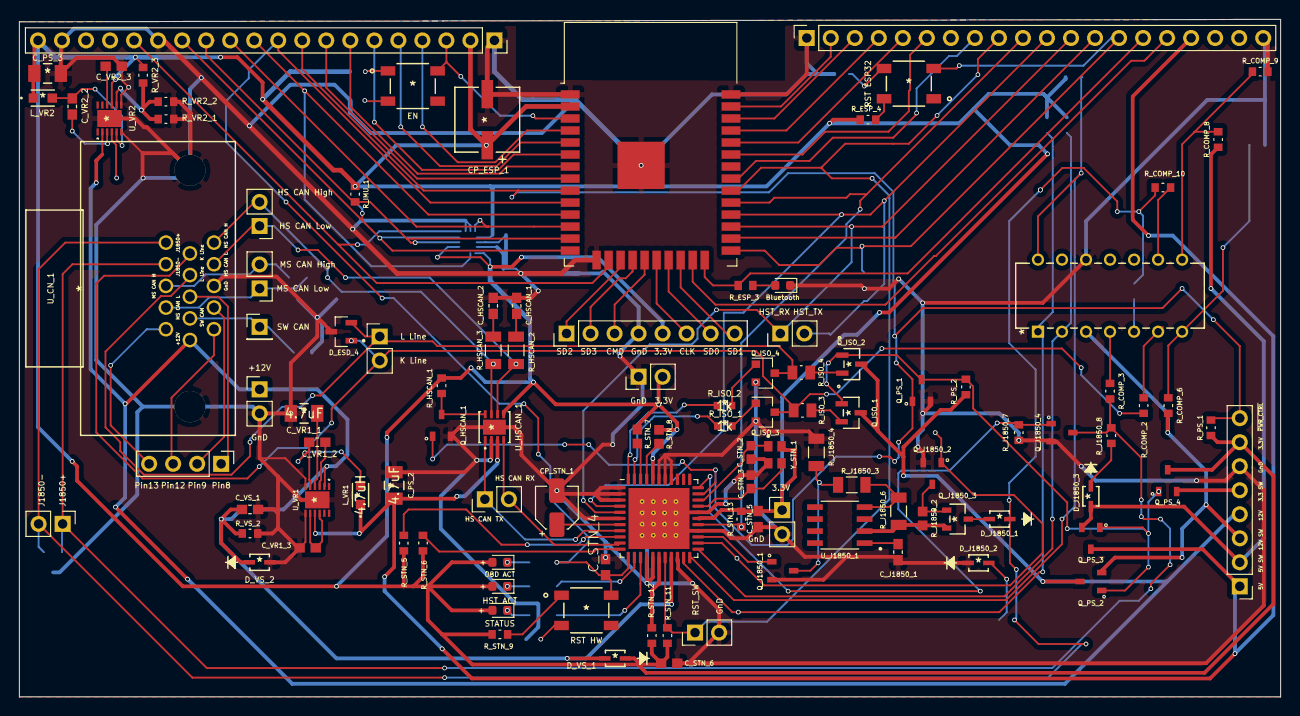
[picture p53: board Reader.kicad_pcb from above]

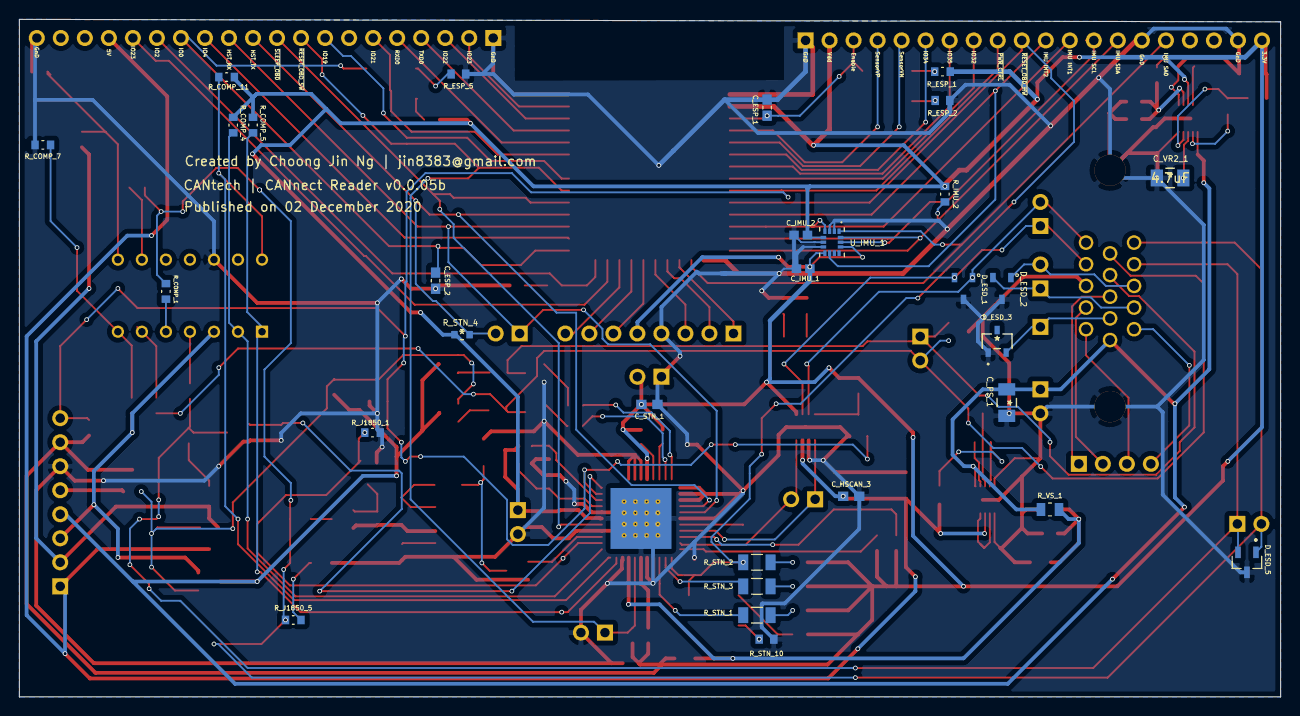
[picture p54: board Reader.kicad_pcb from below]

Board: 2 copper layers, 133.4 x 71.6 mm, 137 parts (30 on the bottom side), 115 nets.

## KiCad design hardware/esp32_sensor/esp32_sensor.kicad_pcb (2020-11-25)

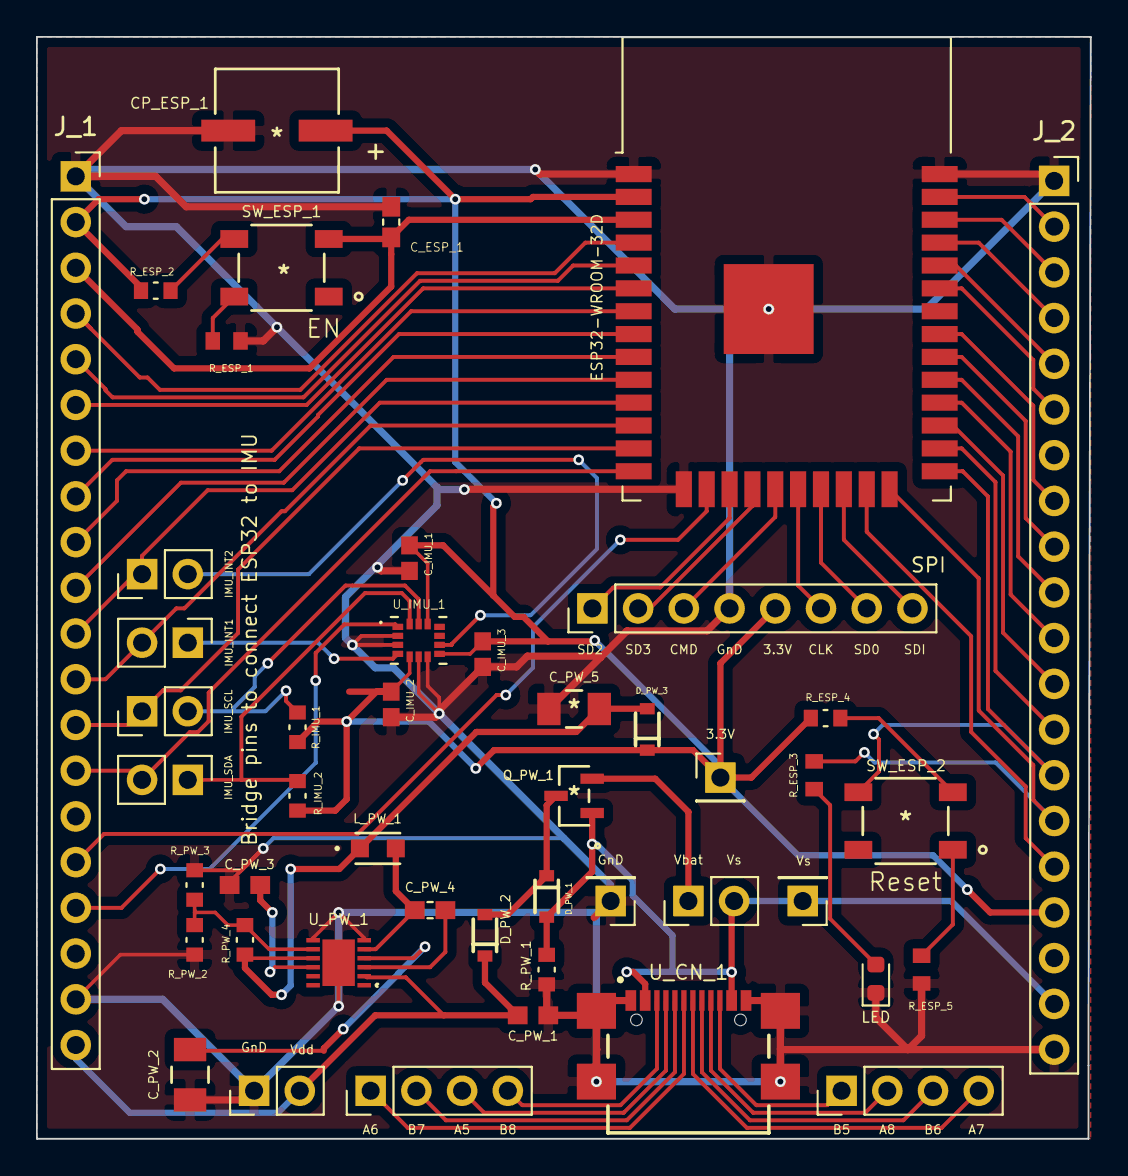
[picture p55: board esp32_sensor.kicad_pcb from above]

Board: 2 copper layers, 58.5 x 61.2 mm, 47 parts (0 on the bottom side), 63 nets.

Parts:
CP_ESP_1: 100uF; UCB0J101MCL1GS
C_ESP_1: 0.1uF; CAPC1608X90
C_IMU_1, C_IMU_2, C_IMU_3: 100nF; CAPC1608X90N
C_PW_1, C_PW_3: 1uF; 0603
C_PW_2, C_PW_5: 4.7uF; C1206C475K3RACAUTO
C_PW_4: 0.1uF; CAPC1608X90
D_PW_1, D_PW_2, D_PW_3: BAT20JFILM
J_1, J_2: 4157; PinSocket_1x20_P2.54mm_Vertical
J_3: SPI; PinHeader_1x08_P2.54mm_Vertical
J_4: IMU_INT2; PinHeader_1x02_P2.54mm_Vertical
J_5: IMU_INT1; PinHeader_1x02_P2.54mm_Vertical
J_6: IMU_SCL; PinHeader_1x02_P2.54mm_Vertical
J_7: IMU_SDA; PinHeader_1x02_P2.54mm_Vertical
J_CN_1, J_CN_2: Header_Pin_4; PinHeader_1x04_P2.54mm_Vertical
J_CN_3, J_CN_4: Header_Pin_1; PinHeader_1x01_P2.54mm_Vertical
J_PW_1, J_PW_2: Header_Pin_2; PinHeader_1x02_P2.54mm_Vertical
J_PW_3: Header_Pin_1; PinHeader_1x01_P2.54mm_Vertical
LED_ESP_1: LED; LED_0603_1608Metric
L_PW_1: 4.7uH; CV201210-4R7K
Q_PW_1: IRLML5103TRPBF
R_ESP_1, R_ESP_3, R_ESP_5: 500; RESC1508X55N
R_ESP_2, R_ESP_4: 10k; RESC1608X55N
R_IMU_1, R_IMU_2: 4.7k; RESC1608X55N
R_PW_1: 10k; RESC1608X55N
R_PW_2, R_PW_3: 100k; RESC1608X55N
R_PW_4: 115k; RESC1608X55N
SW_ESP_1, SW_ESP_2: PTS647SK38SMTR2LFS
U_CN_1: USB4110-GF-A
U_ESP_1: ESP32-WROOM-32D; ESP32-WROOM-32
U_IMU_1: LSM6DSMTR
U_PW_1: MAX25276ATCA_VY+; MAX25276ATCAVY

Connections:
+3V3: CP_ESP_1.1, C_IMU_1.1, C_IMU_2.1, C_IMU_3.1, D_PW_3.C, J_1.2, J_2.17, J_3.5, J_PW_3.1, R_ESP_2.1, R_ESP_4.2, R_IMU_1.2, R_IMU_2.1, U_ESP_1.2, U_IMU_1.5, U_IMU_1.8, U_IMU_1.12
+BATT: J_PW_1.1, Q_PW_1.2
/ESP32 Chip/ESP32_EN: C_ESP_1.1, J_1.3, SW_ESP_1.3, U_ESP_1.3
/ESP32 Chip/ESP32_Pin4: J_1.4, U_ESP_1.4
/ESP32 Chip/ESP32_Pin5: J_1.5, U_ESP_1.5
/ESP32 Chip/ESP32_Pin6: J_1.6, U_ESP_1.6
/ESP32 Chip/ESP32_Pin7: J_1.7, U_ESP_1.7
/ESP32 Chip/ESP32_Pin8: J_1.8, U_ESP_1.8
/ESP32 Chip/ESP32_Pin9: J_1.9, U_ESP_1.9
/ESP32 Chip/ESP32_Pin10: J_1.10, U_ESP_1.10
/ESP32 Chip/ESP32_Pin11: J_1.11, J_4.1, U_ESP_1.11
/ESP32 Chip/ESP32_Pin12: J_1.12, J_5.2, U_ESP_1.12
/ESP32 Chip/ESP32_Pin13: J_1.13, J_6.1, U_ESP_1.13
/ESP32 Chip/ESP32_Pin14: J_1.14, J_7.2, U_ESP_1.14
/ESP32 Chip/ESP32_Pin16: J_1.16, U_ESP_1.16
/ESP32 Chip/ESP32_Pin17: J_3.1, U_ESP_1.17
/ESP32 Chip/ESP32_Pin18: J_3.2, U_ESP_1.18
/ESP32 Chip/ESP32_Pin19: J_3.3, U_ESP_1.19
/ESP32 Chip/ESP32_Pin20: J_3.6, U_ESP_1.20
/ESP32 Chip/ESP32_Pin21: J_3.7, U_ESP_1.21
/ESP32 Chip/ESP32_Pin22: J_3.8, U_ESP_1.22
/ESP32 Chip/ESP32_Pin23: J_2.16, U_ESP_1.23
/ESP32 Chip/ESP32_Pin24: J_2.15, R_ESP_3.1, U_ESP_1.24
/ESP32 Chip/ESP32_Pin25: J_2.14, SW_ESP_2.4, U_ESP_1.25
/ESP32 Chip/ESP32_Pin26: J_2.13, U_ESP_1.26
/ESP32 Chip/ESP32_Pin27: J_2.12, U_ESP_1.27
/ESP32 Chip/ESP32_Pin28: J_2.11, U_ESP_1.28
/ESP32 Chip/ESP32_Pin29: J_2.10, U_ESP_1.29
/ESP32 Chip/ESP32_Pin30: J_2.9, U_ESP_1.30
/ESP32 Chip/ESP32_Pin31: J_2.8, U_ESP_1.31
/ESP32 Chip/ESP32_Pin33: J_2.6, U_ESP_1.33
/ESP32 Chip/ESP32_Pin36: J_2.3, U_ESP_1.36
/ESP32 Chip/ESP32_Pin37: J_2.2, U_ESP_1.37
/ESP32 Chip/ESP32_RX0: J_2.5, U_ESP_1.34
/ESP32 Chip/ESP32_TX0: J_2.4, U_ESP_1.35
/IMU/IMU_INT1: J_5.1, U_IMU_1.4
/IMU/IMU_INT2: J_4.2, U_IMU_1.9
/IMU/IMU_SCL: J_6.2, R_IMU_1.1, U_IMU_1.13
/IMU/IMU_SDA: J_7.1, R_IMU_2.2, U_IMU_1.14
/IMU/IMU_SDO_SAO: J_1.17, U_IMU_1.1
GND: CP_ESP_1.2, C_ESP_1.2, C_IMU_1.2, C_IMU_2.2, C_IMU_3.2, C_PW_1.1, C_PW_2.2, C_PW_3.1, C_PW_5.2, J_1.1, J_1.19, J_2.1, J_2.20, J_3.4, J_CN_4.1, J_PW_2.1, LED_ESP_1.1, R_ESP_1.2, R_ESP_5.2, R_PW_1.2, R_PW_2.1, R_PW_3.1, U_CN_1.A1/B12, U_CN_1.B1/A12, U_CN_1.S1, U_CN_1.S2, U_CN_1.S3, U_CN_1.S4, U_ESP_1.1, U_ESP_1.15, U_ESP_1.38, U_ESP_1.39, U_IMU_1.2, U_IMU_1.3, U_IMU_1.6, U_IMU_1.7, U_PW_1.6, U_PW_1.7, U_PW_1.13
unnamed: C_PW_2.1, U_PW_1.4
unnamed: C_PW_3.2, U_PW_1.10
unnamed: C_PW_4.1, L_PW_1.2, U_PW_1.5
unnamed: C_PW_4.2, U_PW_1.3
unnamed: C_PW_5.1, D_PW_3.A, L_PW_1.1, R_PW_4.1, U_PW_1.9
unnamed: D_PW_1.C, D_PW_2.A, Q_PW_1.3
unnamed: J_CN_1.1, U_CN_1.B5
unnamed: J_CN_1.2, U_CN_1.A8
unnamed: J_CN_1.3, U_CN_1.B6
unnamed: J_CN_1.4, U_CN_1.A7
unnamed: J_CN_2.1, U_CN_1.A6
unnamed: J_CN_2.2, U_CN_1.B7
unnamed: J_CN_2.3, U_CN_1.A5
unnamed: J_CN_2.4, U_CN_1.B8
unnamed: LED_ESP_1.2, R_ESP_3.2
unnamed: R_ESP_1.1, SW_ESP_1.2
unnamed: R_ESP_2.2, SW_ESP_1.4
unnamed: R_ESP_4.1, SW_ESP_2.3
unnamed: R_ESP_5.1, SW_ESP_2.1
unnamed: R_PW_2.2, R_PW_3.2, R_PW_4.2, U_PW_1.8
VDD: C_PW_1.2, D_PW_2.C, J_1.20, J_PW_2.2, U_PW_1.2
VS: D_PW_1.A, J_2.19, J_CN_3.1, J_PW_1.2, Q_PW_1.1, R_PW_1.1, U_CN_1.A4/B9, U_CN_1.B4/A9

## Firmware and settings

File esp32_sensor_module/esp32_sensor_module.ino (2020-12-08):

/**
   ESP32 Sensor Module

   ESP32 Datasheet: https://www.espressif.com/sites/default/files/documentation/esp32-wroom-32_datasheet_en.pdf
   IMU Library Reference: https://github.com/arduino-libraries/Arduino_LSM6DS3/blob/master/src/LSM6DS3.cpp
   IMU Datasheet: https://www.st.com/content/ccc/resource/technical/document/datasheet/76/27/cf/88/c5/03/42/6b/DM00218116.pdf/files/DM00218116.pdf/jcr:content/translations/en.DM002181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
   ESP-NOW and WiFi:
    https://randomnerdtutorials.com/esp-now-two-way-communication-esp32/
    https://randomnerdtutorials.com/esp-now-esp32-arduino-ide/
    https://gist.github.com/futechiot/ee0223dd269cbe7d8605ce97d120d7d2
*/

/**
   Metadata
*/
#define SW_VERSION "0.0.1"
#define HW_VERSION "0.0.3b"

/**
   Flags
*/
//#define DEMO // Comment this out for production

/**
   Libraries
*/
#include <WiFi.h>
#include "Wire.h" // ESP32 Wire.h
#include <esp_wifi.h>
#include <esp_now.h>

/**
   ESP32 Pins
*/
#define IMU_INT2      26 // Pin 11
#define IMU_INT1      27 // Pin 12  
#define IMU_SCL       14 // Pin 13
#define IMU_SDA       12 // Pin 14
//#define IMU_SD0       // Not implemented

/**
   LSM Registers
*/
#define LSM6DSM_ADDRESS             0x6B // SD0 should not be connected

#define LSM6DSM_WHO_AM_I_REG        0X0F
#define WHO_AM_I_REG_VALUE          0x6A

#define LSM6DSM_CTRL1_XL            0X10
#define LSM6DSM_CTRL2_G             0X11
#define LSM5DSM_CTRL3_C             0X12

#define LSM6DSM_STATUS_REG          0X1E

#define LSM6DSM_CTRL6_C             0X15
#define LSM6DSM_CTRL7_G             0X16
#define LSM6DSM_CTRL8_XL            0X17

#define LSM6DSM_OUTX_L_G            0X22
#define LSM6DSM_OUTX_H_G            0X23
#define LSM6DSM_OUTY_L_G            0X24
#define LSM6DSM_OUTY_H_G            0X25
#define LSM6DSM_OUTZ_L_G            0X26
#define LSM6DSM_OUTZ_H_G            0X27

#define LSM6DSM_OUTX_L_XL           0X28
#define LSM6DSM_OUTX_H_XL           0X29
#define LSM6DSM_OUTY_L_XL           0X2A
#define LSM6DSM_OUTY_H_XL           0X2B
#define LSM6DSM_OUTZ_L_XL           0X2C
#define LSM6DSM_OUTZ_H_XL           0X2D

/**
   Structures
*/
// IMU Msg Data
typedef struct IMU_MSG {
  String msgID = "6DOF";
  //  char[10] sensorModuleMACAddress;

  float accX;
  float accY;
  float accZ;

  float gyroX;
  float gyroY;
  float gyroZ;

  float temperature;
};

/**
   Constants
*/
#define SERIAL_BAUD_RATE            115200
#define ESP32_WIFI_MODE             WIFI_STA
#define NETWORK_SCAN_REST_INTERVAL  5000 // Rest before scan again
#define NETWORK_CONNECT_ATTEMPTS    3

#define READER_WIFI_SSID            "CANnect_Reader_WiFi_0.1"   // SSID of reader WiFi
#define READER_WIFI_PASSWORD        "redboats"                  // Password of reader WiFi
#define READER_WIFI_CHANNEL         14

#ifdef DEMO
#define SCALING_FACTOR         10                          // Scales the data for demo purposes
#else
#define SCALING_FACTOR         1
#endif

uint8_t sensorMACAddress[] = {0xF0, 0x08, 0xD1, 0xD3, 0x6D, 0xA0}; // sensor's address - hard-coded for now
uint8_t readerMACAddress[] = {0xF0, 0x08, 0xD1, 0xD3, 0x6D, 0xA1}; // reader's address - hard-coded for now

/**
   Variables
*/
esp_now_peer_info_t readerInfo;

void setup() {
  Serial.begin(SERIAL_BAUD_RATE);
  Serial.println("Wait for user to be ready");
//  while (true) {
//
//    if (Serial.available() > 0) {
//      if (Serial.read() == 'G') {
//        break;
//      }
//    }
//  }

  imuSetup();
  wifiSetup();
  espNOWSetup();
}

void imuSetup(void) {
  Wire.begin(IMU_SDA, IMU_SCL);

  while (readRegister(LSM6DSM_WHO_AM_I_REG) != WHO_AM_I_REG_VALUE) {
    Serial.println("Unable to talk to IMU! Trying again!");
    delay(1000);
  }

  /**
     Taken from LSM library
  */
  //set the gyroscope control register to work at 104 Hz, 2000 dps and in bypass mode
  writeRegister(LSM6DSM_CTRL2_G, 0x4C);

  // Set the Accelerometer control register to work at 104 Hz, 4G,and in bypass mode and enable ODR/4
  // low pass filter(check figure 9 on LSM6DSM's datasheet)
  writeRegister(LSM6DSM_CTRL1_XL, 0x4A); // I think this is correct??

  // set gyroscope power mode to high performance and bandwidth to 16 MHz
  writeRegister(LSM6DSM_CTRL7_G, 0x00);

  // Set the ODR config register to ODR/4
  writeRegister(LSM6DSM_CTRL8_XL, 0xA4); // I think this is correct??

  Serial.println("IMU ready");
}

void wifiSetup(void) {
  WiFi.mode(ESP32_WIFI_MODE);
  esp_wifi_set_mac(ESP_IF_WIFI_STA, &sensorMACAddress[0]); // temporarily

  Serial.println(WiFi.macAddress());
}

void espNOWSetup(void) {
  if (esp_now_init() != ESP_OK) {
    Serial.println("Error initializing ESP-NOW");
    return;
  }

  esp_now_register_send_cb(OnDataSent);
}

int writeRegister(uint8_t address, uint8_t value)
{
  Wire.beginTransmission(LSM6DSM_ADDRESS);
  Wire.write(address);
  Wire.write(value);
  if (Wire.endTransmission() != 0) {
    return 0;
  }

  return 1;
}

int readRegister(uint8_t address) {
  uint8_t value;

  if (readRegisters(address, &value, sizeof(value)) != 1) {
    return -1;
  }

  return value;
}

int readRegisters(uint8_t address, uint8_t* data, size_t length) {
  Wire.beginTransmission(LSM6DSM_ADDRESS);
  Wire.write(address);

  if (Wire.endTransmission(false) != 0) {
    return -1;
  }

  if (Wire.requestFrom(LSM6DSM_ADDRESS, length) != length) {
    return 0;
  }

  for (size_t i = 0; i < length; i++) {
    *data++ = Wire.read();
  }

  return 1;
}

int gyroscopeAvailable() {
  if (readRegister(LSM6DSM_STATUS_REG) & 0x02) {
    return 1;
  }

  return 0;
}

int accelerationAvailable() {
  if (readRegister(LSM6DSM_STATUS_REG) & 0x01) {
    return 1;
  }

  return 0;
}

int readGyroscope(float& x, float& y, float& z) {
  int16_t data[3];

  if (!readRegisters(LSM6DSM_OUTX_L_G, (uint8_t*)data, sizeof(data))) {
    x = NAN;
    y = NAN;
    z = NAN;

    return 0;
  }

  x = SCALING_FACTOR * data[0] * 2000.0 / 32768.0;
  y = SCALING_FACTOR * data[1] * 2000.0 / 32768.0;
  z = SCALING_FACTOR * data[2] * 2000.0 / 32768.0;

  return 1;
}

int readAcceleration(float& x, float& y, float& z) {

  int16_t data[3];

  if (!readRegisters(LSM6DSM_OUTX_L_XL, (uint8_t*)data, sizeof(data))) {
    x = NAN;
    y = NAN;
    z = NAN;

    return 0;
  }

  x = SCALING_FACTOR * data[0] * 4.0 / 32768.0;
  y = SCALING_FACTOR * data[1] * 4.0 / 32768.0;
  z = SCALING_FACTOR * data[2] * 4.0 / 32768.0;

  return 1;
}

int readTemperature(float& temp) {
  temp = 0.0; // not implemented yet

  return 1;
}

char* convert_int16_to_str(int i) { // converts int16 to string. Moreover, resulting strings will have the same length in the debug monitor.
  char tmp_str[7];
  sprintf(tmp_str, "%6d", i);
  return tmp_str;
}

// Callback when data is sent
void OnDataSent(const uint8_t *mac_addr, esp_now_send_status_t status) {
  Serial.print("\r\nLast Packet Send Status:\t");
  Serial.println(status == ESP_NOW_SEND_SUCCESS ? "Delivery Success" : "Delivery Fail");

  Serial.print("Mac: ");
  Serial.print(mac_addr[0], HEX);
  Serial.print(mac_addr[1], HEX);
  Serial.print(mac_addr[2], HEX);
  Serial.print(mac_addr[3], HEX);
  Serial.print(mac_addr[4], HEX);
  Serial.print(mac_addr[5], HEX);
  Serial.println("");
}

/**
   Wait forever for connection to reader
*/
void waitForConnectionToReader(void) {
  bool success = false;
  //
  //  while (!success) {
  //    int numNetworks = WiFi.scanNetworks();
  //    Serial.println("Waiting for Reader");
  //    delay(NETWORK_SCAN_REST_INTERVAL);
  //
  //    if (numNetworks != 0) {
  //      for (int ii = 0; ii < numNetworks; ++ii) {
  //        if (WiFi.SSID(ii) == READER_WIFI_SSID) {
  //          success = connectToReader(WiFi.BSSID(ii));
  //        }
  //      }
  //    }
  //  }

  // temporary
  success = connectToReader(&readerMACAddress[0]);

  if (success) {
    Serial.println("Successfully connected to reader");
  }
}

bool connectToReader(const uint8_t *mac) {
  //  int numAttempts = 0;
  //  Serial.println("Found reader!");
  //  WiFi.begin(READER_WIFI_SSID, READER_WIFI_PASSWORD);
  //  Serial.print("Attempting to connect to Reader");
  //
  //  do {
  //    delay(500);
  //    numAttempts++;
  //    Serial.print(".");
  //  } while (WiFi.status() != WL_CONNECTED && numAttempts < NETWORK_CONNECT_ATTEMPTS);
  //  Serial.println(".");
  //
  //  if (WiFi.status() != WL_CONNECTED) {
  //    Serial.println("Unable to connect to Reader");
  //    return false;
  //  }

  return espNOWAddReader(mac);
}

/**
   Register and add reader
*/
bool espNOWAddReader(const uint8_t *readerMacAddress) {
  memcpy(readerInfo.peer_addr, readerMacAddress, 6);
  readerInfo.channel = READER_WIFI_CHANNEL;
  readerInfo.encrypt = false;

  // Add peer
  if (esp_now_add_peer(&readerInfo) != ESP_OK) {
    Serial.println("Failed to add peer");
    return false;
  }

  Serial.print("Reader mac address is: ");
  Serial.print(readerInfo.peer_addr[0], HEX);
  Serial.print(readerInfo.peer_addr[1], HEX);
  Serial.print(readerInfo.peer_addr[2], HEX);
  Serial.print(readerInfo.peer_addr[3], HEX);
  Serial.print(readerInfo.peer_addr[4], HEX);
  Serial.print(readerInfo.peer_addr[5], HEX);
  Serial.println("");

  return true;
}

/**
   Remove reader
*/
void espNOWRemoveReader(void) {
  if (!esp_now_is_peer_exist(readerInfo.peer_addr)) {
    Serial.println("Unable to find reader to delete! Something went wrong!");
    return;
  }

  if (esp_now_del_peer(readerInfo.peer_addr) != ESP_OK) {
    Serial.println("Failed to delete peer gracefully");
    return;
  }
}

void sendIMUMsg(void) {
  IMU_MSG imuMsg;
  imuMsg.msgID = "6DOF";

  bool goodData = true;
  Serial.println("Obtaining data...");

  if (readAcceleration(imuMsg.accX, imuMsg.accY, imuMsg.accZ) == 0) {
    goodData = false;
    Serial.println("No acceleration data!");
  }

  if (readGyroscope(imuMsg.gyroX, imuMsg.gyroY, imuMsg.gyroZ) == 0) {
    goodData = false;
    Serial.println("No gyroscope data!");
  }

  if (readTemperature(imuMsg.temperature) == 0) {
    Serial.println("No temperature data!");
    goodData = false;
  }

  if (goodData && esp_now_is_peer_exist(readerInfo.peer_addr)) {
    esp_err_t result = esp_now_send(readerInfo.peer_addr, (uint8_t *) &imuMsg, sizeof(imuMsg));
  }
}

void loop() {
  if (esp_now_is_peer_exist(readerInfo.peer_addr)) {
    sendIMUMsg();
  }

  else {
    waitForConnectionToReader();
  }

  delay(200);
}

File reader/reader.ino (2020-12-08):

/**
   ESP32 - Responsible to transmit to Bluetooth devices

   References:
   https://github.com/espressif/arduino-esp32/tree/master/libraries/BluetoothSerial
   https://github.com/espressif/arduino-esp32/tree/master/libraries/SPI
*/

/**
   Metadata
*/
#define SW_VERSION "0.0.1"
#define HW_VERSION "0.0.5b"
#define ESP32_BL_NAME "CANnectReader"

/**
   Flags
   Change this depending on hardware/version setup
*/
#define STN_CHIP_CONNECTED // comment this out if you're not connected to the STN chip

/**
   Libraries
*/
#include "BluetoothSerial.h"
#include <WiFi.h>
#include <esp_wifi.h>
#include <esp_now.h>

/**
   ESP32 Pins
*/
#define ESP32_BLUETOOTH_LED_PIN     22
#define ESP32_OBD_ACT_LED_PIN       23

#define ESP32_RX_STN_PIN            17 // STN to ESP32
#define ESP32_TX_STN_PIN            16 // ESP32 to STN

#define ESP32_IMU_SCL               14 // Pin13               
#define ESP32_IMU_SDA               12 // Pin14 
#define ESP32_IMU_INT2              26 // Pin11 
#define ESP32_IMU_INT1              27 // Pin12 
//#define ESP32_IMU_SDO_SAO           13 // Pin16 - Unlikely to use

/**
   Structures
*/

// IMU Msg Data
typedef struct IMU_MSG {
  String msgID = "6DOF";
  //  char[10] sensorModuleMACAddress;

  float accX;
  float accY;
  float accZ;

  float gyroX;
  float gyroY;
  float gyroZ;

  float temperature;
};

/**
   Constants
*/
#define MESSAGE_INTERVAL          1000 // 1000 ms
#define MESSAGE_DELAY             20
#define BAUD_RATE                 115200
#define STN_BAUD_RATE             9600
#define SETUP_DELAY               100
#define INITIALISATION_ATTEMPTS   5
#define MESSAGE_END               0xFF
#define ESP32_WIFI_MODE           WIFI_AP_STA

#define READER_WIFI_SSID          "CANnect_Reader_WiFi_0.1"   // SSID of reader WiFi
#define READER_WIFI_PASSWORD      "redboats"                  // Password of reader WiFi
#define READER_WIFI_CHANNEL       14

uint8_t sensorMACAddress[] = {0xF0, 0x08, 0xD1, 0xD3, 0x6D, 0xA0}; // sensor's address - hard-coded for now
uint8_t readerMACAddress[] = {0xF0, 0x08, 0xD1, 0xD3, 0x6D, 0xA1}; // reader's address - hard-coded for now

/**
   Global Variables
*/
bool readyForData = false;
BluetoothSerial SerialBT;
String success;

float accX, accY, accZ;
float gyroX, gyroY, gyroZ;
float temperature;
boolean protocolFlag = false;
char c43[] = "43";
char error[] = "ERROR";
char noData[] = "NO DATA";
const byte numChars = 32;
char charArray[numChars];
char protocolArray[numChars];
int iso9141Delay = 100; // imperically defined
String str1 = "";
unsigned long programStarted = 0;
const long interval = 500;
boolean readerConnected = false;

/**
   Setup
*/
void setup() {
  pinMode(ESP32_BLUETOOTH_LED_PIN, OUTPUT); // Red LED - Bluetooth
  pinMode(ESP32_OBD_ACT_LED_PIN, OUTPUT); // Green LED - OBD-II activitiy

  digitalWrite(ESP32_BLUETOOTH_LED_PIN, LOW);
  digitalWrite(ESP32_OBD_ACT_LED_PIN, LOW);
  Serial.begin(BAUD_RATE);

  setupReader();
  setupBluetooth();


  while (!Serial2) {
    Serial.println("Connect to the reader");
  }

  waitForBluetoothConnection();
  initialiseReaderConnection();


  while (!readerConnected) {
    ;
  }
  setupWiFi();
  setupESPNow();

  delay(1000);
  //  connectSensorModules();
  Serial.println("Ready");
  readyForData = true;
}

/**
   Loop
*/
void loop() {
  unsigned long currentMillis = millis();

  if (currentMillis - programStarted >= interval) {
    receivedFromApp();
    programStarted = currentMillis;
    //generateSampleIMUMsg();
  }
}

/**
   WiFi Setup
*/
void setupWiFi(void) {
  WiFi.mode(ESP32_WIFI_MODE);
  esp_wifi_set_mac(ESP_IF_WIFI_STA, &readerMACAddress[0]); // temporarily

  Serial.println(WiFi.macAddress());
}


/**
   ESP-NOW Setup
*/
void setupESPNow(void) {
  // Init ESP-NOW
  if (esp_now_init() != ESP_OK) {
    Serial.println("Error initializing ESP-NOW");
    return;
  }

  // Register peer
  esp_now_peer_info_t peerInfo;
  memcpy(peerInfo.peer_addr, sensorMACAddress, 6);
  peerInfo.channel = READER_WIFI_CHANNEL;
  peerInfo.encrypt = false;

  // Add peer
  if (esp_now_add_peer(&peerInfo) != ESP_OK) {
    Serial.println("Failed to add peer");
    return;
  }

  // Register for a callback function that will be called when data is received
  esp_now_register_recv_cb(OnDataRecv);
  Serial.println("ESP-NOW initialised");
}

/**
   Bluetooth Setup
*/
void setupBluetooth(void) {
  SerialBT.begin(ESP32_BL_NAME); //Bluetooth device name
  Serial.println("The device started, now you can pair it with bluetooth!");
}

void setupReader(void) {
  Serial2.begin(STN_BAUD_RATE, SERIAL_8N1, ESP32_RX_STN_PIN, ESP32_TX_STN_PIN);
}

//void receiveFromBluetooth(void) {
//  if (SerialBT.available()) {
//    Serial.print("Data from Bluetooth device: ");
//
//    long unsigned int buf[64];
//    int ii = 0;
//    while (SerialBT.available()) {
//      Serial.print(convertUint8ToChar(SerialBT.read()));
//      delay(MESSAGE_DELAY);
//    }
//
//    Serial.println(" ");
//  }
//}

void waitForBluetoothConnection(void) {
  while (!SerialBT.available()) {
    digitalWrite(ESP32_BLUETOOTH_LED_PIN, HIGH);
    delay(500);
    digitalWrite(ESP32_BLUETOOTH_LED_PIN, LOW);
    delay(500);
    Serial.println("pair up the BT");
  }
  digitalWrite(ESP32_BLUETOOTH_LED_PIN, HIGH);
}

void initialiseReaderConnection(void) {
#ifndef STN_CHIP_CONNECTED
  // Do not search for protocol if not connected to STN chip
  protocolFlag = true;
#endif

  while (!protocolFlag) {
    findCorrectProtocol();
    flushBuffers();
    if (str1 == "22") {
      Serial2.println("01 0D");
      iso9141Delay = 500;
      delay(iso9141Delay);
    }
  }
}

uint8_t convertCharToUint8(char* string) {
  return (uint8_t)atoi(string);
}

char convertUint8ToChar(int number) {
  return (char)number;
}

// Callback when data is sent
void OnDataSent(const uint8_t *mac_addr, esp_now_send_status_t status) {
  Serial.print("\r\nLast Packet Send Status:\t");
  Serial.println(status == ESP_NOW_SEND_SUCCESS ? "Delivery Success" : "Delivery Fail");
  if (status == 0) {
    success = "Delivery Success :)";
  }
  else {
    success = "Delivery Fail :(";
  }
}
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

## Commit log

2020-07-18 Progress Review Meeting II PowerPoint Presentation
2020-07-21 Test commit and push without building and compiling and without a device.
2020-08-12 Added Arduino code
2020-08-15 - Back button with title bar fixed and re-implemented. - Main connection status bug fixed.
2020-08-16 Fixed several bugs. Cleaned up code. Prepared Arduino software for presentation purposes
    [arduino.ino, reader.ino]
2020-08-19 Change CAN Bus to attempt initialisation before giving up
2020-08-19 Fixed bugs related to Serial communication
    [reader.ino]
2020-08-30 Removed old play-services dependencies for version 11, updated AndroidManifest.xml, style.xml, and fixed back button with the title bar and finally fixed connect layout.
    [Dashboard_chart.java]
2020-09-04 Two threading issue and register/unregister receiver issue are fixed.
2020-09-11 Added a Bluetooth ESP32 simulator
2020-09-12 Initial commit of AppSeptember, adding settings.
    [ic_touch_app.xml]
2020-09-13 Combined codes of line chart and gauge, fixed unregisterReceiver.
    [Dashboard_chart.java]
2020-09-22 Main connection status related to device completed. Socket closing after turning off the bluetooth fixed.
2020-09-22 implemented context menu gauges
    This implementation allowed user to switch between different gagues display. More gauges to be added on later
2020-10-02 Added ESP_NOW feature to reader. Added code for sensor module
2020-10-05 Changed chart page which allow a user to see on PID at a time.
2020-10-12 Added 2 new PID(fragments) for gauge display.
2020-10-12 Started work on designing reader schematic with STN 2120
    [Reader.kicad_pcb, Reader.sch]
2020-10-16 Current state of sensor components, LSM6DSLTR, ESP32-WROOM-32
2020-10-16 ESP32 development kit module
2020-10-19 Revised initial schematics for hierarhical structure. Added ESP32, 'Power Supply', Reader MEMs and Power Switch. OBD-II Interpreter is work-in-progress
    [Reader.sch, obd_transceivers.sch, obdii.sch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]
2020-10-20 Completed schematics for reader
    [Reader.kicad_pcb, Reader.sch, obd_connector.sch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]
2020-10-22 Updated settings, firebase in map activity, and fixing the crash case of sending messages (3 characters case and float conversion in chart).
    [CarBrand.java, Dashboard_chart.java]
2020-10-22 Completed Reader schematics for version 0.0.01
    [Reader.kicad_pcb, Reader.sch, host.sch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]
2020-10-22 Minor changes to schematic design for clarity. Added important IC datasheets. Exported schematics and rough gerber files
    [Reader-B_Cu.gbr, Reader-B_Mask.gbr, Reader-B_Paste.gbr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]
2020-10-26 Added ESD Protection. Fixed minor bugs on schematic. Attempted placement of components
    [Reader-B_Cu.gbr, Reader-B_Mask.gbr, Reader-B_Paste.gbr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]
2020-10-26 Removed BOM rule. Added BOM-related files. Updated libraries. Removed unneeded files
    [Reader_bom_0.0.03.csv]
2020-10-26 Fixed bugs on the reader schematic. Exported Schematic Electrical report
    [Reader-B_Cu.gbr, Reader-B_Mask.gbr, Reader-B_Paste.gbr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]
2020-10-27 Changed resistor divider for VR2 for cheaper resistors
    [Reader.kicad_pcb, Reader_bom_0.0.03.csv, obdii_interpreter.sch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]
2020-10-27 Fixed wiring issue on ESD Protection
    [Reader.kicad_pcb, Reader.sch, esd_protection.sch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]
2020-10-27 Fixed minor bugs in schematic. Completed PCB layout v0.0.1 and exported Gerber files
    [Reader-B_Adhes.gbr, Reader-B_CrtYd.gbr, Reader-B_Cu.gbr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]
2020-10-27 Addressed Design Rules problems
    [Reader-B_Adhes.gbr, Reader-B_CrtYd.gbr, Reader-B_Cu.gbr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]
2020-10-28 Fixed bugs in schematic. Updated BOM list. Swapped to using ESP32 holder. Updated PCB layout to v0.0.2. Updated schematic to v0.0.4
    [Reader-B_Adhes.gbr, Reader-B_CrtYd.gbr, Reader-B_Cu.gbr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]
2020-10-28 Fixed positions of components. Fixed silkscreen titles of components
    [Reader-B_Adhes.gbr, Reader-B_CrtYd.gbr, Reader-B_Cu.gbr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]
2020-10-28 Made minor adjustments to PCB layout
    [Reader-B_Adhes.gbr, Reader-B_CrtYd.gbr, Reader-B_Cu.gbr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]
2020-10-28 Re-exported gerber files
    [Reader-B_Adhes.gbr, Reader-B_CrtYd.gbr, Reader-B_Cu.gbr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]
2020-10-29 Cleaned up a few sections for manufacturing
    [Reader-B_Adhes.gbr, Reader-B_CrtYd.gbr, Reader-B_Cu.gbr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]
2020-10-29 Fixed minor Silkscreen details. Updated .gitignore to ignore report files. Exported gerber files. Updated PCB layout to v0.0.3
    [Reader-B_Adhes.gbr, Reader-B_CrtYd.gbr, Reader-B_Cu.gbr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]
2020-10-29 Updated version number for front silkscreen
    [Reader-B_Adhes.gbr, Reader-B_CrtYd.gbr, Reader-B_Cu.gbr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]
2020-10-30 Sensor Schematic
    [Sensor.sch]
2020-10-30 Footprint libraries
2020-10-30 6Dof Sensor footprint
2020-10-30 ESP32_Dev Footprint
2020-10-30 Schematic symbols library
2020-10-30 Buck Converter schematic library
2020-10-30 ESP32-WROOM-32-Dev schematic library
2020-11-01 Fixed a component name for header pin
    [Reader-B_Adhes.gbr, Reader-B_CrtYd.gbr, Reader-B_Cu.gbr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]
2020-11-18 Receiver (ESP32)
2020-11-19 Revising reader
    [Reader.sch, esd_protection.sch, host.sch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]
2020-11-23 Fixed numerous bugs in design for Reader Schematic and PCB
    [Reader.sch, Reader_bom_0.0.04.csv, host.sch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]
2020-11-23 Added ESP32 Schematic and PCB design
    [battery.sch, connector.sch, connnector.sch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]
2020-11-25 Updated schematic and PCB design to v0.0.2 for 2-layer PCB. Added more silkscreen text
    [connnector.sch, esp32_chip.sch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]
2020-11-25 Updated sensor module to v0.0.3. Fixed USB design flaw. Moved polarised capacitor towards inside of the board. Updated via sizes
    [connnector.sch, esp32_chip.sch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]
2020-11-25 Updated silkscreen. Moved silkscreen of header pins to the bottom of PCB
    [esp32_sensor-B_Cu.gbr, esp32_sensor-B_Mask.gbr, esp32_sensor-B_Paste.gbr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]
2020-11-25 Updated PCB to v0.0.3b. Fixed tracks and silkscreen
    [esp32_sensor-B_Adhes.gbr, esp32_sensor-B_CrtYd.gbr, esp32_sensor-B_Cu.gbr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]
2020-11-27 Fixed a bug in data processing of sensor data.
    [reader.ino]
2020-11-28 Updated reader schematic to v0.0.5 by adding ESP32, removing unused transceivers, fixed design flaws, increased header pins and fixed footprints. Working on reader PCB design
    [ESP32.sch, Reader.kicad_pcb, Reader.sch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]
2020-11-28 Revert "Fixed a bug in data processing of sensor data."
    This reverts commit 4c9e5f86
    [reader.ino]
2020-11-30 Revert "Implemented simultaneous PIDs request up to 5(table page), 4(gauge page)."
    This reverts commit 915d3441
    [CarBrand.java]
2020-11-30 Updated schematic and gerber to v0.0.05. Added ESP32. Removed MS CAN and SW CAN Transceivers. Added silkscreen text to header pins. Improved readability
    [ESP32.sch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]
2020-12-03 Changed capacitor part number for reader
    [Reader_bom_0.0.05.csv, transceiver_can_hs.sch]
2020-12-03 Started working on ESP32 Sensor Module
2020-12-03 Converted PCB design into a 2-layer PCB for v0.0.5b. Adjusted schematic to use header pins for connector
    [ESP32.sch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]
2020-12-03 Added keep-out area to ESP32 antenna. Updated silkscreen of Reader
    [Reader-B_Adhes.gbr, Reader-B_CrtYd.gbr, Reader-B_Cu.gbr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]
2020-12-03 Fixed compiling issues related to functions. Added hardware flags. Added IMU data structure as expected in app
    [esp32_sensor_module.ino, reader.ino]
2020-12-03 Cleaned up existing reader code for readability. Prepared helper functions for sensor module development for reader
2020-12-04 Update reader.ino randomized sensor values are sent to app.
2020-12-04 Remove unused code. Fixed ranges from generating sample IMUs
    [reader.ino]
2020-12-04 Fixed LEDs for reader
    [reader.ino]
2020-12-04 Enhanced styling in Dashboard, Dashboard_chart (not perfect yet). Fixed Gauge styling. Fixed Bottom navigation in chart, gauge.
    [Dashboard_chart.java]
2020-12-04 Implemented ESP-NOW for sensor module and reader
2020-12-04 Make changes so that the PIDs still display values after pressing home button.
2020-12-05 Implemented ESP-NOW functionality between reader and sensor module. Implemented demo flag for sensor module
2020-12-07 pitch&roll simulation added
2020-12-08 In Connect, issue of tapping Show Pair Devices button that will cause duplicate items have been fixed.

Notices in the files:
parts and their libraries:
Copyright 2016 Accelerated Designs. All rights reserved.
